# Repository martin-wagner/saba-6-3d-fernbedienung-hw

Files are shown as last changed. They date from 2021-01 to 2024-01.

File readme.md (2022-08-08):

### Saba Webradio

Das Saba Webradio erweitert ein Saba Automatic Radio um die folgenden Funktionen:
- W-Lan Webradio
- Steuerung von Automatik und Lautst"arke per Webinterface, MQTT, IR Fernbedienung ...
- Steuerung des Webradio per Radio Automatiktasten

Es kann direkt auf die Anschlussbuchse für die Fernbedienung aufgesteckt werden. Kompatibel sind mind. das Meersburg und Freiburg 6-3D. Am Gerät selbst sind keine Modifikationen notwendig (aber empfehlen). Der Audioausgang des Webradio wird mit dem TA Eingang des Radios verbunden und kann durch Wahl des zugehörigen Eingangs am Radio verwendet werden.

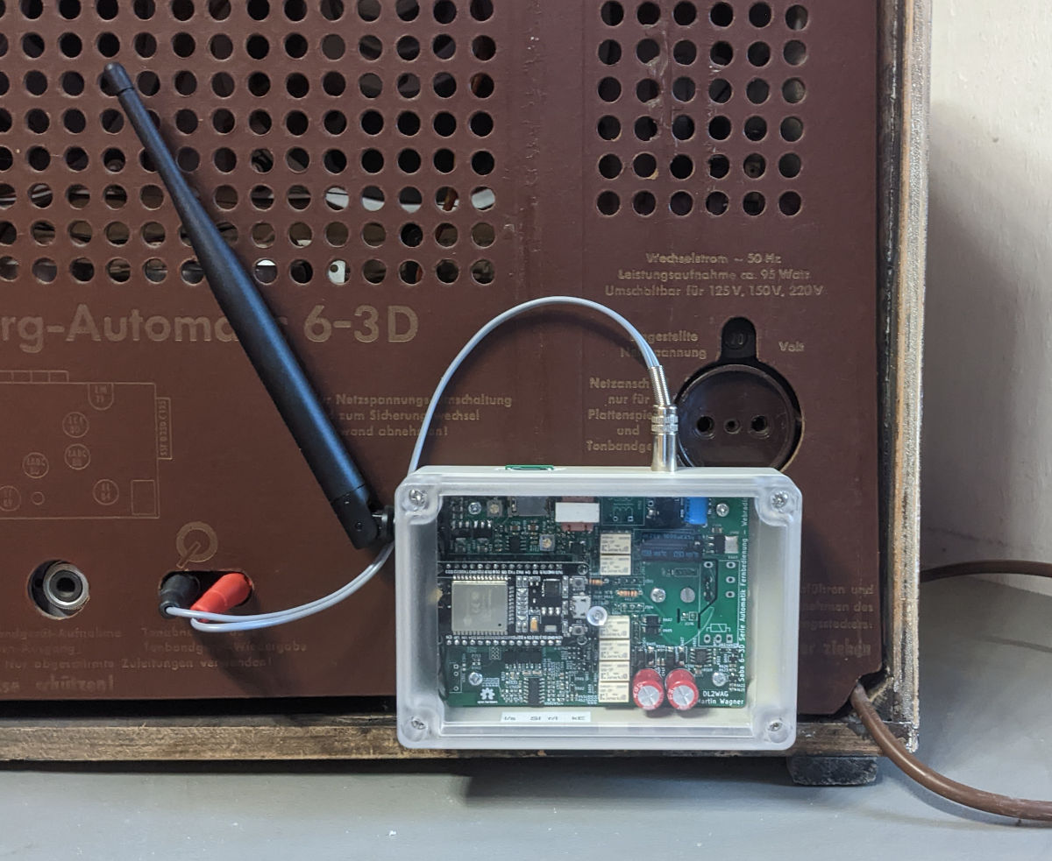
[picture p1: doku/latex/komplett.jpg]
Radio


Das Webradio basiert auf dem [ESP32-Radio Projekt von Ed Smallenburg](https://github.com/Edzelf/ESP32-Radio).

[Hardware](https://github.com/martin-wagner/saba-6-3d-fernbedienung-hw)

[Software](https://github.com/martin-wagner/ESP32-Radio)

[Doku](doku/latex/doku.pdf)

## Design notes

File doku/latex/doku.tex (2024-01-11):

\documentclass[ngerman,11pt,parskip=half] {scrartcl}

\usepackage{babel}

%
% Schrift
%
\usepackage[T1]{fontenc}
\usepackage{textcomp}
\usepackage[utf8]{inputenc}
\usepackage{eurosym}% 1 \euro oder \EUR{1}

\usepackage{helvet}
\renewcommand{\ttdefault}{pcr} %typewriter default font
\renewcommand{\familydefault}{\sfdefault}

%
% Layout
%
\usepackage[textwidth=16cm,head=4cm,bottom=3cm,a4paper]{geometry}
\usepackage{scrlayer-scrpage}
\pagestyle{scrheadings}
%\chead{}\ihead{}\ohead{}
\cfoot{}\ifoot{\footnotesize \currfilepath}\ofoot{\footnotesize Seite \pagemark~von \pageref*{LastPage}} % pageref* -> kein klickbarer Link
\renewcommand*{\footfont}{\normalfont}%nicht kursiv

\usepackage{lastpage}
\usepackage[table]{xcolor}
\usepackage{multicol}
\usepackage{rotating}
\usepackage{graphicx}
\usepackage{setspace}
\linespread{1.1}%zeilenabstand default global
\usepackage{array}
\usepackage{longtable}
\usepackage{ltxtable}
\setlength\LTleft{0pt}
\setlength\LTright\fill
\usepackage{tikz}
\usepackage{ctable}
\newcommand{\otoprule}{\midrule[\heavyrulewidth]}
\usepackage{hhline}
\usepackage{cals}
\usepackage{enumitem}% f"ur besseres itemize
\setitemize{label=\textminus,itemsep=0pt,topsep=0.5ex,after=\vspace{\baselineskip}}
\usepackage{float} %bilderpositionierung
%\usepackage{textgreek}
\usepackage{sansmath}
\usepackage{listings}
\lstset{basicstyle=\footnotesize\ttfamily,breaklines=true}
\lstset{framextopmargin=50pt,frame=bottomline}

% Funktion zum Generieren des Dateipfades. Kann leider nicht den absoluten Pfad finden...
\usepackage{currfile}

% Zeit
\usepackage{datetime}

%
% Funktionen
%
% fettes rotes todo
\newcommand {\todo} {\textbf{\color{red} todo\ }}
% Gr"o"se eines Oszillogramms
\newcommand {\tscopesize}{12cm}

% Links, Querverweise, Titel
\usepackage[
  colorlinks=true,
  linkcolor=black,
  urlcolor=black,
  pdftitle={Schaltungsbeschreibung}, %PDF Beschreibung
  allcolors=black,
]{hyperref} %immer zum Schluss

%
% Dokument
%
\begin{document}
\sansmath

% Titelseite

\thispagestyle{empty}

\mbox{}\\[2cm]%absolute L"ange

\textbf{\huge
Saba Webradio Hardware
}

\vfill

\hspace{1cm}\begin{tabular}{ll}
Autor: & 		Martin Wagner, DL2WAG\\
Dokumentart:&   Schaltungsbeschreibung, Messungen\\
Datum:&         \today \enspace \currenttime
\end{tabular}

\vfill
\begin{minipage}[t]{\textwidth}
\begin{spacing}{1.2}%zeilenabstand lokal 
  \begin{tabular}{p{.1\textwidth} p{.2\textwidth}  p{.6\textwidth}}%
  Version & Datum & Bemerkung        \\
  \hline  
  \hspace{.02\textwidth} 1  & 05.06.2022 & Neu   \\  
  \end{tabular}
\end{spacing}
\end{minipage}

\mbox{}\\[2cm]%absolute L"ange

% Inhaltsverzeichnis

\newpage
\tableofcontents

% eigentliches Dokument

\newpage

\section{Saba Webradio} \label{sec:sabawebradio}

Das Saba Webradio erweitert ein Saba Automatic Radio um die folgenden Funktionen:
\begin{itemize}
\item W-Lan Webradio
\item Steuerung von Automatik und Lautst"arke per Webinterface, MQTT, IR Fernbedienung ...
\item Steuerung des Webradio per Radio Automatiktasten
\end{itemize}
Es kann direkt auf die Anschlussbuchse f"ur die Fernbedienung aufgesteckt werden. Kompatibel sind mind. das Meersburg und Freiburg 6-3D. Am Ger"at selbst sind keine Modifikationen notwendig (aber empfehlen). Der Audioausgang des Webradio wird mit dem TA Eingang des Radios verbunden und kann durch Wahl des zugeh"origen Eingangs am Radio verwendet werden.

\begin{figure}[H]
\centering
\begin{tikzpicture}
.-     \node[anchor=south west,inner sep=0] at (0,0) {};
\end{tikzpicture}
\caption{Fertig montiertes Saba Webradio} \label{fig:1}
\end{figure}

Das Webradio basiert auf dem ESP32-Radio Projekt von Ed Smallenburg: \url{https://github.com/Edzelf/ESP32-Radio}.

Hardware: \url{https://github.com/martin-wagner/saba-6-3d-fernbedienung-hw}\\
Software: \url{https://github.com/martin-wagner/ESP32-Radio}

\section{Empfohlene Modifikationen} \label{sec:mod}

\subsection{Magisches Auge} \label{sec:mod:magischesauge}

Wird h"aufig die Webradiofunktion verwendet, sollte das magische Auge im TA Betrieb deaktiviert werden. Bei neueren Saba Ger"aten ist dies ab Werk der Fall, bei "alteren wie dem 6-3D wie folgt modifizieren:

\begin{figure}[H]
\centering
\begin{tikzpicture}
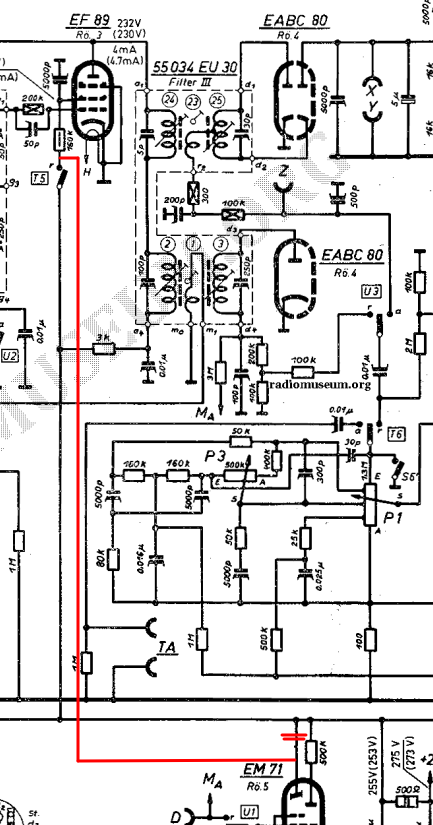
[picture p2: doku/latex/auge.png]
     \node[anchor=south west,inner sep=0] at (0,0) {};
\end{tikzpicture}
\caption{Schaltungsvorschlag} \label{fig:1}
\end{figure}

Um ein ggf. neu gekauftes Auge zu schonen kann bei diesem Umbau auch direkt ein Poti 1\,W 50\,kOhm in Serie eingeschleift werden. Je niedriger die Helligkeit eingestellt wird desto h"oher ist die Lebensdauer des Auges. Ohne Widerstand ist bei der verwendeten EM71 ein Abnutzungseffekt bereits nach wenigen Betriebsstunden (!!!) sichtbar.

\subsection{Erkennung TA aktiv} \label{sec:mod:erkennungta}

Das Webradio hat keine M"oglichkeit zu erkennen ob gerade normales Radio oder Webradio aktiv ist. Der Webradio Stream ist daher immer eingeschalten. Abgesehen von unn"utzer Daten"ubertragung f"uhrt die W-Lan Kommunikation zu St"orungen im Radioempfang bei schw"acheren Sendern. Soll dies vermieden werden kann das "`TA Aktiv"' Signal von der Gl"uhlampe der TA Taste abgegriffen und an die Fernbedienungsbuchse verdrahtet werden. Hierf"ur wird der freie Kontakt "`11"' verwendet.

\begin{figure}[H]
\centering
\begin{tikzpicture}
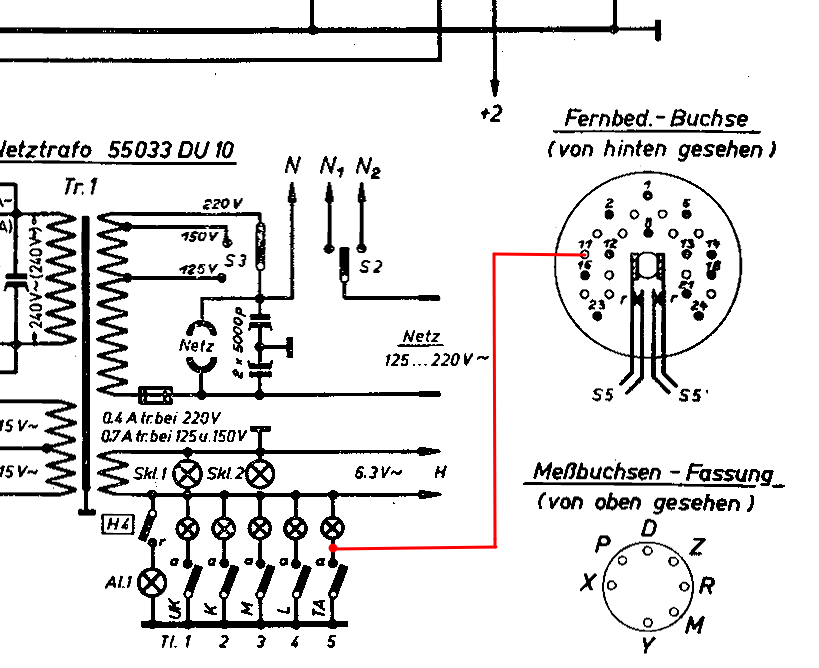
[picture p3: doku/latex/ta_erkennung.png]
     \node[anchor=south west,inner sep=0] at (0,0) {};
\end{tikzpicture}
\caption{Schaltungsvorschlag} \label{fig:1}
\end{figure}

Unbenutzte Kontakte sind leer, daher muss ein Kontaktstift aus einem Schlachtger"at entfernt werden. Alternativ kann die 230\,V Wechselschaltung geopfert und einer der zugeh"origen Kontaktstifte versetzt werden.

\begin{itemize}
\item Leitung abl"oten
\begin{figure}[H]
\centering
\begin{tikzpicture}
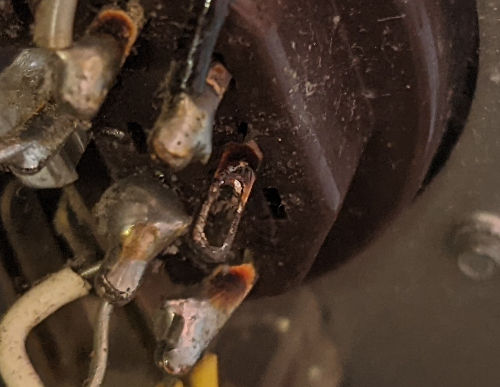
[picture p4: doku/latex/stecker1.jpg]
     \node[anchor=south west,inner sep=0] at (0,0) {};
\end{tikzpicture}
\caption{Kontakt ohne Leitung} \label{fig:1}
\end{figure}
\item L"ot"ose reinigen und geradebiegen
\begin{figure}[H]
\centering
\begin{tikzpicture}
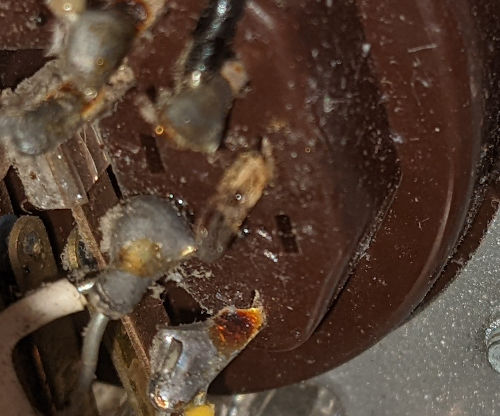
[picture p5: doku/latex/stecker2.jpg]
     \node[anchor=south west,inner sep=0] at (0,0) {};
\end{tikzpicture}
\caption{Kontakt gerade} \label{fig:1}
\end{figure}
\item Feder zur Ger"ate Au"senseite herausschieben
\begin{figure}[H]
\centering
\begin{tikzpicture}
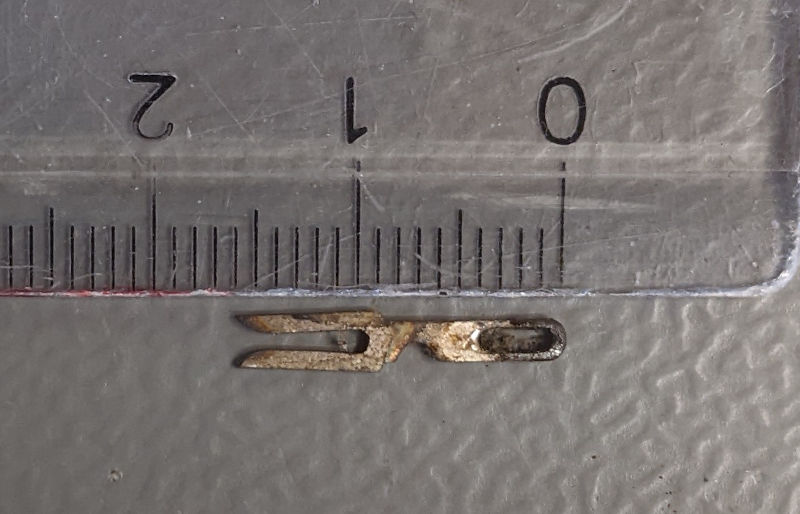
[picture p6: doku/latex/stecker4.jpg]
     \node[anchor=south west,inner sep=0] at (0,0) {};
\end{tikzpicture}
\caption{Kontaktstift} \label{fig:kontakt-feder}
\end{figure}
\item Umsetzen und Schaltung nach Vorgabe herstellen
\begin{figure}[H]
\centering
\begin{tikzpicture}
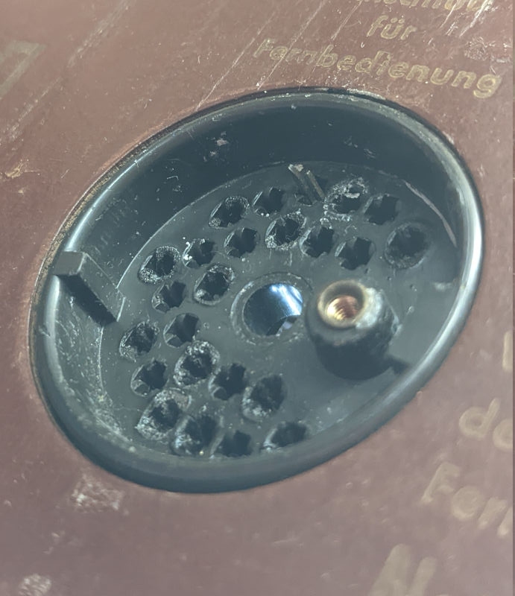
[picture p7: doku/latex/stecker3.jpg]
     \node[anchor=south west,inner sep=0] at (0,0) {};
\end{tikzpicture}
\caption{Kontakt an neuer Position} \label{fig:1}
\end{figure}
\begin{figure}[H]
\centering
\begin{tikzpicture}
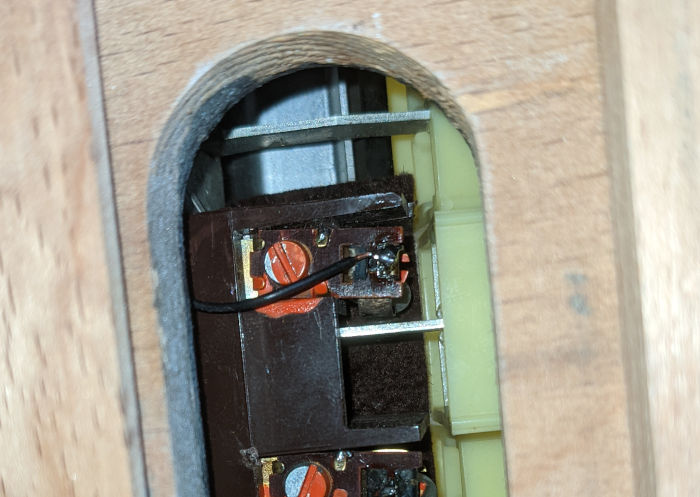
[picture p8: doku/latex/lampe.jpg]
     \node[anchor=south west,inner sep=0] at (0,0) {};
\end{tikzpicture}
\caption{Anschluss an Lampenfassung} \label{fig:1}
\end{figure}
\end{itemize}

\section{Aufbau} \label{sec:aufbau}

Die Schaltung ist auf drei Platinen aufgebaut:
\begin{itemize}
\item Anschlussstecker Radio
\item Webradio Steuerplatine
\item ESP32 Aufsteckplatine
\end{itemize}

Der Anschlussstecker wird "uber eine 2,54\,mm Stiftleiste mit der Steuerplatine verbunden. Dies erm"oglicht ein Anpassen des Steckers auf Ger"atetypen mit anderer Buchse. Das ESP32 wird einfach auf die Basisplatine aufgesteckt und kann bei Bedarf entfernt werden.

\subsection{Material} \label{sec:aufbau:material}

Deutsche Distris versenden nur an Kunden mit Steuernummer (Firma). Internationale Distris machen keine Unterscheidung. Ich habe daher alles was \emph{Reichelt} nicht hat bei Digikey in den USA bestellt. Alle Bauteile mit Herstellervorgabe, z.B. \emph{WE}, k"onnen von einem beliebigen Hersteller kommen, solange die Kenndaten eingehalten werden.

Folgendes Material wird ben"otigt:
\begin{itemize}
\item Bauteile nach "`stueckliste.csv"' f"ur Anschlussstecker und Basisplatine. Bauteile mit Markierung \emph{NP} (No Placement) werden i.d.R. nicht ben"otigt (siehe Rest der Anleitung).\\
Die erste H"alfte der Liste sind alle Bauteile einzeln mit Index, die zweite H"alfte die Summe der Bauteile.
\item Jeweils eine Platine Anschlussstecker und Steuerung. Anschlussstecker -- 2lagig, Steuerung -- 4lagig. Bestellen z.B. bei \emph{JLC-PCB}, die Platinen sind kleiner als 10\,cm x 10\, cm. Falls man Reflow L"oten will den Stencil gleich mitbestellen. Auf der Unterseite sind keine Bauteile.
\item 2x ESP32 DOIT-DEVKITV1-ESP32-WROOM-32. Bestellen z.B. bei Ebay. Es gibt ESP32 Boards auch mit zwei Pins mehr, daher Pinbelegung vergleichen! Der zweite ist  notwendig falls man vermutet den ersten zerst"ort zu haben.
\item VLSI VS1053B. Bestellen z.B. bei Digikey (teuer) oder Ebay direkt aus China (Risiko gef"alschte Chips zu bekommen). Ich habe bei Ebay bestellt und meine Lieferung war OK.
\item 2x Buchsenleiste 2,54mm 15pol, f"ur ESP32
\item 6x Stiftleiste 2,54mm 4pol, $l \geq 20mm$, f"ur Verbindung der beiden Platinen
\item Ausgangstrafo 600 Ohm, 1:1. Ebay, Suche nach \emph{transformer EI14}. Falls nicht zu bekommen kann auch ein anderer verwendet werden, siehe  \ref{sec:untersuchung:ausgangsuebertrager}.
\item Klinkenstecker 3,5\,mm + Audiokabel + 2x Bananenstecker.
\item Geh"ause Hammond RP1125C. Das exakt gleiche Geh"ause gibt es auch von anderen Herstellern.
\item Kunststoff- / Holzstab rund, $d=6\,mm$, ca. 5\,cm lang. Ein Bleistift funktioniert auch, bricht aber leicht ab.
\item Messingstab 3\,mm x 1,5\,mm, mind. ca. 30\,cm. Wenn man es bekommt ist 3\,mm x 1,2\,mm besser, ggf. geht auch 3\,mm x 1,0\,mm.
\item Ein Set SMD Widerst"ande 0603, wenn noch nicht vorhanden. Notwendig falls ein Widerstandswert angepasst werden muss. Ebay, Suche nach \emph{resistor kit 0603}.
\item Ggf. eine W-Lan Antenne.
\item Gut gef"ullte Teilekiste f"ur alles was ich vergessen habe.
\end{itemize}

\subsection{Anschlussstecker Radio} \label{sec:aufbau:anschlussstecker}

Wir brauchen:
\begin{itemize}
\item Platine
\item Messingstab
\item Holzstab
\end{itemize}

Aus dem Messingstab 13 Stifte mit je 15\,mm L"ange herstellen. Vorne zuspitzen so dass die Stifte in die "Offnung des Federkontakts passen (siehe Bild \ref{fig:kontakt-feder}). Mit dem 1,5\,mm Material werden die Federn etwas aufgebogen, 1,2\,mm sollten genau passen. Ggf. reicht auch 1,0\,mm aus, habe ich nicht probiert.

\begin{figure}[H]
\centering
\begin{tikzpicture}
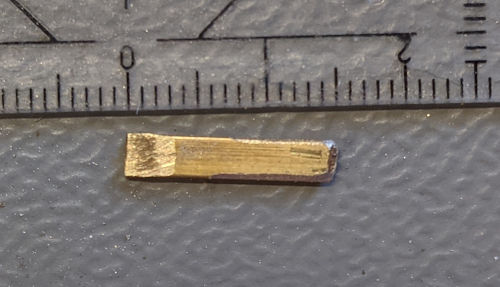
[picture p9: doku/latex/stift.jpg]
     \node[anchor=south west,inner sep=0] at (0,0) {};
\end{tikzpicture}
\caption{Kontaktstift} \label{fig:1}
\end{figure}

Die Stifte in die Kontaktfedern dr"ucken und danach die Platine aufsetzen. Ggf. Stifte etwas abrunden damit diese besser in die Platine passen. Stift 11 hat ggf. keine Feder, siehe \ref{sec:mod:erkennungta}. Falls Modifikation nicht durchgef"uhrt wird diesen Stift weglassen.

\begin{figure}[H]
\centering
\begin{tikzpicture}
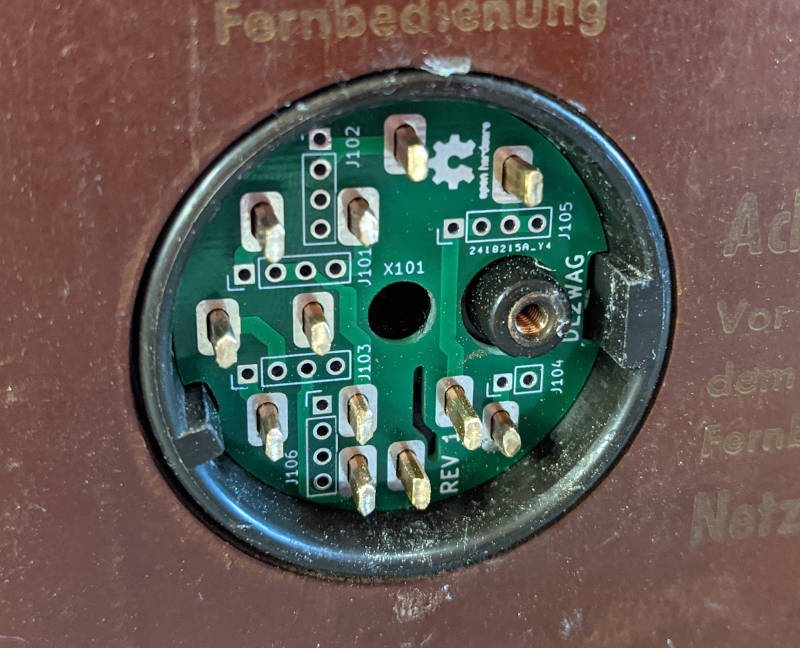
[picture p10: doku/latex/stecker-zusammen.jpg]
     \node[anchor=south west,inner sep=0] at (0,0) {};
\end{tikzpicture}
\caption{Stecker} \label{fig:1}
\end{figure}

Stifte in dieser Position verl"oten. Nur sehr kurz und mit hoher Leistung, sonst schmilzt der Kunststoff der Buchse! Mit Widerstandsmessger"at pr"ufen ob alle Stifte guten Kontakt zum jeweiligen Kontakt in der Buchse haben, ggf. nacharbeiten.

\begin{figure}[H]
\centering
\begin{tikzpicture}
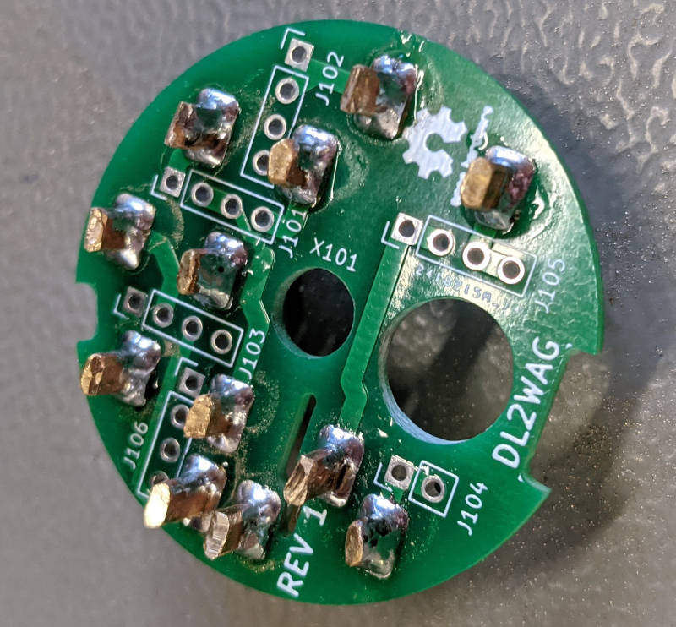
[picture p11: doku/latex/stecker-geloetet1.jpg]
     \node[anchor=south west,inner sep=0] at (0,0) {};
\end{tikzpicture}
\hspace{1cm} %no empty line!
\begin{tikzpicture}
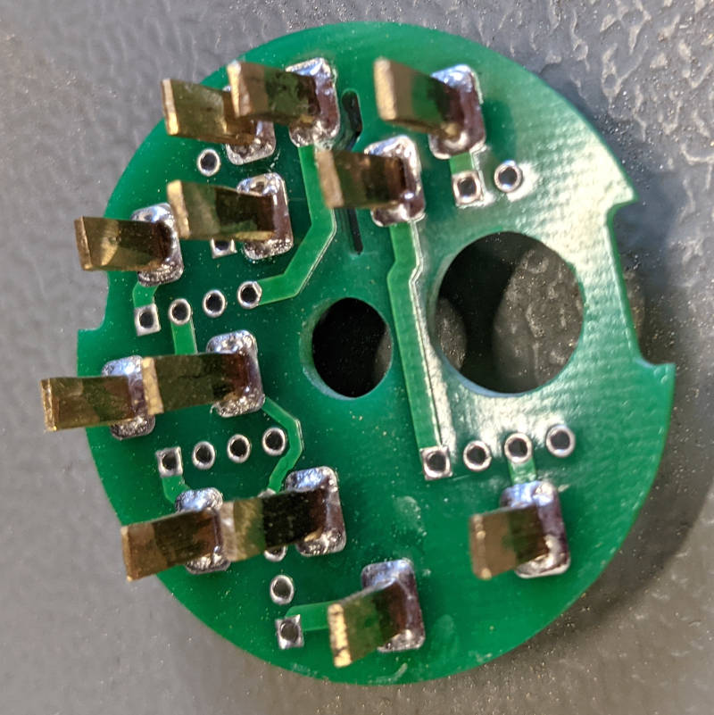
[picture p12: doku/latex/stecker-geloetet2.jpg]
     \node[anchor=south west,inner sep=0] at (0,0) {};
\end{tikzpicture}
\caption{Stecker gel"otet} \label{fig:1}
\end{figure}

Stiftleisten mit Platine verl"oten. Kunststoff so verschieben das die Stifte auf der Unterseite b"undig mit der Platine abschlie"sen (und der Stecker b"undig auf dem Kunststoff der Buchse aufsitzt). 

\begin{figure}[H]
\centering
\begin{tikzpicture}
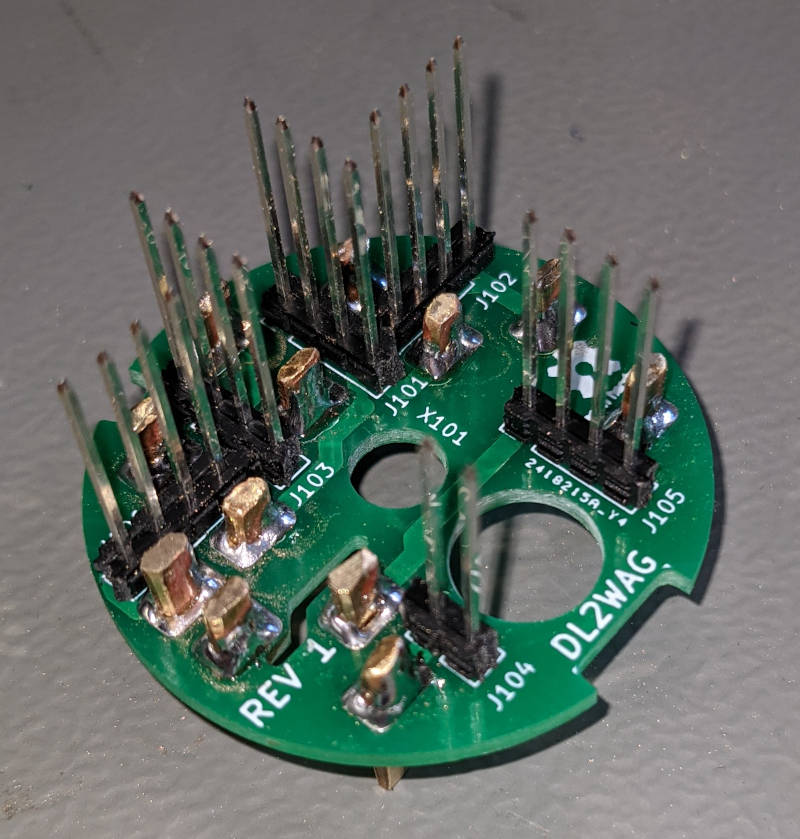
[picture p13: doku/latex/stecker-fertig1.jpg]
     \node[anchor=south west,inner sep=0] at (0,0) {};
\end{tikzpicture}
\hspace{1cm} %no empty line!
\begin{tikzpicture}
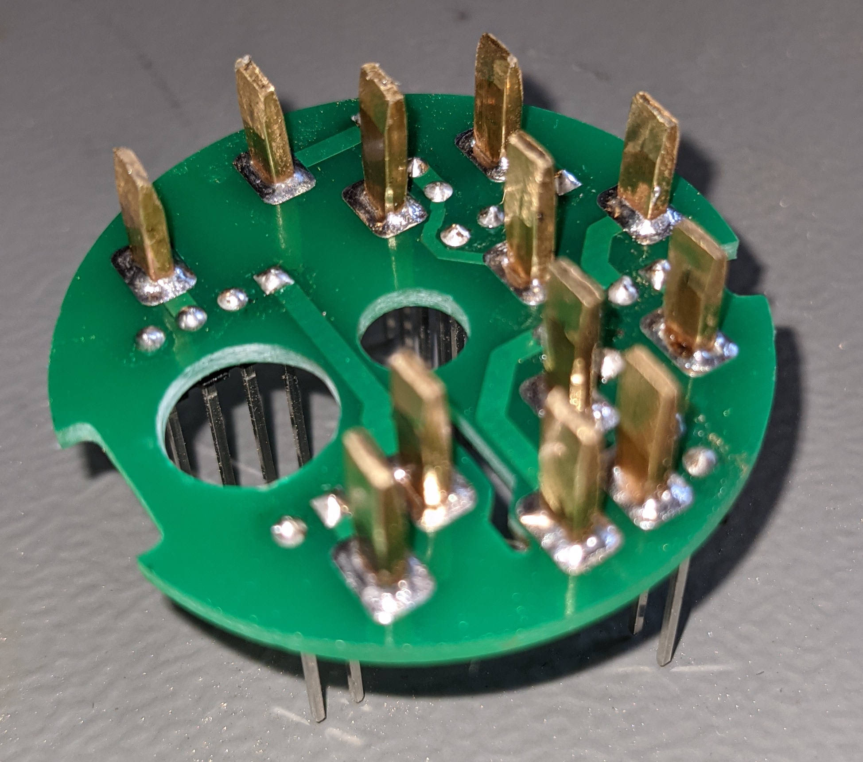
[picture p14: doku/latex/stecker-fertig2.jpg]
     \node[anchor=south west,inner sep=0] at (0,0) {};
\end{tikzpicture}
\caption{Stecker fertig} \label{fig:1}
\end{figure}

Holzstab auf ca. 4,5\,cm k"urzen und vorne mit Bleistifspitzer anspitzen. Hinten Loch f"ur Schraube bohren.

\begin{figure}[H]
\centering
\begin{tikzpicture}
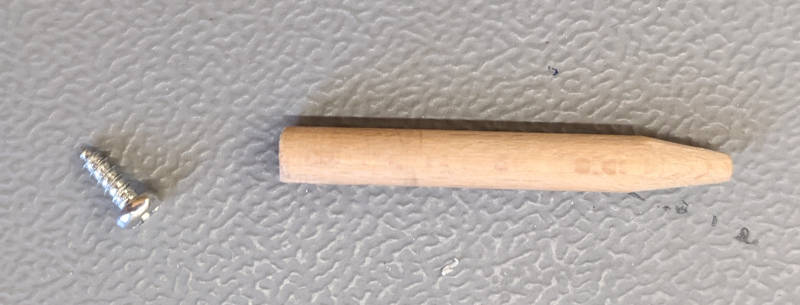
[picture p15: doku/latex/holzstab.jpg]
     \node[anchor=south west,inner sep=0] at (0,0) {};
\end{tikzpicture}
\caption{Zentrierstift} \label{fig:1}
\end{figure}

Der Stift muss durch das Loch in der Mitte des Steckers passen und wird auf die Steuerplatine aufgeschraubt.

\subsection{Steuerung} \label{sec:aufbau:steuerung}

Wir brauchen:
\begin{itemize}
\item Platine
\item Bauteile
\end{itemize}

Zuerst nicht ben"otigte herausstehende St"ucke der Platine abs"agen (USB und ggf. SD Karte). Dann kleine Bauteile aufl"oten (IC und ggf. SD Karte).

\begin{figure}[H]
\centering
\begin{tikzpicture}
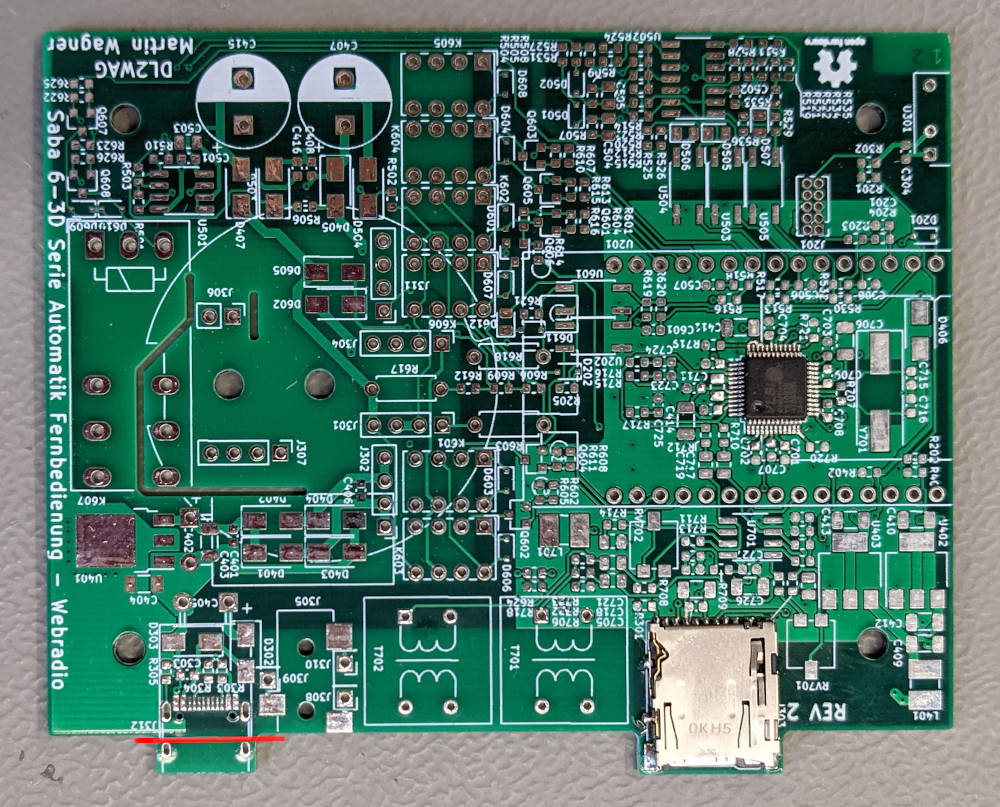
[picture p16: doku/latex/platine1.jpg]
     \node[anchor=south west,inner sep=0] at (0,0) {};
\end{tikzpicture}
\caption{Best"uckung kleine SMD Bauteile} \label{fig:1}
\end{figure}

Den Rest der Bauteile nacheinander best"ucken, beginnend um IC herum. "`NP"' Bauteile beachten (nicht best"ucken!). Kontakt 230\,V AC auf N1 oder N2 br"ucken, siehe \ref{sec:schaltung:steuern-radio}.

\begin{figure}[H]
\centering
\begin{tikzpicture}
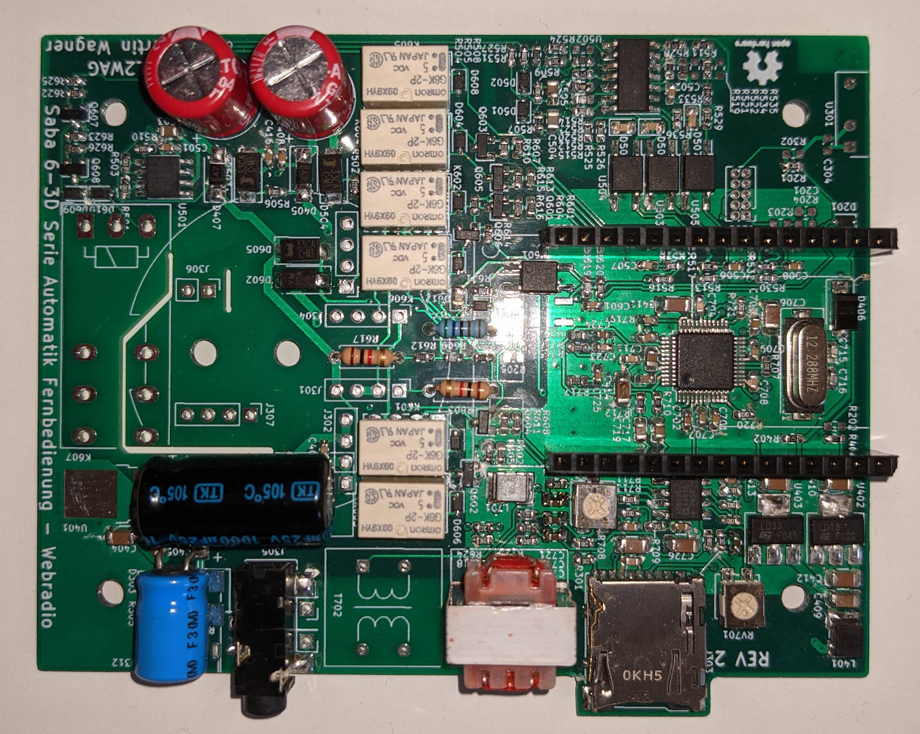
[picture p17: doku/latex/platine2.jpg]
     \node[anchor=south west,inner sep=0] at (0,0) {};
\end{tikzpicture}
\caption{Best"uckung fertig} \label{fig:1}
\end{figure}

\subsection{Montage} \label{sec:aufbau:montage}

Geh"ause f"ur Montage der Platine und Stecker vorbereiten. Der Mittelpunkt des Stecker Bohrlochs kann durch das Loch f"ur den Zentrierstift auf der Steuerplatine angezeichnet werden. Das Loch sollte so gro"s sein das der Stecker durchpasst (um die Baugruppe im sp"ateren Verlauf herausnehmen zu k"onnen).

\begin{figure}[H]
\centering
\begin{tikzpicture}
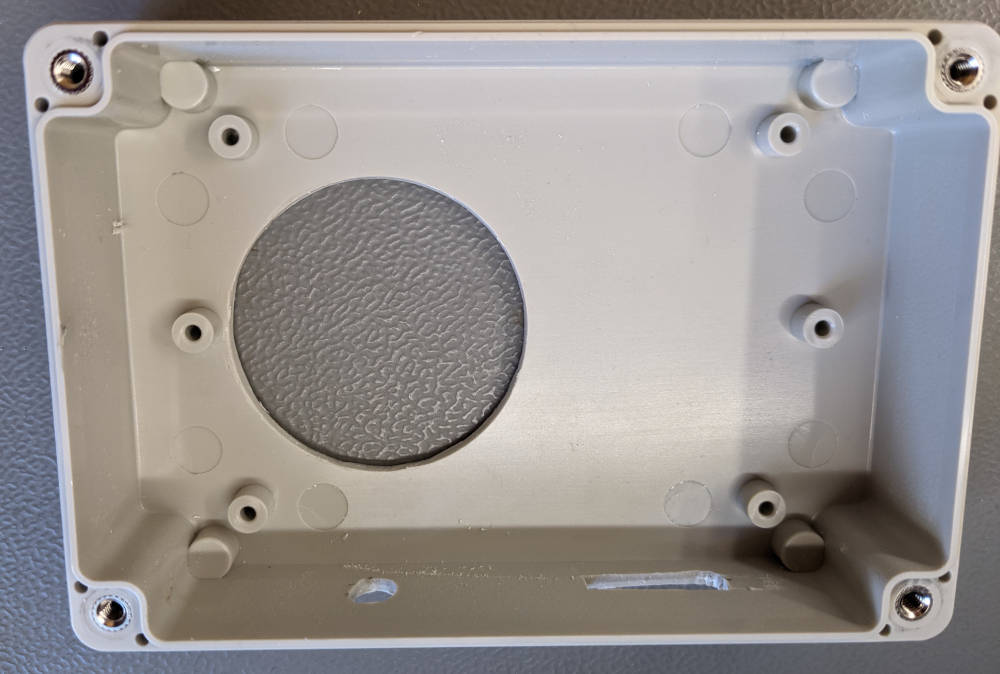
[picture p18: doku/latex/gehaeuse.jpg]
     \node[anchor=south west,inner sep=0] at (0,0) {};
\end{tikzpicture}
\caption{Geh"ause} \label{fig:1}
\end{figure}

Stecker in Buchse einstecken, Geh"ause mit montierter Steuerplatine b"undig aufsetzen. Stifte einrasten und verl"oten.

\begin{figure}[H]
\centering
\begin{tikzpicture}
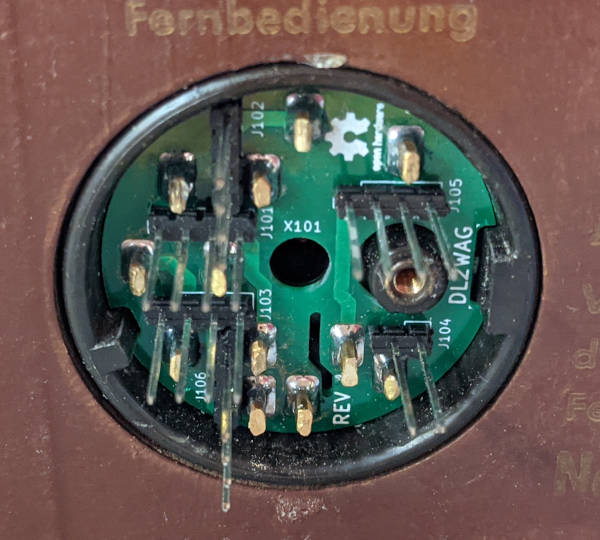
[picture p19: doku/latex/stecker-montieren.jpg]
     \node[anchor=south west,inner sep=0] at (0,0) {};
\end{tikzpicture}
\hspace{1cm} %no empty line!
\begin{tikzpicture}
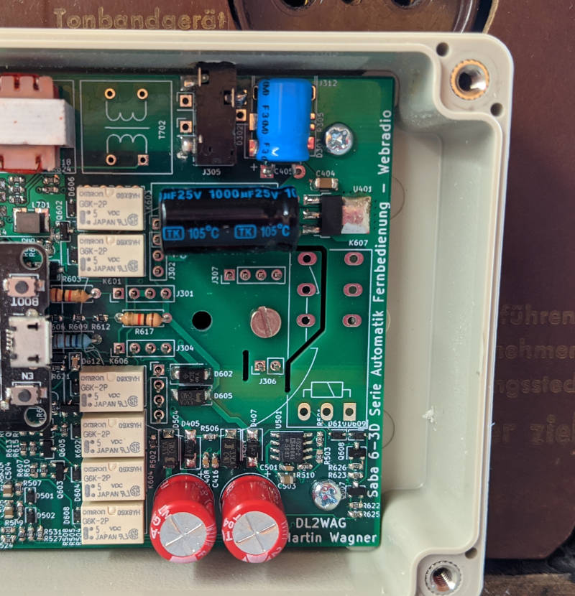
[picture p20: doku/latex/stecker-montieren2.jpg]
     \node[anchor=south west,inner sep=0] at (0,0) {};
\end{tikzpicture}
\caption{Stecker fertig} \label{fig:1}
\end{figure}

Zuletzt wird der Zentrierstift auf der Steuerplatine verschraubt.

\begin{figure}[H]
\centering
\begin{tikzpicture}
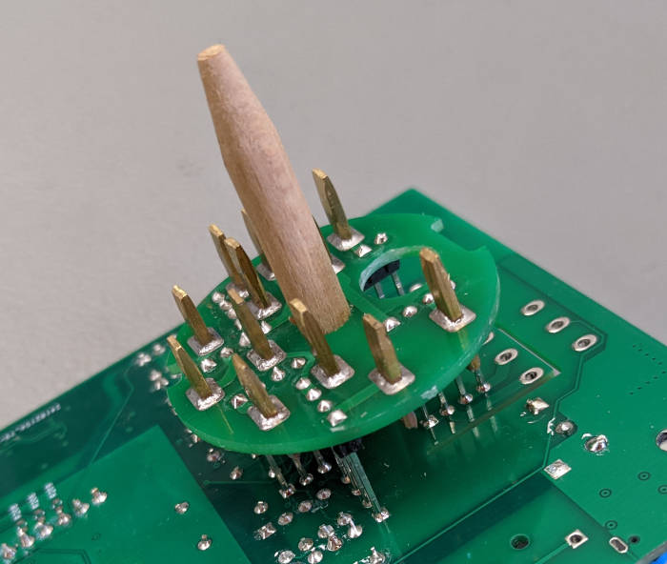
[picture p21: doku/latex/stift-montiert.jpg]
     \node[anchor=south west,inner sep=0] at (0,0) {};
\end{tikzpicture}
\caption{Zentrierstift im Stecker} \label{fig:1}
\end{figure}

Die gesamte Baugruppe kann jetzt nach dem Einstecken auf der Anschlussbuchse festgeschraubt werden. Vorsichtig, da Platine nicht auf der Buchse aufliegt.

\subsection{Inbetriebnahme / Test} \label{sec:aufbau:inbetriebnahme}

Die Steuerplatine sollte vor der Montage auf korrekte Funktion gepr"uft werden. Die einzelnen Schaltungsteile werden unabh"angig voneinander betrachtet.

\textbf{Spannungsversorgung Mikrocontroller}

Die Versorgung wird aus der Heizspannung 6,3\,V durch Vollweggleichrichtung + darauffolgend 5\,V Linearregler gewonnen. Folgende Spannungen stehen zur Verf"ugung\footnote{Siehe Schaltplan Seite 3}:
\begin{itemize}
\item ca. 8\,V
\item 5,0\,V
\item 3,3\,V Digital (werden vom ESP32 ausgegeben)
\item 1,8\,V Digital
\item 3,3\,V Analog
\end{itemize}

\textbf{Spannungsversorgung Suchlauf}

Die Versorgung wird aus der 2x15\,V Spannungsversorgung f"ur den Suchlauf durch Einweggleichrichtung gewonnen. Folgende Spannungen stehen zur Verf"ugung:
\begin{itemize}
\item ca. +/- 20\,V
\end{itemize}

\begin{figure}[H]
\centering
\begin{tikzpicture}
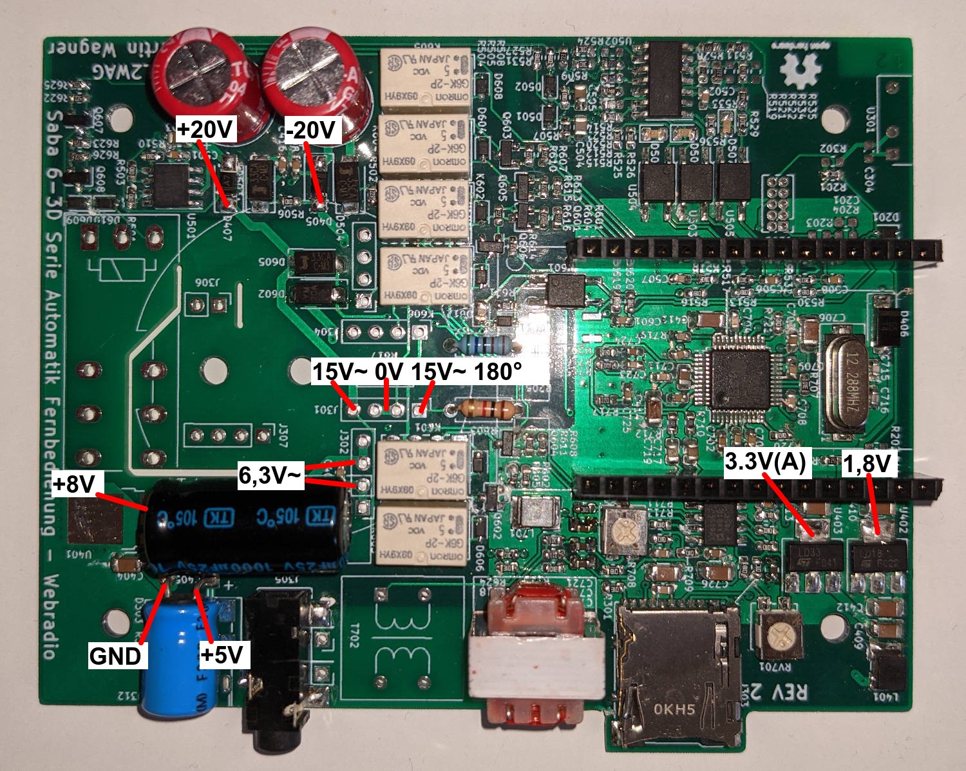
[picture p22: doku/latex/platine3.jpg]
     \node[anchor=south west,inner sep=0] at (0,0) {};
\end{tikzpicture}
\caption{DC Spannungen Messpunkte} \label{fig:1}
\end{figure}

\textbf{Suchlauf Operationsverst"arker / Komparatoren}

Versorgungsspannung 2x15\,V AC -- +/-20\,V. Die Comparatoren sind auf eine Versorgungsspannung von 22\,V berechnet. Da in der Schaltung Spannungsverh"altnisse verglichen werden sind die berechneten Schaltschwellen nur bei dieser Spannung g"ultig. Bei anderen Versorgungsspannungen verschieben sich die Schaltpunkte proportional zur Versorgungsspannung.

Alle Messungen mit Bezug auf die Mittelanzapfung der 15\,V Wicklung, nicht Masse des Radios! Beim Messen aufpassen das nicht versehentlich die verschiedenen Massepotentiale verbunden werden! Suchlauftaste am Ger"at bet"atigen (Suchlauf aus) oder Suchlaufschaltung auf Breadboard nachbauen.

\begin{figure}[H]
\centering
\begin{tikzpicture}
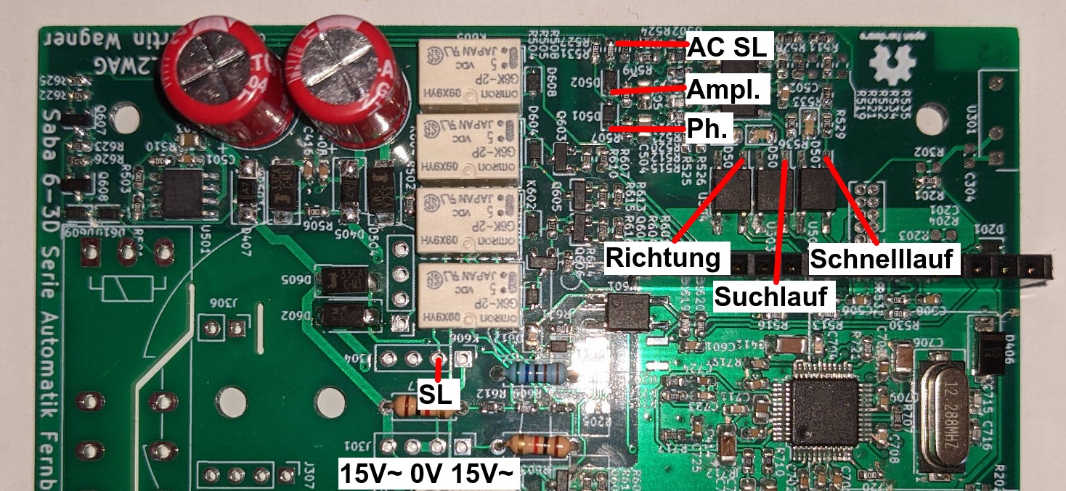
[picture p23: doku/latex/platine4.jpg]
     \node[anchor=south west,inner sep=0] at (0,0) {};
\end{tikzpicture}
\caption{AC Messpunkte} \label{fig:1}
\end{figure}

\begin{figure}[H]
\centering
\begin{tikzpicture}
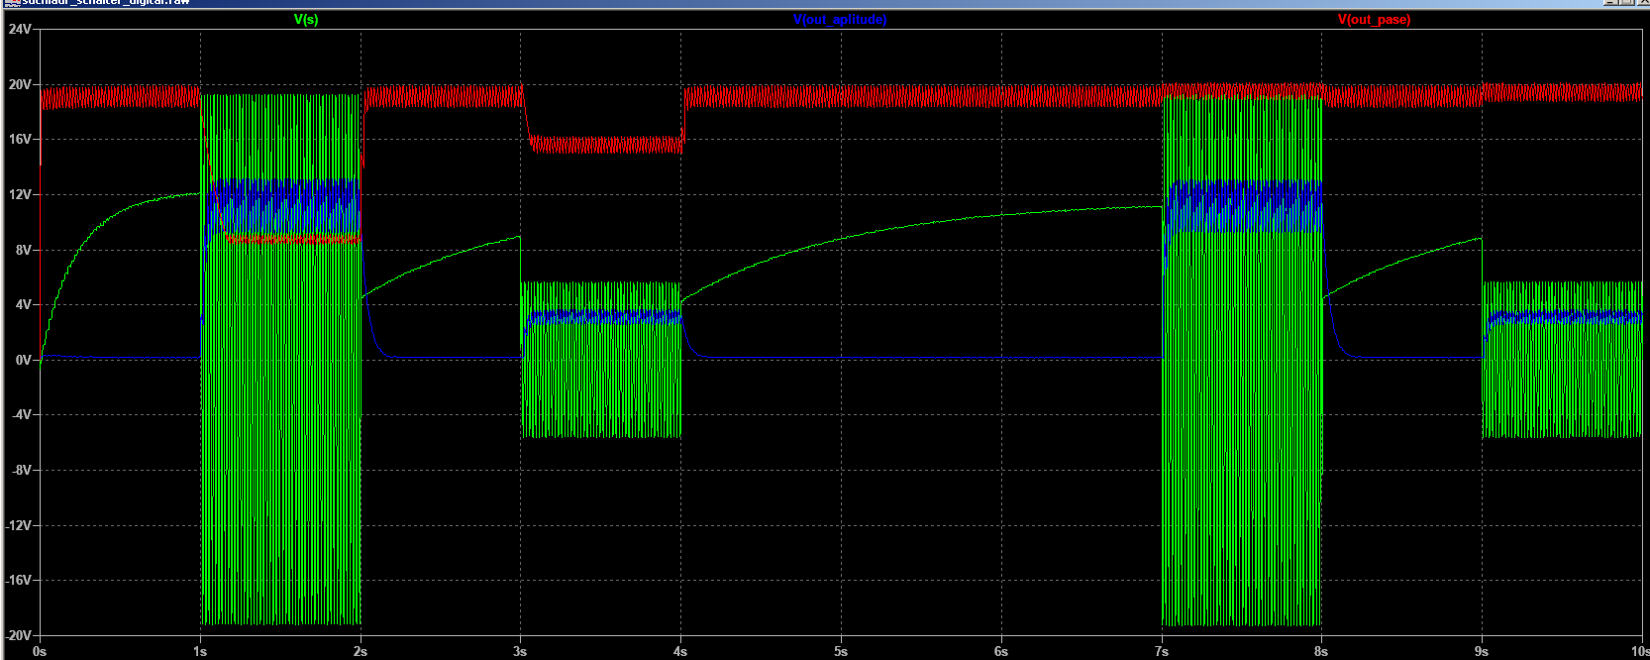
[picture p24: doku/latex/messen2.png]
     \node[anchor=south west,inner sep=0] at (0,0) {};
\end{tikzpicture}
\caption{Spannungen in Simulation} \label{fig:1}
\end{figure}

\textbf{Messungen Signal Laufrichtung}

\begin{figure}[H]
\centering
\begin{tikzpicture}
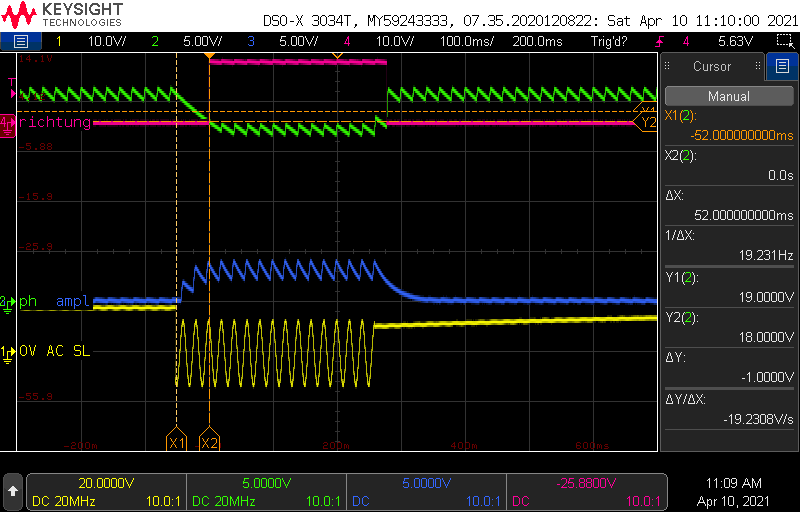
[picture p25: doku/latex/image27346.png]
     \node[anchor=south west,inner sep=0] at (0,0) {};
\end{tikzpicture}
\caption{Laufrichtung 1, suchen} \label{fig:1}
\end{figure}

\begin{figure}[H]
\centering
\begin{tikzpicture}
     \node[anchor=south west,inner sep=0] at (0,0) {};
\end{tikzpicture}
\caption{Laufrichtung 2, suchen} \label{fig:1}
\end{figure}

\begin{figure}[H]
\centering
\begin{tikzpicture}
     \node[anchor=south west,inner sep=0] at (0,0) {};
\end{tikzpicture}
\caption{Laufrichtung 1, schnell} \label{fig:1}
\end{figure}

\begin{figure}[H]
\centering
\begin{tikzpicture}
     \node[anchor=south west,inner sep=0] at (0,0) {};
\end{tikzpicture}
\caption{Laufrichtung 2, schnell} \label{fig:1}
\end{figure}

Die Laufrichtung muss korrekt erkannt werden. Die Verz"ogerung muss im Bereich bis max. ca 50\,ms sein. Beim Schnelllauf wird zuerst der Kontakt f"ur den Suchlauf geschlossen, bereits dieser f"uhrt zur Erkennung.

\textbf{Signal Laufrichtung im Bereich der zul"assigen Versorgungsspannung}

Die Versorgungsspannung f"ur den Schaltungsteil ist nicht stabilisiert und schwankt daher in Abh"angikeit der Netzspannung.

Sweep Versorgungsspannung +/- 10\,V ... 18\,V AC. 

\begin{figure}[H]
\centering
\begin{tikzpicture}
     \node[anchor=south west,inner sep=0] at (0,0) {};
\end{tikzpicture}
\caption{Laufrichtung 1, suchen} \label{fig:1}
\end{figure}

Das digitale Signal steht im gesamten Versorgungsspannungsbereich korrekt an. 

\textbf{Messungen Signal Schnelllauf}

\begin{figure}[H]
\centering
\begin{tikzpicture}
     \node[anchor=south west,inner sep=0] at (0,0) {};
\end{tikzpicture}
\caption{suchen} \label{fig:1}
\end{figure}

\begin{figure}[H]
\centering
\begin{tikzpicture}
     \node[anchor=south west,inner sep=0] at (0,0) {};
\end{tikzpicture}
\caption{schnelllauf} \label{fig:1}
\end{figure}

Der Schnelllauf muss korrekt erkannt werden. Die Verz"ogerung muss im Bereich bis max. ca 50\,ms sein. 

\textbf{Signal Schnelllauf im Bereich der zul"assigen Versorgungsspannung}

Sweep Versorgungsspannung +/- 10\,V ... 18\,V AC. 

\begin{figure}[H]
\centering
\begin{tikzpicture}
     \node[anchor=south west,inner sep=0] at (0,0) {};
\end{tikzpicture}
\caption{suchen} \label{fig:1}
\end{figure}

\begin{figure}[H]
\centering
\begin{tikzpicture}
     \node[anchor=south west,inner sep=0] at (0,0) {};
\end{tikzpicture}
\caption{schnelllauf} \label{fig:1}
\end{figure}

Das digitale Signal steht im gesamten Versorgungsspannungsbereich korrekt an. 

\textbf{Haltespule}

Die Funktion der "`Haltespule"' kann durch das Anlegen von ca. 35\,V AC getestet werden.

\begin{figure}[H]
\centering
\begin{tikzpicture}
     \node[anchor=south west,inner sep=0] at (0,0) {};
\end{tikzpicture}
\caption{Haltespule} \label{fig:1}
\end{figure}

Der digitale Eingang muss bei ca. 30\,V / 5\,mA umschalten.

\textbf{Digitale Signale Mikrocontroller}

Die Signale am ESP32 k"onnen auf zwei M"oglichkeiten getestet werden:
\begin{itemize}
\item Spannungsquelle (Relais) + Multimeter (Eing"ange) anstelle des ESP32 an der Stiftleiste anschlie"sen
\item ESP32 + Arduino Testsoftware\footnote{Verzeichnis "`software/test"', aufspielen wie in \ref{sec:aufbau:programmierung} "`Arduino"'}
\end{itemize}

Signale nacheinander anlegen, es muss der zugeh"orige Eingang umschalten bzw. das zugeh"orige Relais schalten.

\textbf{Webradio / Audio Mikrocontroller}

Nicht vorab m"oglich. Nachdem ESP32 programmiert ist kann das Webradio wie in \ref{sec:bedienung}. beschrieben benutzt werden, an die Klinkenbuchse kann ein Kopfh"orer, PC Lautsperecher o."a. angeschlossen werden.

\subsection{Programmierung ESP32} \label{sec:aufbau:programmierung}

Der ESP32 Controller kann sowohl auserhalb wie auch in der Schaltung programmiert werden. Im letzten Fall ist \textbf{\color{red} penibelst} darauf zu achten dass das Ger"atechassis nicht geerdet ist. Grund: Der Schaltungs GND entspricht nicht dem Radio GND (Chassis), siehe Steuerplatine\footnote{Seite 4, Spannungsversorgung 5\,V}. Werden beide "uber das USB Programmierkabel verbunden entsteht ein Kurzschluss.

\textbf{M"oglichkeit 1: Kommandozeile, Python -- esptool.py}

Funktionierende Pythoninstallation mit \emph{pip} wird vorrausgesetzt. Sollte dann mit allen Betriebssystemen etwa gleich funktionieren. Normalerweise erkennt \emph{esptool.py} automatisch die richtige Schnittstelle, falls nicht kann man nachhelfen mit \emph{-{}-port /dev/ttyUSBx} (Linux) oder \emph{-{}-port COMx} (Windows).

Vorcompilierte Binaries sind im Verzeichnis "`software/bin"' abgelegt.

\begin{itemize}
\item \texttt{\$ pip install esptool}
\item ESP Board mit PC USB verbinden
\item Verbindung testen und ggf. vorhandene Altlasten entfernen:\\
		\texttt{\$ esptool.py erase\_flash}
\item Bootloader und Firmware programmieren:\\
		\texttt{\$ esptool.py --chip esp32  --baud 921600 --before default\_reset --after hard\_reset write\_flash -z --flash\_mode dio --flash\_freq 80m --flash\_size detect 0xe000 boot\_app0.bin 0x1000 bootloader\_dio\_80m.bin 0x10000 \\ESP32\_Radio.bin 0x8000 ESP32\_Radio.partitions.bin}
\end{itemize}

Ein Firmwareupdate kann einfach durch erneutes Aufrufen des Programmierkomandos durchgef"uhrt werden. Die Einstellungen bleiben dann erhalten.

\emph{\href{https://docs.espressif.com/projects/esptool/en/latest/esp32s3/esptool/index.html}{esptool.py Dokumentation}}. Die Kommandozeilenbefehle werden beim Compilieren / Hochladen durch die Arduino Umgebung ausgegeben.

\textbf{M"oglichkeit 2: Kommandozeile, PlatformIO}

In 2024 einfachste M"oglichkeit zu compilieren. Auch hier wird eine funktionierende Pythoninstallation vorrausgesetzt.

\begin{itemize}
\item Installieren nach \url{https://docs.platformio.org/en/latest/core/installation/methods/index.html}. Inklusive "`Install Shell Commands"'.
\item Sourcecode von der in \ref{sec:sabawebradio}. "`Software"' angegebenen URL herunterladen.
\item Ins Download Verzeichnis wechseln
\item Projekt vorbereiten:\\
		\texttt{\$ pio project init --board esp32doit-devkit-v1}
\item Projekt compilieren und "ubertragen:\\
		\texttt{\$ pio run upload}
\end{itemize}

\textbf{M"oglichkeit 3: Eclipse IDE}

Falls man ernsthaft etwas am Sourcecode "andern will empfehle ich ausdr"ucklich eine richtige IDE zu verwenden (Eclipse, VS-Code, ...).

\begin{itemize}
\item Wie "`PlatformIO".
\item Projekt vorbereiten:\\
		\texttt{\$ pio project init  --ide eclipse --board esp32doit-devkit-v1}
\item In Eclipse importieren nach \url{https://docs.platformio.org/en/latest/integration/ide/eclipse.html}. Verh"alt sich wie ein normales Eclipse Projekt.
\end{itemize}

\section{Bedienung} \label{sec:bedienung}

Webradio hinten auf Anschlusstecker aufstecken und mit Schraube festschrauben. Geh"ausedeckel aufschrauben. Audiokabel mit TA Buchsen verbinden.

\subsection{W-Lan Anmeldung} \label{sec:bedienung:wlan}

Bei der ersten Inbetriebnahme, oder falls das eingestellte W-Lan nicht erreichbar ist, "offnet der ESP32 ein offenes W-Lan Netz. Darin einloggen, IP \emph{192.168.4.1} im Webbrowser "offnen.

\begin{figure}[H]
\centering
\begin{tikzpicture}
     \node[anchor=south west,inner sep=0] at (0,0) {};
\end{tikzpicture}
\caption{Startseite} \label{fig:1}
\end{figure}

Bis zum Ende scrollen, Knopf "`Default"' dr"ucken.

\begin{figure}[H]
\centering
\begin{tikzpicture}
     \node[anchor=south west,inner sep=0] at (0,0) {};
\end{tikzpicture}
\caption{Defaults} \label{fig:1}
\end{figure}

Feld \emph{wifi\_00} W-Lan Namen und Passwort eingeben. "`Save"', "`Restart"' dr"ucken. Das Passwort wird auf dem ESP32 unverschl"usselt gespeichert!

\begin{figure}[H]
\centering
\begin{tikzpicture}
     \node[anchor=south west,inner sep=0] at (0,0) {};
\end{tikzpicture}
\caption{Passwort} \label{fig:1}
\end{figure}

Danach sollte sich der ESP32 im vorgegebenen W-Lan anmelden. Falls nicht, Terminalprogramm auf der USB seriellen Schnittstelle "offnen und Debugausgaben auswerten. Website aufrufen mit IP des ESP32 oder z.B. \emph{\href{http://esp32-arduino.fritz.box}{http://esp32-arduino.fritz.box}} falls man eine Fritzbox hat.\\
Das W-Lan wird immer ge"offnet wenn sich der ESP32 nicht in eines der vorgegebenen Netze einloggen kann.

\subsection{Webradio} \label{sec:bedienung:webradio}

Taste \textbf{TA} am Radio dr"ucken.

\textbf{Bedienung am Radio}

"Uber den Wippschalter der Automatik k"onnen am Webradio die Stationen ausgew"ahlt werden, wie im normalen Radiobetrieb. Die Automatiktaste kann bet"atigt ($\rightarrow$ Automatik Aus) sein.

\begin{itemize}
\item Wippschalter ganz links $\rightarrow$ Station "`1"' ausw"ahlen
\item Wippschalter links tippen $\rightarrow$ vorherige Station
\item Wippschalter rechts tippen $\rightarrow$ n"achste Station
\item Wippschalter ganz rechts $\rightarrow$ \todo nicht belegt
\end{itemize}

\textbf{Bedienung Webinterface}

Nach dem "Offnen der Webseite stehen alle Grundfunktionen zur Verf"ugung.

\begin{figure}[H]
\centering
\begin{tikzpicture}
     \node[anchor=south west,inner sep=0] at (0,0) {};
\end{tikzpicture}
\caption{Webradio} \label{fig:1}
\end{figure}

Im Feld "`Enter a station/file here..."' kann die URL einer Radiostation angegeben und mit \emph{Play} gestartet werden. Geht nur ohne Protokollangabe (http://der URL weglassen). Es k"onnen nur unverschl"usselte Stationen wiedergegeben werden (kein https://). Die meisten Stationen unterst"utzen unverschl"usselte "Ubertragung, auch wenn es nicht explizit angegeben ist.

"Uber den Reiter \emph{Search} steht eine nach Musikrichtung sortierte Auswahl an Radiostationen zur Verf"ugung. Ausw"ahlen durch Anklicken, danach wird der Stream gestartet. Nicht alle funktionieren immer.

\subsection{Fernbedienung} \label{sec:bedienung:fernbedienung}

Rundfunkband am Radio ausw"ahlen. Webseite Reiter \emph{Remote} ausw"ahlen.

\begin{figure}[H]
\centering
\begin{tikzpicture}
     \node[anchor=south west,inner sep=0] at (0,0) {};
\end{tikzpicture}
\caption{Fernbedienung} \label{fig:1}
\end{figure}

Bedienung entspricht dem Wippschalter am Ger"at. \textbf{|<} und \textbf{>|} starten einen Suchlauf. Falls aktueller Sender nicht verlassen wird die Taste gedr"uckt halten bis Sender verlassen wurde (so wie am Ger"at auch...).

\subsection{Einstellungen} \label{sec:bedienung:einstellungen}

Webseite Reiter \emph{Config} ausw"ahlen.

Es k"onnen die folgenden Einstellungen ge"andert werden:
\begin{itemize}
\item Uhrzeit / NTP
\item MQTT IoT 
\item Voreingestellte Radiosender. Diese Liste wird mit dem Wippschalter / dem \emph{Control} Reiter zur Verf"ugung gestellt
\item W-Lan Nutzer / Passwort
\end{itemize}

\begin{figure}[H]
\centering
\begin{tikzpicture}
     \node[anchor=south west,inner sep=0] at (0,0) {};
\end{tikzpicture}
\caption{Konfiguration} \label{fig:config}
\end{figure}

Einstellunge "ubernehmen mit "`Save"', "`Restart"'.

\subsection{Weitere Funktionen}

Weitere Funktionen sind in der Dokumentation des ESP32-radio Projekts beschrieben.

\subsection{OTA Firmwareupdate}

Webseite Reiter \emph{Config} ausw"ahlen. \emph{Update} dr"ucken, siehe Bild \ref{fig:config}. Es wird die Datei \url{http://martinwag.atwebpages.com/ESP32_radio/firmware.bin} gepr"uft, heruntergeladen und ins Flash geschrieben\footnote{Download per HTTP. Keine Verschl"usselung, keine Authentifizierung, etc. .}. Das Kommando wird im Textfeld best"atigt, eine Erfolgsmeldung gibt es nicht. Sp"atestens nach ein paar Minuten sollte das Update fertig sein, im Reiter \emph{About} sollte eine neues Builddatum auftauchen (oder auch nicht falls kein Update verf"ugbar ist). 

Die Einstellungen werden beim Update beibehalten.

MD5 Version "`Build: 2022-08-08 -- 1"': c14b029a3c16b14e4aa896f9e22090a8.

\section{Schaltungsbeschreibung} \label{sec:schaltung}

Die Schaltung besteht aus folgenden Bl"ocken:
\begin{itemize}
\item Microcontroller ESP32 auf Daughterboard
\item Audioschaltung
\item Radio steuern per Webradio
\item Webradio steuern per Radio
\item Spannungsversorgung
\item Schnittstellen
\end{itemize}

In den folgenden Kapiteln wird Design, Funktion und Zusammenwirken beschrieben.

\subsection{Datenbl"atter} \label{sec:schaltung:datenblaetter}

Folgende Datenbl"atter und Application Notes wurden verwendet (u.A):
\begin{itemize}
\item ADA4522-1/ADA4522-2/ADA4522-4 Rev. F
\item AD8655/AD8656 Rev. E
\item VS1053b Datasheet Version: 1.31, 2017-11-17
\item VS10XX AppNote Rev 1.25
\item vs1033example\_rev07
\item Layout Considerations VS10XX AppNote Rev 1.0
\item DOIT ESP32 Devkit V1
\item ESP32­WROOM­32D \& ESP32­WROOM­32U Datasheet Version 2.0 2020
\item TI LM139, LM239, LM339, LM139A LM239A, LM339A, LM2901, LM2901AV, LM2901V  SLCS006U – OCTOBER 1979 – REVISED NOVEMBER 2018
\end{itemize}

\subsection{Microcontroller} \label{sec:schaltung:Microcontroller}

Der ESP32 wird verwendet da f"ur diesen mit dem ESP32-Radio ein passendes Softwareprojekt bereits zur Verf"ugung steht. Ebenfalls m"oglich w"are ein Raspberry Pi o."a. gewesen, dieser h"atte aber erheblich h"ohere Anforderungen an die Leistung des Netzteils gestellt.\\

Es wird ein vorgefertigtes Board verwendet.
\begin{itemize}
\item Sichere Funktion durch vorgefertige Platine, inkl. Netzteil, Resetbeschaltung und Programmierschaltung. Leichtes Pr"ufen da tauschbar.
\item ESP32-WROOM-32 Aufl"otmodul hat Pad auf Unterseite, somit nur umst"andlich handl"otbar.
\item Belegt weniger Platz auf Baseboard.
\item Programmieren ohne Baseboard m"oglich.
\item Vernachl"assigbarer Aufpreis.
\end{itemize}

\subsection{Audioschaltung} \label{sec:schaltung:audio}

\textbf{Codec}

Die Audioschaltung basiert auf einem VLSI VS1053 MP3 Hardware Codec. Wir nutzen nur den Decoder. Der VS1053 wird vom ESP32-Radio Projekt vorgegeben. Schaltung und Layout sind nach Application Note von VLSI.

\textbf{Verst"arker}

Das vomn VS1053 ausgegebene Audiosignal wird von einem Audioverst"arker verst"arkt. Dies erm"oglicht ein Anpassen des Audiopegels an die Empfindlichkeit des TA Eingangs. \\
Der OP ist als \emph{\href{https://www.mikrocontroller.net/articles/Operationsverst\%C3\%A4rker-Grundschaltungen\#Betrieb\_mit\_einfacher\_Versorgungsspannung}{nichtinvertierender Wechselspannungsverstärker mit einfacher Versorgungsspannung}} verschaltet. Die Schaltung ist dimensioniert um einen hochohmigen Eingang zu treiben. Der OP muss folgende Bedingungen erf"ullen:
\begin{itemize}
\item Betrieb an 5\,V einfacher Versorgung
\item Linear im Audiobereich
\item Ausgangsspannung bis ca. +/- 0,5\,V an Versorgungsspannungen
\end{itemize}
Es sind somit praktisch alle f"ur niedrige Versorgungsspannungen optimierten OPs geeignet.

\textbf{Massef"uhrung}

Die Analogschaltung verwendet die allgemeine Massefl"ache (keine Sternanbindung). Die Schaltung ist nicht mit der Masse des Radios verbunden.

\textbf{Ausgangstrafo}

Um Brummen zu vermeiden muss die Audioschaltung am GND Anschluss TA mit dem Radio verbunden werden. Gleichzeitig muss aber der Versorgungsstrom der Mikrocontrollerschaltung "uber den Fernbedienungsanschluss flie"sen. Diese Aufteilung ist nur m"oglich wenn entweder die Versorgungsseite oder die Audioseite potentialgetrennt werden. Schaltung Rev. A hat einen DC/DC Wandler vorgesehen, dieser hat den Radioempfang gest"ort. Schaltung Rev. B verwendet daher einen Ausgangstrafo.

\textbf{Stereo}

Die Audioschaltung ist zweikanalig ausgef"uhrt. Bei der Platinenbest"uckung kann ausgew"ahlt werden ob am Ausgang beide Signale zu einem Monosignal gemischt werden oder Stereo ausgegeben wird. Dies erm"oglicht eine einfache Anpassung zur Verwendung an Stereoger"aten.

\subsection{Steuerung Radio} \label{sec:schaltung:steuern-radio}

Der Steuerteil ersetzt 1:1 die kabelgebundene SABA Fernbedienung. Die Schaltung basiert auf der IR Fernbedienung Saba Freiburg 125 von H. Krebs. Schaltung und Bauteilwerte wurde an die 6-3D Serie angepasst.

\textbf{Automatik Steuerung}

Bildet die Schaltung in der Fernbedienung nach. Die Widerst"ande 1\,kOhm sind leistungstechnisch so ausgelegt das sie bei Softwarefehler (alle drei Relais geschaltet) nicht zerst"ort werden.

\textbf{Haltespule}

In der SABA Fernbedienung entspricht die Haltespule einem Relais mit Selbsthaltung. Wenn ein Sender gefunden ist flie"st kein Strom mehr und die Spule f"allt ab. Die Schaltung und Software muss dieses Verhalten nachbilden:
\begin{itemize}
\item Das Radio muss weiterhin einen Widerstand ca. 6\,kOhm "`sehen"'\footnote{Siehe Schaltschema SABA - Fernbed. Anschl.} da die im Radio verbaute Haltespule sonst nicht mehr funktioniert
\item Die Software muss Abfall des Stromflusses erkennen ("`Sender gefunden"') und Suchlaufrelais abschalten.
\end{itemize}
Es muss ein Widerstand mind. 0,25\,W verwendet werden.

\textbf{Lautst"arke, Stummschaltung}

Im Gegensatatz zur Schaltung von H. Krebs verwenden wir Relais. Die zus"atzlichen Kontakte werden zur Verriegelung verwendet. Dies verhindert Zerst"orung des Radio Netztrafos durch Kurzschluss bei Softwarefehler (Relais laut und leise gleichzeitig geschaltet). Es verhindert auch gleichzeitigen Betrieb von Suchlauf und Stummschaltung.

\textbf{Netzschalter}

Der Schaltungsteil Netzschalter ist optional. Er erm"oglicht ein Ausschalten (und bei USB Versorgung auch Einschalten) des Radios per Webradio. Falls nicht ben"otigt, Spannung 230\,V AC auf N1 oder N2 br"ucken. Alternativ kann auch die eine H"alfte des Zentrierstiftes aus \ref{sec:aufbau:anschlussstecker} abgeschliffen werden um den Schaltkontakt im Radio dauerhaft geschlossen zu halten. Die zugeh"origen Kontaktstifte k"onnen dann entfallen.

Der Wechlser im Relais bildet in Verbindung mit dem Netzschalter im Radio eine Wechselschaltung. Um den Zustand auch ohne Versorgungsspannung zu halten wird ein bistabiles Relais verwendet.

\todo nicht in Software implementiert.

\textbf{USB Versorgung}

Optional, nur Sinnvoll in Verbindung mit Netzschalter, erm"oglicht Standby / Einschalten per Netzwerk. Der Schaltungsteil "`Spannungsversorgung 5\,V"'\footnote{Siehe Schaltplan Seite 3} und der Ausgangstrafo kann entfallen.

\textbf{Infrarotfernbedienung}

Wird vom ESP32-radio Projekt unterst"utzt, nicht weiter getestet. Funktion wird in der Doku des ESP32-radio detailliert beschrieben.

\subsection{Steuerung Webradio} \label{sec:schaltung:steuern-web}

Der Schaltungsteil Steuerung Webradio erm"oglicht eine Bedienung des Webradios mit der Suchlaufwippe am Radio. Diese hat f"unf Schalterstellungen:
\begin{itemize}
\item Nicht bet"atigt
\item Suchlauf jeweils links und rechts.
\item Schnelllauf jeweils links und rechts
\end{itemize}
Abh"angig von der Schalterposition wird das Signal auf der Suchlaufleitung ver"andert:
\begin{itemize}
\item Keine Bet"atigung - DC Vorspannung der Triode EABC80 R"o. 4.
\item Bet"atigung Suchlauf - DC Spannung wird negativ verschoben (Stummschaltung), AC wird aufaddiert. AC Phase abh. von der Laufrichtung.
\item Bet"atigung Schnelllauf - Wie Suchlauf, aber AC Amplitude h"oher.
\end{itemize}

Die Schalterposition kann folglich anhand der aufaddierten Wechselspannung ermittelt werden. Der Verlauf wird an der Simulation sichtbar:

\begin{itemize}
\item 1\,s ... 2\,s - links Schnelllauf
\item 3\,s ... 4\,s - links Suchlauf
\item 7\,s ... 8\,s - rechts Schnelllauf
\item 9\,s ... 10\,s - rechts Suchlauf
\item restliche Zeit - nicht bet"atigt.
\end{itemize}

\begin{figure}[H]
\centering
\begin{tikzpicture}
     \node[anchor=south west,inner sep=0] at (0,0) {};
\end{tikzpicture}
\caption{Spannung Rot: Suchlaufleitung -- AC 0V, Blau: Suchlaufleitung -- AC 15V -90°} \label{fig:1}
\end{figure}

Messung mit Einweggleichrichtung und Siebung der Wechselspannung. Umsetzung in digitale Signale mit Komparatoren. Die Spannungen beziehen sich auf die Mittelanzapfung des Trafos. Dieser Punkt ist \textbf{nicht} mit der Masse des Radios verbunden. Daher ist f"ur die digitalen Signale Potentialtrennung erforderlich.

\section{Untersuchungen} \label{sec:untersuchung}

\subsection{Probleme} \label{sec:untersuchung:probleme}

Probleme und L"osungsvorschl"age.

\textbf{In Software funktioniert \emph{xyz} nicht}

\begin{itemize}
\item ESP32 mit PC USB verbinden, Kapitel \ref{sec:aufbau:programmierung} beachten. Der ESP32 verh"alt sich wie ein USB Seriell Wandler.
\item Serielles Terminal verbinden, 115200 8-N-1. Linux z.B. minicom, Windows z.B. Putty oder HyperTerminal
\item Funktion starten, Ausgabe auswerten. 
\item Im Terminal k"onnen auch Kommandos eingegeben werden (z.B. \emph{reset}). Der ESP32 selbst macht kein "`Echo"', d.H. abh"angig von der Terminalkofiguration sieht man die eigene Eingabe nicht. "`Enter"' f"uhrt Eingabe aus. Liste der Kommandos ist im Sourcecode in "`main.c"', Funktion "`analyzeCmd"' enthalten.
\end{itemize}

\textbf{Erkennung TA Eingang und LEDs in den Tasten}

Die Gl"uhlampen f"ur die Taster werden nicht mehr hergestellt und sind auch anderweitig nicht auftreibbar. Werden diese durch LED + Gleichrichter ersetzt funktioniert die Schaltung zur Erkennung des TA nicht mehr. Diese kann wie folgt angepasst werden

\begin{figure}[H]
\centering
\begin{tikzpicture}
     \node[anchor=south west,inner sep=0] at (0,0) {};
\end{tikzpicture}
\hspace{1cm} %no empty line!
\begin{tikzpicture}
     \node[anchor=south west,inner sep=0] at (0,0) {};
\end{tikzpicture}
\caption{Anpassung LEDs} \label{fig:1}
\end{figure}

\textbf{Webinterface reagiert langsam}

Webseite aufrufen mit der IP Adresse statt URL. Scheinbar bringen div. Router da etwas durcheinander wenn mehrere ESP32 am Netz sind.

\textbf{Weitere}

\todo weitere ...

\subsection{Ausgangs"ubertrager} \label{sec:untersuchung:ausgangsuebertrager}

Wir haben einen relativ niederohmigen Ausgang (Opamp) und eine sehr hochohmige Last (Radio Phonoeingang).

Es wurden verschiedene Ausgangs"ubertrager untersucht um ein geeignetes Bauteil zu finden. 

Von links nach rechts:
\begin{itemize}
\item Ground Loop Isolator Sinus Live GL-205, 2 x RCA (ca. 15 Euro)
\item Telefon"ubertrager 600:600 Ohm EI14 (Ebay China ca. 4 Euro / 10 Stk.)
\item CMC 47\,mH Talema CAF 0,5-47 (ca. 3 Euro)
\item NFU 1-1 EI19 50\,Hz ... 10\,kHz, 34\,mH (ca. 3 Euro)
\item FeinTech ATG00101 Audio Masse-Trennglied, Klinke 3,5\,mm (ca. 15 Euro)
\end{itemize}

Wir brauchen ca. 100\,Hz ... 15\,kHz.

Versuchsaufbau nach \emph{\href{https://keysightoscilloscopes.wordpress.com/2016/04/13/how-to-create-bode-plots-on-an-oscilloscope/}{Vorschlag Keysight, how to create bode plots on an oscilloscope}}.

Sweep 0 ... 20\,kHz, 1\,V\textsubscript{SS}, 50\,Ohm Ausgangswiderstand Generator, 100\,kOhm Lastwiderstand Sekund"arseite. Scheinbar hat der Generator hier einen Bug, es kommen 2\,V\textsubscript{SS} raus?

\begin{figure}[H]
\centering
\begin{tikzpicture}
     \node[anchor=south west,inner sep=0] at (0,0) {};
\end{tikzpicture}
\caption{getestete "Ubertrager} \label{fig:1}
\end{figure}

\begin{figure}[H]
\centering
\begin{tikzpicture}
     \node[anchor=south west,inner sep=0] at (0,0) {};
\end{tikzpicture}
\caption{GL-205} \label{fig:1}
\end{figure}

\begin{figure}[H]
\centering
\begin{tikzpicture}
     \node[anchor=south west,inner sep=0] at (0,0) {};
\end{tikzpicture}
\caption{China 600:600 Ohm} \label{fig:1}
\end{figure}

\begin{figure}[H]
\centering
\begin{tikzpicture}
     \node[anchor=south west,inner sep=0] at (0,0) {};
\end{tikzpicture}
\caption{CMC 47\,mH} \label{fig:1}
\end{figure}

\begin{figure}[H]
\centering
\begin{tikzpicture}
     \node[anchor=south west,inner sep=0] at (0,0) {};
\end{tikzpicture}
\caption{NFU 1-1} \label{fig:1}
\end{figure}

\begin{figure}[H]
\centering
\begin{tikzpicture}
     \node[anchor=south west,inner sep=0] at (0,0) {};
\end{tikzpicture}
\caption{ATG00101} \label{fig:1}
\end{figure}

Im niedrigen Frequenzbereich sind Unterschiede sichtbar. Daher nochmal Detailmessung 0 ... 2\,kHz.

\begin{figure}[H]
\centering
\begin{tikzpicture}
     \node[anchor=south west,inner sep=0] at (0,0) {};
\end{tikzpicture}
\caption{GL-205} \label{fig:1}
\end{figure}

\begin{figure}[H]
\centering
\begin{tikzpicture}
     \node[anchor=south west,inner sep=0] at (0,0) {};
\end{tikzpicture}
\caption{China 600:600 Ohm} \label{fig:1}
\end{figure}

\begin{figure}[H]
\centering
\begin{tikzpicture}
     \node[anchor=south west,inner sep=0] at (0,0) {};
\end{tikzpicture}
\caption{CMC 47\,mH} \label{fig:1}
\end{figure}

\begin{figure}[H]
\centering
\begin{tikzpicture}
     \node[anchor=south west,inner sep=0] at (0,0) {};
\end{tikzpicture}
\caption{NFU 1-1} \label{fig:1}
\end{figure}

\begin{figure}[H]
\centering
\begin{tikzpicture}
     \node[anchor=south west,inner sep=0] at (0,0) {};
\end{tikzpicture}
\caption{ATG00101} \label{fig:1}
\end{figure}

Ergebnis:
\begin{itemize}
\item Die beiden kommerziell erhältlichen Massetrenner zeigen keinen nennenswerten Unterschied zwischen dem Spannungspegel an Ein- und Ausgang.
\item Bei niedrigen Ausgangsfrequenzen wird ggf. X\textsubscript{L} zu niedrig? $\rightarrow$ Stromfluss.
\item Die CMC funktioniert "uberraschend gut -- in diesem Testaufbau sogar besser als der Audio"ubertrager.
\item Der 600:600 Ohm Telefon"ubertrager ist mehr als ausreichend gut, billig, leicht zu bekommen und klein.
\end{itemize}

\subsection{W-Lan Antenne}

Es kann eine 2,4\,GHz W-Lan Antenne angeschlossen werden\footnote{\url{https://community.home-assistant.io/t/how-to-add-an-external-antenna-to-an-esp-board/131601}}.  

\begin{figure}[H]
\centering
\begin{tikzpicture}
     \node[anchor=south west,inner sep=0] at (0,0) {};
\end{tikzpicture}
\hspace{1cm} %no empty line!
\begin{tikzpicture}
     \node[anchor=south west,inner sep=0] at (0,0) {};
\end{tikzpicture}
\caption{Nach Anleitung} \label{fig:1}
\end{figure}

Anstelle eines Kabels kann auch eine Buchse montiert werden.

\begin{figure}[H]
\centering
\begin{tikzpicture}
     \node[anchor=south west,inner sep=0] at (0,0) {};
\end{tikzpicture}
\caption{Mit Buchse / Stecker} \label{fig:1}
\end{figure}
                                                        
Im Versuch wurde das Signal ca. 6 ... 10\,dB st"arker.

\appendix

\section{Ausgabe md5sum Webserver}

Version "`Build: 2022-08-08 -- 1"'

\begin{lstlisting}
martin@mint ~/workspace/esp32_radio/ESP32-Radio/Release $ wget http://martinwag.atwebpages.com/ESP32_radio/firmware.bin
--2022-08-08 16:10:38--  http://martinwag.atwebpages.com/ESP32_radio/firmware.bin
Resolving martinwag.atwebpages.com (martinwag.atwebpages.com)... 185.176.43.53
Connecting to martinwag.atwebpages.com (martinwag.atwebpages.com)|185.176.43.53|:80... connected.
HTTP request sent, awaiting response... 200 OK
Length: 937040 (915K) [application/octet-stream]
Saving to: firmware.bin.1

firmware.bin.1                     100%[================================================================>] 915,08K  3,88MB/s    in 0,2s    

2022-08-08 16:10:38 (3,88 MB/s) - firmware.bin.1 saved [937040/937040]

martin@mint ~/workspace/esp32_radio/ESP32-Radio/Release $ md5sum firmware.bin*
c14b029a3c16b14e4aa896f9e22090a8  firmware.bin
c14b029a3c16b14e4aa896f9e22090a8  firmware.bin.1
\end{lstlisting}

\section{Ausgabe esptool.py}

\begin{lstlisting}
$ esptool.py  erase_flash
esptool.py v4.1
Found 2 serial ports
Serial port /dev/ttyUSB0
Connecting.....
Detecting chip type... Unsupported detection protocol, switching and trying again...
Connecting.......
Detecting chip type... ESP32
Chip is ESP32-D0WDQ6 (revision 1)
Features: WiFi, BT, Dual Core, 240MHz, VRef calibration in efuse, Coding Scheme None
Crystal is 40MHz
MAC: ac:67:b2:36:b3:b4
Uploading stub...
Running stub...
Stub running...
Erasing flash (this may take a while)...
Chip erase completed successfully in 2.3s
Hard resetting via RTS pin...

$ esptool.py --chip esp32 --baud 921600 --before default_reset --after hard_reset write_flash -z --flash_mode dio --flash_freq 80m --flash_size detect 0xe000 /opt/eclipse/arduinoPlugin/packages/esp32/hardware/esp32/1.0.6/tools/partitions/boot_app0.bin 0x1000 /opt/eclipse/arduinoPlugin/packages/esp32/hardware/esp32/1.0.6/tools/sdk/bin/bootloader_dio_80m.bin 0x10000 /home/martin/workspace/esp32_radio/ESP32-Radio/Release/ESP32_Radio.bin 0x8000 /home/martin/workspace/esp32_radio/ESP32-Radio/Release/ESP32_Radio.partitions.bin 
esptool.py v4.1
Found 2 serial ports
Serial port /dev/ttyUSB0
Connecting......
Chip is ESP32-D0WDQ6 (revision 1)
Features: WiFi, BT, Dual Core, 240MHz, VRef calibration in efuse, Coding Scheme None
Crystal is 40MHz
MAC: ac:67:b2:36:b3:b4
Uploading stub...
Running stub...
Stub running...
Changing baud rate to 921600
Changed.
Configuring flash size...
Auto-detected Flash size: 4MB
Flash will be erased from 0x0000e000 to 0x0000ffff...
Flash will be erased from 0x00001000 to 0x00005fff...
Flash will be erased from 0x00010000 to 0x000f4fff...
Flash will be erased from 0x00008000 to 0x00008fff...
Compressed 8192 bytes to 47...
Wrote 8192 bytes (47 compressed) at 0x0000e000 in 0.1 seconds (effective 1005.8 kbit/s)...
Hash of data verified.
Compressed 17120 bytes to 11164...
Wrote 17120 bytes (11164 compressed) at 0x00001000 in 0.3 seconds (effective 460.0 kbit/s)...
Hash of data verified.
Compressed 936896 bytes to 530440...
Wrote 936896 bytes (530440 compressed) at 0x00010000 in 7.1 seconds (effective 1051.7 kbit/s)...
Hash of data verified.
Compressed 3072 bytes to 128...
Wrote 3072 bytes (128 compressed) at 0x00008000 in 0.1 seconds (effective 446.9 kbit/s)...
Hash of data verified.

Leaving...
Hard resetting via RTS pin...
\end{lstlisting}

\section{Ausgabe serielle Schnittstelle beim Boot}

Boot, Webradio aktiv (TA Modus), keine SD Karte.

\begin{lstlisting}
D: Starting ESP32-radio running on CPU 1 at 240 MHz.  Version Mon, 28 Jun 2021 12:40:00 GMT.  Free memory 273896
D: Display type is DUMMYTFT
D: Partition nvs found, 20480 bytes
D: Read 36 keys from NVS
D: pin_ir set to -1
D: pin_enc_clk set to -1
D: pin_enc_dt set to -1
D: pin_enc_sw set to -1
D: pin_tft_cs set to -1
D: pin_tft_dc set to -1
D: pin_tft_scl set to -1
D: pin_tft_sda set to -1
D: pin_tft_bl set to -1
D: pin_tft_blx set to -1
D: pin_sd_cs set to 21
D: pin_ch376_cs set to -1
D: pin_ch376_int set to -1
D: pin_vs_cs set to 5
D: pin_vs_dcs set to 32
D: pin_vs_dreq set to 4
D: pin_shutdown set to -1
D: pin_shutdownx set to -1
D: pin_spi_sck set to 18
D: pin_spi_miso set to 19
D: pin_spi_mosi set to 23
D: pin_saba_power1 set to -1
D: pin_saba_power2 set to -1
D: pin_saba_power_fb set to -1
D: pin_saba_vol_up set to 15
D: pin_saba_vol_down set to 2
D: pin_saba_vol_mute set to 16
D: pin_saba_move_left set to 13
D: pin_saba_move_right set to 14
D: pin_saba_move_fast set to 12
D: pin_saba_move_dir set to 27
D: pin_saba_move_is_fast set to 34
D: pin_saba_move_is_slow set to 33
D: pin_saba_search_hold set to 36
D: pin_saba_pickup_active set to 39
D: GPIO0 is HIGH
D: GPIO2 is LOW, probably no PULL-UP
D: GPIO4 is HIGH
D: GPIO5 is HIGH
D: GPIO12 is LOW, probably no PULL-UP
D: GPIO13 is LOW, probably no PULL-UP
D: GPIO14 is LOW, probably no PULL-UP
D: GPIO15 is LOW, probably no PULL-UP
D: GPIO16 is LOW, probably no PULL-UP
D: GPIO17 is HIGH
D: GPIO18 is LOW, probably no PULL-UP
D: GPIO19 is HIGH
D: GPIO21 is HIGH
D: GPIO22 is HIGH
D: GPIO23 is HIGH
D: GPIO25 is LOW, probably no PULL-UP
D: GPIO26 is LOW, probably no PULL-UP
D: GPIO27 is HIGH
D: GPIO32 is HIGH
D: GPIO33 is HIGH
D: GPIO34 is HIGH
D: GPIO35 is LOW, probably no PULL-UP
D: GPIO36 is HIGH
D: GPIO39 is HIGH
[E][sd_diskio.cpp:123] sdSelectCard(): Select Failed
[E][sd_diskio.cpp:775] sdcard_mount(): f_mount failed: (3) The physical drive cannot work
[E][sd_diskio.cpp:123] sdSelectCard(): Select Failed
D: SD Card Mount Failed!
D: Create list with acceptable WiFi networks
D: Added wlan-meins to list of networks
D: End adding networks
D: Scan Networks
D: Scan completed
D: Number of available networks: 2
D:  1 - wlan-meins                Signal: -59 dBm, Encryption WPA2_PSK, Acceptable
D:  2 - WLAN-xxxxxx               Signal: -93 dBm, Encryption WPA2_PSK, 
D: End of list
D: Command: clk_dst with parameter 1
D: Command: clk_offset with parameter 1
D: Command: clk_server with parameter pool.ntp.org
D: Command: lstmods with parameter Sun, 19 Jun 2022 13:10:24 GMT
D: Command: mqqprefix with parameter none
D: Command: mqttbroker with parameter none
D: Command: mqttpasswd with parameter *******
D: Command: mqttport with parameter 1883
D: Command: mqttuser with parameter none
D: Command: pin_sd_cs with parameter 21
D: Command: pin_vs_cs with parameter 5
D: Command: pin_vs_dcs with parameter 32
D: Command: pin_vs_dreq with parameter 4
D: Command: preset with parameter 9
D: Command: preset_00 with parameter edge67.streamonkey.net/gong-live/stream/mp3?aggregator=user
D: Command: preset_01 with parameter stream.live.vc.bbcmedia.co.uk/bbc_6music
D: Command: preset_02 with parameter dispatcher.rndfnk.com/br/puls/live/mp3/mid
D: Command: preset_03 with parameter mp3ad.egofm.c.nmdn.net/egofm_128/livestream.mp3?
D: Command: preset_04 with parameter sunshinelive.hoerradar.de/sunshinelive-live-mp3-hq
D: Command: preset_05 with parameter media-sov.musicradio.com:80/GoldMP3
D: Command: preset_06 with parameter liveradio.swr.de/d9zadj3/dasding/
D: Command: preset_07 with parameter stream.live.vc.bbcmedia.co.uk/bbc_radio_one
D: Command: preset_08 with parameter stream.live.vc.bbcmedia.co.uk/bbc_radio_two
D: Command: preset_09 with parameter mp3ad.egofm.c.nmdn.net/egofmpure_128/livestream.mp3?
D: Command: preset_10 with parameter sunshinelive.hoerradar.de/sunshinelive-house-mp3-hq
D: Command: preset_11 with parameter sunshinelive.hoerradar.de/sunshinelive-classics-mp3-hq
D: Command: preset_12 with parameter airspectrum.cdnstream1.com:8114/1648_128
D: Command: preset_13 with parameter airspectrum.cdnstream1.com:8000/1261_192
D: Command: preset_14 with parameter icecast.omroep.nl:80/radio1-bb-mp3
D: Command: preset_15 with parameter stream.srg-ssr.ch/drsvirus/mp3_128.m3u
D: Command: toneha with parameter 0
D: Command: tonehf with parameter 0
D: Command: tonela with parameter 0 
D: Command: tonelf with parameter 0
D: Command: volume with parameter 100
D: Slow SPI, Testing VS1053 read/write registers...
D: Fast SPI, Testing VS1053 read/write registers again...
D: endFillByte is 0
D: Connect to WiFi
D: Try WiFi wlan-meins
D: Connected to wlan-meins
D: IP = 192.168.1.86
D: Start server for commands
D: Network found. Starting mqtt and OTA
D: MDNS responder started
D: Rotary encoder is disabled (-1/-1/-1)
D: STOP requested 
D: New preset/file requested (9/0) from mp3ad.egofm.c.nmdn.net/egofmpure_128/livestream.mp3?
D: New station request
D: Connect to new host mp3ad.egofm.c.nmdn.net/egofmpure_128/livestream.mp3?
D: Connect to mp3ad.egofm.c.nmdn.net on port 80, extension /egofmpure_128/livestream.mp3?
D: Song stopped correctly after 0 msec
D: Connected to server
D: switch to pickup (direct)
D: station active
D: Switch to HEADER
D: Headerline: Server: nginx
D: Headerline: Content-Length: 0
D: Headerline: Connection: close
D: Headerline: Cache-Control: no-cache, no-store, must-revalidate
D: Headerline: Expires: Mon, 26 Jul 1997 05:00:00 GMT
D: Headerline: Access-Control-Allow-Origin: *
D: Headerline: Access-Control-Allow-Headers: Origin, Accept, X-Requested-With, Content-Type
D: l-Allow-Headers: Origin, Accept, X-Requested-With, Content-Type seen.
D: Headerline: Access-Control-Allow-Methods: GET, OPTIONS, HEAD
D: Headerline: Location: http://egofm--di--nacs-ais-lgc--0c--cdn.cast.addradio.de/egofm/pure/mp3/high/stream.mp3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
D: Switch to DATA, bitrate is 0, metaint is 0
D: Duration mp3loop 52
D: New station request
D: Connect to new host egofm--di--nacs-ais-lgc--0c--cdn.cast.addradio.de/egofm/pure/mp3/high/stream.mp3?_art=dj0yJmlwPTkzLjIzMy4xNi4yNDkmaWQ9aWNzY3hsLWN
D: Connect to egofm--di--nacs-ais-lgc--0c--cdn.cast.addradio.de on port 80, extension /egofm/pure/mp3/high/stream.mp3?_art=dj0yJmlwPTkzLjIzMy4xNi4yNDkma
D: Connected to server
D: Command: resume with parameter 0
D: Command accepted
D: Switch to HEADER
D: Headerline: Cache-Control: no-cache
D: Headerline: Pragma: no-cache
D: Headerline: Expires: Mon, 26 Jul 1997 05:00:00 GMT
D: Headerline: icy-br: 128
D: Headerline: Instance-id: 93bd887a54781410ccf2dd678482d06d
D: Headerline: Server: nacs-ais-lgc_fra-01-eco_edge_765330e391dc9d6ac20249d04f9ce671 9.0.6
D: Headerline: icy-genre: egoFM - pure
D: Headerline: icy-metaint: 16000
D: Headerline: Content-Type: audio/mpeg
D: audio/mpeg seen.
D: Headerline: icy-name: egoFM - pure
D: Headerline: Access-Control-Allow-Origin: *
D: Headerline: Connection: close
D: Headerline: icy-url:  
D: Headerline: icy-audio-info: ice-samplerate=44100;ice-bitrate=128;ice-channels=2
D: Headerline: icy-pub: 0
D: Headerline: icy-description: egoFM - pure
D: Headerline: X-Loudness: -10.097031
D: Headerline: Set-Cookie: AISSessionId=62509951cb194777_6196743_KpUkaTto__0000001qoJk; Path=/; Domain=egofm--di--nacs-ais-lgc--0c--cdn.cast.addradio.de
D: Switch to DATA, bitrate is 128, metaint is 16000
D: Duration mp3loop 82
D: New station request
D: Stopping client
D: Connect to new host egofm--di--nacs-ais-lgc--0c--cdn.cast.addradio.de/egofm/pure/mp3/high/stream.mp3?_art=dj0yJmlwPTkzLjIzMy4xNi4yNDkmaWQ9aWNzY3hsLWN
D: Connect to egofm--di--nacs-ais-lgc--0c--cdn.cast.addradio.de on port 80, extension /egofm/pure/mp3/high/stream.mp3?_art=dj0yJmlwPTkzLjIzMy4xNi4yNDkma
D: Connected to server
D: Switch to HEADER
D: Headerline: Cache-Control: no-cache
D: Headerline: Pragma: no-cache
D: Headerline: Expires: Mon, 26 Jul 1997 05:00:00 GMT
D: Headerline: icy-br: 128
D: Headerline: Instance-id: 93bd887a54781410ccf2dd678482d06d
D: Headerline: Server: nacs-ais-lgc_fra-01-eco_edge_765330e391dc9d6ac20249d04f9ce671 9.0.6
D: Headerline: icy-genre: egoFM - pure
D: Headerline: icy-metaint: 16000
D: Headerline: Content-Type: audio/mpeg
D: audio/mpeg seen.
D: Headerline: icy-name: egoFM - pure
D: Headerline: Access-Control-Allow-Origin: *
D: Headerline: Connection: close
D: Headerline: icy-url:  
D: Headerline: icy-audio-info: ice-samplerate=44100;ice-bitrate=128;ice-channels=2
D: Headerline: icy-pub: 0
D: Headerline: icy-description: egoFM - pure
D: Headerline: X-Loudness: -10.097031
D: Headerline: Set-Cookie: AISSessionId=62509951cb194777_6196744_moKPC10f__0000001qoJm; Path=/; Domain=egofm--di--nacs-ais-lgc--0c--cdn.cast.addradio.de
D: Switch to DATA, bitrate is 128, metaint is 16000
D: Metadata block 112 bytes
D: Streamtitle found, 107 bytes
D: StreamTitle='';StreamUrl='';adw_ad='true';durationMilliseconds='30537';adId='7567';insertionType='preroll';

\end{lstlisting}

\end{document}

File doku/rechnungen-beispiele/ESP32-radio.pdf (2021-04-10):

## ESP32-radio

This document describes the realization of an Internet radio based on an ESP32 WiFi module.
The ESP32 is the successor of the ESP8266. For the ESP8266 an Internet radio was build and now the software is ported to the ESP32. The Internet radio described here uses the ESP32 as well as a VS1053 module to decode the MP3 stream. A 1.8 TFT color display to give some information about the radio station that’s playing. This display has also a SD card slot. Mp3 tracks on an SD card can be played by the ESP32-radio. Other types of display are also supported, including NEXTION.

## Features:

- Can connect to thousands of Internet radio stations that broadcast MP3 audio streams.
- Can connect to a standalone mp3-file on a server.
- mp3 playlists supported.
- Can play MP3 files from SD card or USB flash drive.
- Uses a minimal number of components.
- Has a preset list of a maximum of 100 favorite radio stations as preferences in flash.
- Can be controlled by a tablet or other device through the built-in webserver.
- Can be controlled by MQTT commands. Status info is published by using MQTT.
- Can be controlled by commands on the serial input.
- Can be controlled by IR.
- Can be controlled by rotary switch encoder.
- Up to 14 input ports can be configured as control buttons like volume, skip to the next/previous/first/favorite preset station.
- I/O pins for TFT, VS1053, IR and rotary encoder can be configured in preferences.
- The strongest available WiFi network is automatically selected. Passwords are kept as preferences in flash. Heavily commented source code, easy to add extra functionality.
- Debug information through serial output.
- 2

nd processor is used for smooth playback.
- Update of software over WiFi (OTA) through Arduino IDE or remote server.
- Parameters like WiFi information and presets can be edited in the web interface.
- Plays iHeartRadio streams.
- Preset, volume, bass and treble settings are saved in preferences.
- Displays time of day on TFT.
- Optional displays remaining battery charge.
- Bitrates up to 320 kbps.
- Control of TFT backlight.
- PCB available.

## Software:

The software for the radio is supplied as an Arduino sketch that can be compiled for the ESP32 using the Arduino IDE version 1.8.5. No Arduino is required in this project.
The following libraries are used:
- WiFi – for establishing the communication with WiFI, part of ESP32 core library
- SPI – for communication with VS1053 and TFT display, part of ESP32 core library
- WiFiMulti - to select the strongest WiFi network
- Adafruit_ST7735– driver for the TFT screen (if configurated).
This driver works also for the red ST7735 display.
- ArduinoOTA for software update over WiFi.
- PubSubClient to handle MQTT messages, see:
https://github.com/knolleary/pubsubclient
- SD and FS for reading from SD card.
- The map with the ESP32-radio sketch must also contain the supplied headerfiles “index_html.h”, “favicon_ico.h”, “radio_css.h”, “config_html.h”, "defaultprefs.h", "mp3play_html.h" and “about_html.h”. These files are included for the webinterface in PROGMEM.
Furthermore the files “Dummytft.h”, “LCD1602”, “SSD1306.h”, “bluetft.h”, “ILI9341.h”, “NEXTION.h” must be included in this map for the different LCD/OLED displays.


## Preferences

Preferences for ESP32-Radio are kept in Flash memory (NVS).
You may change the contents of NVS with the “Config”-button in the web interface. An example of the contents is:
bat0 | = 2178 | # ADC for 0% battery capacity left
bat100 = 3256 | # ACD for 100% battery capacity
clk_dst = 1
clk_offset = -1
clk_server = pool.ntp.org
fs = USB
gpio_00 = uppreset = 1
gpio_12 = upvolume = 2
gpio_13 = downvolume = 2
ir_40BF = upvolume = 2
ir_C03F = downvolume = 2
mqttbroker = mqtt.smallenburg.nl mqttpasswd = *******
mqttport = 1883
mqttuser = edzelf
pin_enc_clk = 25 | # GPIO rotary encoder CLK
pin_enc_dt = 26 | # GPIO rotary encoder DT
pin_enc_sw = 27 | # GPIO rotary encoder SW
pin_ir = 35 | # GPIO IR receiver VS1838B
pin_sd_cs = 21 | # GPIO SD card CS
pin_tft_cs = 15 | # GPIO TFT CS
pin_tft_dc = 2 | # GPIO TFT DC
pin_vs_cs = 5 | # GPIO VS1053 CS
pin_vs_dcs = 16 | # GPIO VS1053 DCS
pin_vs_dreq = 4 | # GPIO VS1053 DREQ
preset = 4
preset_000 = 109.206.96.34:8100 | # 0 - NAXI LOVE RADIO, Belgrade, Serbia
preset_001 = airspectrum.cdnstream1.com:8114/1648_128 # 1 - Easy Hits Florida 128k preset_002 = airspectrum.cdnstream1.com:8142/1303_128 # 2 - CLASSIC ROCK MIAMI 256k preset_003 = airspectrum.cdnstream1.com:8000/1261_192 # 3 - Magic Oldies Florida
preset_004 = airspectrum.cdnstream1.com:8008/1604_128 # 4 - Magic 60s Florida 60s Classic Rock
preset_005 = 198.58.98.83:8258/stream | # 5 - Classic Rock Florida HD
preset_006 = icecast.omroep.nl:80/radio1-bb-mp3 | # 6 - Radio 1, NL
preset_007 = icecast.omroep.nl:80/radio2-bb-mp3 | # 7 - Radio 2, NL
preset_008 = skonto.ls.lv:8002/mp3 | # 8 - Skonto 128k
preset_009 = 94.23.66.155:8106 | # 9 - *ILR CHILL and GROOVE
preset_010 = ihr/IHR_IEDM | # 10 - iHeartRadio IHR_IEDM
preset_011 = ihr/IHR_TRAN | # 11 - iHeartRadio IHR_TRAN
toneha = 0
tonehf = 0
tonela = 0
tonelf = 0
volume = 72
wifi_00 = ADSL-11_plus/******* wifi_01 = NETGEAR-11/*******
wifi_02 = ADSL-11/*******

Not that the size of the NVS is limited to 20 kB.
Lines starting with “#” are comment lines and are ignored. Comments per line (after “#”) will also be ignored, except for the “preset_” lines. The comments on the “preset_” lines are used to identify the presets in the web interface. The maximum line length is 150 characters.
Note that the preset numbers ranges from 000 to 199. The range can be extended by the definition of MAXPRESETS. Note that there is also a limit on the NVS space. If the highest numbered station is reached, the next station will be 00 again. URLs with mp3 files or mp3 playlists (.m3u) are allowed.
Presets starting with "ihr/" are iHeartRadio stations.

Prteferences like "pin_ir", " pin_enc_clk", " pin_enc_dt", " pin_enc_sw", " pin_tft_cs", " pin_tft_dc", " pin_sd_cs", " pin_vs_cs", "pin_vs_dcs" and " pin_vs_dreq" specify the GPIO pins that are wired to the various devices. For a

FEATERBOARD you have to change some settings, especially for TFT and SD card. The pins for SPI default to SCK=18, MISO=19 and MOSI=23, but they may be configured by “pin_spi_sck”, “pin_spi_miso” and “pin_spi_mosi” respectively.
For an I2C display (OLED, LCD1602, LCD2004) there must be definitions for " pin_tft_scl" and " pin_tft_sda".
Remove the lines if a device is not connected.

“pin_shutdown” is the pin that will be set if the radio is not playing or the volume is set to zero. This output-pin can be used to shut down the amplifier.
“pin_shutdownx” has the same function. The output signal is inversed: the pin will be LOW to shut down the amplifier.

"pin_tft_bl" is the pin that controls the back light of a TFT display. The BL is disbled after some time if there is no activity. This helps to reduce power when running on batteries.
"pin_tft_blx" has the same function. The output signal is inversed (LOW to enable the BL pin).

The "gpio_" lines specify input pins and the command that is executed if the input pin goes from HIGH to LOW.

The "touch_" lines specify the GPIO input pins for this signal and the command that is executed if the input pin is activated.

The "ir_XXXX" lines specify IR-codes and the command that is executed if the IR-code is received. The code part is a hexadecimal number in upper-case characters.

The "clk_" lines are used for the display of the current time on the TFT. Please change the values for your timezone. The values in the example are valid for the Netherlands.

The “fs” line specifies the filesystem for MP3 player mode. The file system can be USB or SD for USB drive and SD card respectively. Note that the sketch must be compiled for USB or SD card support. See the defines for SDCARD and/or CH376.

The “bat0” and “bat100” lines are for displaying the remaining battery capacity on the display. See the details at the paragraph with optional features.

The preferences can be edited in the web interface. Changes will in some cases be effective after restart of the Espradio. If the list of preferences is empty (first start), you may use the default button. The list will show some default values which can be edited.

Using Winamp to find out the correct preset line for a station.


Press Alt-3 in the main window (left picture). You will see info for the playing station (right picture). The top line (with “http”) will contain the information for the preset, in this example:

“us1.internet-radio.com:8105”. The complete line for this station in the preferences would be:

preset_05 = us1.internet-radio.com:8105 | # 5 - Classic Rock Florida - SHE Radio

## Optional features:

### Digital control through input pins:

Normally the radio is controlled by the web interface. However, free digital inputs (GPIO) may be connected to buttons to control the radio. Their function can be programmed using the webinterface.

You can assign commands to the digital inputs by adding lines in the configuration (Webinterface, "Config" page). Examples:

gpio_00 = uppreset = 1
gpio_12 = upvolume = 2
gpio_13 = downvolume = 2
gpio_14 = stop
gpio_17 = resume
gpio_21 = station = icecast.omroep.nl:80/radio1-bb-mp3

In this example the ESP32-Radio will execute the command "uppreset=1" if GPIO0 will go from HIGH to LOW. The commands are equal to the commands that are handled by the serial input or by the MQTT interface.

The same format can be used for the touch-inputs:

touch_04 = uppreset = 1
touch_13 = upvolume = 2

In this example the ESP32-Radio will execute the command "uppreset=1" if TOUCH0 (GPIO04) will be activated. The commands are equal to the commands that are handled by the serial input or by the MQTT interface.

IR Interface.
The radio can be controlled by an IR remote control like this:

To use this interface, the "out" pin of a VS1838B receiver must be connected to a GPIO pin of the ESP32:

Add the assigned GPIO pin to the preferences through the config page in the web interface. Example:
pin_ir = 35 | # GPIO Pin number for IR receiver VS1838B

VCC is connected to 3.3 Volt. A 220 µF capacitor should be connected between VCC and GND.
The software will read the raw code of the IR transmitter, making it possible to use virtually any remote control to be used. I tested it with the 21 button remote as well as with an LG TV remote.
To assign functions to the buttons, watch the debug log output while pressing a button. For example, press the +volume button. You will see something like:
D: IR code 807F received, but not found in preferences!
Now add the command:
ir_807F = upvolume = 2
to the preferences in the config page of the web interface. Likewise you can assign functions to all buttons, for example:
ir_8A31 = uppreset = 1
ir_719A = station = us1.internet-radio.com:8105
ir_1F6B = mute

### Display remaining battery capacity:

The remaining battery capacity is computed by measuring the battery voltage on ping GPIO36 (ADC0).
The battery voltage must be supplied to ADC0 through a resistor voltage divider. The maximum voltage fort his input is 1.0 volt. I used 100 kΩ and 22 kΩ fort his purpose.
Furthermore you need to specify ADC value for both the full and the empty voltages. These values must be in the preferences like:
bat0 | = 2178 | # ADC for 0% battery capacity left
bat100 = 2690 | # ACD for 100% battery capacity

To calibrate the settings you may use the “TEST” command in the serial monitor. This will display the current reading of the ADC0 pin. Do this for a fully charge battery and for an (almost) empty one.
Note that it will take about 6 seconds before the reading is stable. This is a result of a filter in the measurement of the ADC.

The remaining capacity is displayed as a green/red bar near the top of the display.

## Hardware:

The radio is built with the following widely available hardware:
- An ESP-32 module. This is basically an ESP32 on a small print. I used a DOIT ESP32 Development Board. See figure 1 below. The ESP32 is running on 160 MHz. On Aliexpress: this. (https://www.aliexpress.com/item/Elecrow-Official-DOIT-ESP32S-esp32-Development-Board-WiFi-Bluetooth-Dual-Core-CPU-Low-Power-Consumption-DIY/32804562215.html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)
- A VS1053 module. See figure 2.
- A 1.8 inch color TFT display 160x128. Optional, see figure 3 and 4. On Aliexpress: this (https://www.aliexpress.com/item/1-8-Serial-128X160-SPI-TFT-LCD-Module-Display-PCB-Adapter-Power-IC-SD-Socket-R179/32602828489.html) or this. (https://www.aliexpress.com/item/Smart-Electronics-1-8-Inch-128-160-Serial-SPI-TFT-LCD-Module-Display-PCB-Adapter-Power/32597366825.html)
- A 1.44 inch color TFT display 128x128. Optional, see figure 9. On Aliexpress: this. (https://www.aliexpress.com/item/Replace-5110-LCD-1-44-Red-Serial-128X128-SPI-Color-TFT-LCD-Display-Module/32852197696.html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)
- An OLED 128x64 display. Optional, see figure 7. On Aliexpress: this. (https://www.aliexpress.com/item/1pcs-SAMIORE-ROBOT-0-96-white-blue-yellow-0-96-inch-128X64-OLED-Display-Module-0/32640136921.html)
- An 1602 LCD display with I2C backpack. Optional, see figure 8.
- An 2004 LCD display with I2C backpack. Optional, see figure 13.
- A NEXTION display. Optional, see figure 10. Tested with a NX3224T024_011.
- Two small speakers.
- A Class D stereo amplifier to drive the speakers. Best quality if powered by a separate power source.
- A rotary encoder switch. Optional, see figure 4.
- A IR receiver. Optional, see figure 6.
- Two audio transformers. Optional, see figure 11.
- Optional CH376 drive for USB stick, see figure 12.

Fig. 1 | Fig. 2 | Fig. 3


Fig. 4 | Fig. 5

Fig. 6


Fig. 7


F


fig. 8 | Fig. 9


Fig. 10 | Fig. 11

Fig. 13


Fig. 12

Here is a picture of the radio in a test configuration. Only the VS1053 is connected.


The module is not very breadboard friendly. The (hanging over) +5 Volt of the ESP32 is wired to the 5Volt rail of the breadboard. The big capacitor (3300 µF) is added to allow powering the module from USB. Without it, the USB has insufficient power to drive the ESP32.


Another prototype. This time with SD-card, TFT, IR and rotary switch.

The radio may be powered by a 5 V adapter. The radio will function on single LiPo cell as well, so I added a small charge circuit powered by the 5 V input. The amplifier uses a separate LiPo cell to minimize noise caused by the ESP32. The TFT and VS1053 work on 3.8 to 5 Volt.

PCB.


Harm Verbeek, see https://github.com/Edzelf/ESP32-Radio/issues/198, designed a PCB for this radio. I have built the radio on this PCB:

And playing:

There is another PCB version available, see https://github.com/Edzelf/ESP32-Radio/issues/165.

## Wiring:

The logic wiring in the table below. The analog amplifier and the speakers are not included.

Note that the GPIO pins are just an example. The assignment of GPIO pins is defined in the preferences that can be edited in the "config" page of the web interface.

ESP32dev Signal Wired to LCD | Wired to VS1053 | SDCARD | Wired to the rest
GPIO32 | | - | pin 1 XDCS | - | -
GPIO5 | | - | pin 2 XCS | - | -
GPIO4 | | - | pin 4 DREQ | - | -
GPIO2 | | pin 3 D/C or A0 | - | - | -
GPIO22 | | - | - | CS | -
GPIO21 | RXD2 | - | - | - | TX of NEXTION (if in use)
GPIO17 | TXD2 | - | - | - | RX of NEXTION (if in use)
GPIO18 | SCK | pin 5 CLK or SCK | pin 5 SCK | CLK | -
GPIO19 | MISO | - | pin 7 MISO | MISO | -
GPIO23 | MOSI | pin 4 DIN or SDA | pin 6 MOSI | MOSI | -
GPIO15 | | pin 2 CS | - | - | -
GPI03 | RXD0 | - | - | - | Reserved serial input
GPIO1 | TXD0 | - | - | - | Reserved serial output
GPIO34 | - | - | - | - | Optional pull-up resistor
GPIO35 | - | - | - | - | Infrared receiver VS1838B
GPIO25 | - | - | - | - | Rotary encoder CLK
GPIO26 | - | - | - | - | Rotary encoder DT
GPIO27 | - | - | - | - | Rotary encoder SW
GND | - | pin 8 GND | pin 8 GND | | Power supply GND
VCC 5 V - | pin 7 BL | - | Power supply
VCC 5 V - | pin 6 VCC | pin 9 5V | Power supply
EN | - | pin 1 RST | pin 3 XRST | | -

The wiring of the 1.8 inch TFT module is on the right side of the board.
If you use the SD-card on this module, you can wire MOSI and CLK (SPI signals) on the connector on the left side:


In this case, only 2 extra wires are needed for using the SD feature: The MISO signal (pin GPIO19 of the ESP32) and the Chip Select. CS in this example is pin GPIO21, but it can be defined by “pin_sd_cs” in the configuration page of the web interface.

If you want to connect an USB drive, you have to wire the CH376 module as follows:


MISO, MOSI and SCK: wire to the SPI bus.
SS is the select pin, wire to the pin defined by “ch376_cs_pin”.
INT is the interrupt pin, wire to the pin defined by “ch376_int_pin”.

In the sketch you have to define “CH376” near line 166, like:

#define CH376 // For CXH376 support (reading files from USB stick)

Amplifier and power circuit.

The amplifier is a class D stereo amplifier. If the power is shared with the power supply of the radio, you will hear much noise. So I used a separate LiPo battery (Batt 2) for the amplifier.

During operation only Batt 1 will be charged. If the radio is switched off, both batteries will be recharged by the LiPo charger. S1a, S1b and S1c is a triple On-On switch.

Note that there may be high currents in the “off”-position if one of the batteries fully discharged. Use protected batteries only!


A better approach is to use 2 small audio transformers (Error: Reference source not found) to isolate the output of the VS1053 from the power circuit. This is used on the PCB made by Harm Verbeek.

Backlight control circuit.


Web interface.

The web interface is simple and can be adapted to your needs. The basic idea is to have a html page with embedded javascript that displays an interface to the radio. Command to the radio can be sent to the http server on the ESP32. The IP address of the webserver will be displayed on the TFT during startup. The webpages are defined in
PROGMEM.

## Capabilities of the webserver:

Let’s assume that the IP of the ESP32-radio is 192.168.2.12. From your browser you can show a simple root page by entering the following URL: http://192.168.2.12. This will display the index_html.h page from the PROGMEM as well as favicon_ico.h.

If your computer is configured for mDNS, you can also use http://ESP32Radio.local (http://esp-radio.local/) in your browser.

The following simple web interface will be displayed:


Clicking on one of the available buttons will control the ESP32-radio. The reply of the webserver will be visible in the status box below the buttons. A click will be translated into a command to the ESP32-radio in the form:

http://192.168.2.12/?<parameter>=<value>

For example: http://192.168.2.12/?upvolume=2

The “STATUS” and “TEST” buttons give some info about the playing stream/file.

Not all functions are available as buttons in the web interface shown above. Commands may also come from MQTT or serial input. Not all commands are meaningful on MQTT or serial input. Working commands are:

preset | = 12 | Select start preset to connect to
uppreset | = 1 | Select next preset or playlist entry
downpreset = 1 | Select previous preset or playlist entry
preset_00 = <mp3 stream> | Specify station for a preset 00-99
volume | = 95 | Percentage between 0 and 100
upvolume | = 2 | Add percentage to current volume
downvolume = 2 | Subtract percentage from current volume
toneha | = <0..15> | Setting treble gain
tonehf | = <0..15> | Setting treble frequency
tonela | = <0..15> | Setting bass gain
tonelf | = <0..15> | Setting treble frequency
station | = <mp3 stream> | Select new station (will not be saved)
station | = <URL>.mp3 | Play standalone .mp3 file (not saved)
station | = <URL>.m3u | Select playlist (will not be saved)
xml | = <Mountpoint> | Select iHeartRadio station (not saved)
mute | | Mute (or unmute) the music
stop | | Stop player
resume | | Resume player
wifi_00 | = mySSID/mypassword | Set WiFi SSID and password *)
mqttbroker = mybroker.com | Set MQTT broker to use *)
mqttport | = 1883 | Set MQTT port (default 1883) to use *)
mqttuser | = myuser | Set MQTT user for authentication *)
mqttpasswd = mypassword | Set MQTT password for authentication*)
mqttprefix = none | Set MQTT prefix for pub/sub.
clk_server = pool.ntp.org | Time server to be used *)
clk_offset = <-11..+14> | Offset with respect to UTC in hours *)
clk_dst | = <1..2> | Offset during DST in hours *)
mp3track | = <nodeID> or 0 | Play MP3 track from SD card, 0 = random
status | | Show current URL to play
test | | For test purposes
debug | = 0 or 1 | Switch debugging on or off
reset | | Restart the ESP32

Commands marked with "*)" are sensible during power-up only.

Station may also be of the form “skonto.ls.lv:8002/mp3”. The default port is 80.
Station may also point to an mp3 playlist. Example: “www.rockantenne.de/webradio/rockantenne.m3u”.
Station may be an .mp3-file on a remote server. Example: "www.stephaniequinn.com/Music/Rondeau.mp3". Station may also point to a local .mp3-file on SD card. Example: “localhost/friendly.mp3”.
It is allowed to have multiple (max 100) “preset_” lines. The number after the “_” will be used as the preset number. The comment part (after the “#”) will be shown in the webinterface.

It is also allowed to have multiple “wifi_” lines. The strongest Wifi access point will be used.

## Configuration

The "Config" button will bring up a second screen. Here you can edit the preferences. The available Wifi networks are listed as well. The config screen will be shown automatically if the ESP32 cannot connect to one of the WiFi stations specified in the preferences. In that case the ESP32 will act as an accesspoint with the name “ESP32Radio”. You have to connect to this AP with password “ESP32Radio”. Then the ESP32-radio can be reached at http://192.168.4.1.
The configuration screen will be displayed and you have the opportunity to edit the preferences. A "default" button is available to fill the editbox with some example data. For a quick start, just fill in you WiFi network name and password and click "Save". Restart the radio afterwards.
Note that passwords are hidden in this screen to give some protection against abuses. You may however change them here. If unchanged, the original values are preserved.

After changing the contents of this page, it must be saved to the preferences by clicking the “Save” button. Changes will have effect on the next restart of the ESP-radio, so click the “Restart” button.

The “Update”-button can be used to get the latest version of the software by downloading it from http:smallenburg.nl/Arduino/ Esp32_radio.ino.bin.


It may take some time to fill this screen.

## MP3 player

ESP32-Radio can also be used as an mp3 player if an SD card interface is available. The screen will look like this:


When this page is called for the first time, a search for all tracks on the SD card will be executed. This may take some time. All found tracks will be available in the drop-down list on the screen. You may pick a track and it will play. When the track has finished, the next track in the drop-down list will be played automatically.

The “PREV” and “NEXT” buttons will select the previous or next track to be played respectively. You may also click the "RANDOM" button and a random track will be played. If the track has finished a new random song will be selected. In “RANDOM” mode, the “PREV” and “NEXT” buttons will also select a random track.

It may take some time to fill this page because the directories on the SD card are searched for MP3 tracks.

Playlist.
You may use playlists for the MP3 player as well. Playlists have the “.m3u” extension and4 can reside on every sub-directory of the SD card. An example of a playlist (“playlist1.m3u” in the rootdirectory) with tracks pointing to subdirectories (MAP0, MAP4) may look like:

#EXTM3U

#EXTINF:124,01bachfugue.mp3 MAP0/bachfugue.mp3

#EXTINF:177,02gtr-nylon22.mp3 MAP0/gtr-nylon22.mp3

#EXTINF:207,03harpsi-cs.mp3 MAP0/harpsi-cs.mp3

#EXTINF:100,01viola2.mp3

MAP4/viola2.mp3
#EXTINF:101,02violin.mp3

MAP4/violin.mp3
#EXTINF:102.03vln-lin-cs.mp3 MAP4/vln-lin-cs.mp3

A preset to this playlist could be:

preset_008 = /localhost/playlist1.m3u

You may also start this playlist by entering “localhost/playlist1.m3u” in the “Play” box of the web interface.

Rotary encoder interface.

The rotary encoder switch can control some essential functions of the ESP32-radio. The "GND"- and "+"-pins must be connected to ground and 3.3 Volt pins of the ESP32 DEV module.

The default function is volume control. Turning the knob will result in lower or higher volume. Pressing the knob will mute/unmute the signal. The text “Mute” or “Unmute” will be shown on the TFT during 4 seconds.

A double click selects the preset-mode. Rotation of the switch will select one of the preset stations. The preset will be shown on the TFT. Once a preset is selected, you can activate this preset by a single click.
Without rotation, the next preset is selected.

A triple click will select the mp3-player (SD card required). Rotation of the switch will select one of the tracks on the SD card. The track will be displayed on the TFT. Once a track is selected, you can activate it by a single click. Without rotation, the next track is selected.
After the triple click the player stops, as reading filenames will overload the SD card I/O.

A long click ( longer than 1 second ) will start playing random tracks from SD card.

After an inactivity of 4 seconds the rotary encoder will return to its default function (VOLUME).

Supported displays.

The preferred display is a 1.8 inch TFT with 160x128 pixels. Other displays may also be used:
1. No display. Edit the sketch (around line 123), so that “DUMMYTFT” is defined and all other display types are commented out.
2. The preferred display 160x128 pixels. Define “BLUETFT” and comment out the other types.
3. An ILI9341 display, default 320x240 pixels. Define “ILI9341” and comment out the other types.
4. A 128x128 1.44 inch display. Edit bluetft.h (around line 58), use “INITR_144GREENTAB” and set dsp_getwidth() to 128.
5. A 128x64 OLED. Define “”OLED” and comment out the other types.
6. AN LCD 1602 display with I2C backpack. Define “LCD1602I2C” and comment out the other types. Note that this display is limited as it has only 32 characters.
7. AN LCD 2004 display with I2C backpack. Define “LCD2004I2C” and comment out the other types. Note that this display is limited as it has only 80 characters.
8. A NEXTON model NX#@@$T024_11 display connected to GPIO 16 and 17.

The OLED, 2004 and 1602 displays use the serial I2C bus. There must be definitions for this in the preferences, for example:

pin_tft_scl = 13 | # GPIO Pin number for SCL
pin_tft_sda = 14 | # GPIO Pin number for SDA

Th I2C address of the 2004 and 1602 displays is defined in the corresponding module.

MQTT interface.

The MQTT interface can handle the same commands as the web interface.
As publish command on a Linux system may look like:

$ mosquitto_pub -h broker.hivemq.com -t espradio -m volume=80

Note that broker.hivemq.com is heavily used, this may cause some delay. If you use your own broker the reaction on commands will be much better.
Remove the lines starting with “mqtt” if no MQTT is required or set mqttbroker to "none".

You can use an MQTT client like https://kamilfb.github.io/mqtt-spy/ to view the MQTT interface.


Subscribe to “P82C40A24/ip” and you will see the IP-address of your radio. You will see the IP address of your radio or the IP address of a different user. So be sure to use unique names for your topics. This can be accomplished by specifying a unique prefix in the preferences, see below.
The parameters in preferences for this example are:

# MQTT broker, credentials and topic to subscribe

mqttbroker = broker.hivemq.com | # Broker to connect with
mqttprefix = P82C40A24 | # Prefix for pub/sub. Default is part of MAC-address.
mqttport = 1883 | # Portnumber (1883 is default)
mqttuser = none | # (No) username for broker
mqttpasswd = none | # (No) password for broker

In this example I published the command “mute” to the radio. The radio published the IP-address 192.168.2.8 to the broker (once every 10 minutes).

MQTT PUB topics.
In this version 7 topics will be published to MQTT and can be subscribed to by an MQTT client:
prefix/ip | The IP-address of the ESP32-Radio
prefix/icy/name | The name of the station
prefix/icy/streamtitle | The name of the stream
prefix/nowplaying | Track information
prefix/preset | Preset currently plaing
prefix/volume | Current volume setting
prefix/playing | 1 if playing, 0 if stopped

Command to control the ESP32-Radio can be published to "prefix/command".

Alternative way of configuration.
An extra sketch "Esp32_radio_init" is supplied as an alternative to initialize the preferences (in Non-Voltile Storage of the ESP32). Just change lines 39 and 40 (the specs for WiFi networks) to match your network(s).

Upload and run the sketch once and then load the ESP32-Radio.

OTA update through remote server.

The software can be update by uploading the compiled project to the ESP32. There is also a build-in feature to load the latest version of the software from a remote server. The software for the NEXTION (if in use) will also be updated.

The update can be initiated by the “update”-command through the serial interface or the webinterface.

The update will fail if there is no new version available or if no connection can be made to the server.

The radio connects to the host “smallenburg.nl” and download the file “/Arduino/Esp32_radio.ino.bin” and “/Arduino/ESP32-Radio.tft”. The binary file is flashed to the ESP32 and the NEXTION and will start the new version. The process may take some 2 to 3 minutes.

Compiler/upload output.

Multiple libraries were found for "SD.h"
Used: C:\Users\Ed\Documents\Arduino\hardware\espressif\esp32\libraries\SD
Not used: C:\Users\Ed\Documents\Arduino\libraries\SD
Not used: C:\Program Files (x86)\Arduino\libraries\SD
Using library pubsubclient-master at version 2.6 in folder: C:\Users\Ed\Documents\Arduino\ libraries\pubsubclient-master
Using library WiFi at version 1.0 in folder: C:\Users\Ed\Documents\Arduino\hardware\espressif\ esp32\libraries\WiFi
Using library ESPmDNS at version 1.0 in folder: C:\Users\Ed\Documents\Arduino\hardware\ espressif\esp32\libraries\ESPmDNS
Using library FS at version 1.0 in folder: C:\Users\Ed\Documents\Arduino\hardware\espressif\ esp32\libraries\FS
Using library SD at version 1.0.5 in folder: C:\Users\Ed\Documents\Arduino\hardware\espressif\ esp32\libraries\SD
Using library SPI at version 1.0 in folder: C:\Users\Ed\Documents\Arduino\hardware\espressif\ esp32\libraries\SPI
Using library ArduinoOTA at version 1.0 in folder: C:\Users\Ed\Documents\Arduino\hardware\ espressif\esp32\libraries\ArduinoOTA
Using library Update at version 1.0 in folder: C:\Users\Ed\Documents\Arduino\hardware\espressif\ esp32\libraries\Update
Using library Adafruit_ST7735_Library at version 1.0.8 in folder: C:\Users\Ed\Documents\Arduino\ libraries\Adafruit_ST7735_Library
Using library Adafruit_GFX_Library at version 1.2.3 in folder: C:\Users\Ed\Documents\Arduino\ libraries\Adafruit_GFX_Library
Sketch uses 626166 bytes (47%) of program storage space. Maximum is 1310720 bytes.
Global variables use 60560 bytes (20%) of dynamic memory, leaving 234352 bytes for local variables. Maximum is 294912 bytes. C:\Users\Ed\Documents\Arduino\hardware\espressif\esp32/tools/esptool.exe --chip esp32 --port COM4 --baud 921600 --before default_reset --after hard_reset write_flash -z --flash_mode dio --flash_freq 80m --flash_size detect 0xe000 C:\Users\Ed\Documents\Arduino\hardware\espressif\ esp32/tools/partitions/boot_app0.bin 0x1000 C:\Users\Ed\Documents\Arduino\hardware\espressif\ esp32/tools/sdk/bin/bootloader_qio_80m.bin 0x10000 C:\Users\Ed\AppData\Local\Temp\ arduino_build_314736/Esp32_radio.ino.bin 0x8000 C:\Users\Ed\AppData\Local\Temp\ arduino_build_314736/Esp32_radio.ino.partitions.bin
esptool.py v2.1
Connecting........__
Chip is ESP32D0WDQ6 (revision 0)
Uploading stub...
Running stub...
Stub running...
Changing baud rate to 921600 Changed.
Configuring flash size...
Auto-detected Flash size: 4MB
Compressed 8192 bytes to 47...

Writing at 0x0000e000... (100 %)
Wrote 8192 bytes (47 compressed) at 0x0000e000 in 0.0 seconds (effective 5461.3 kbit/s)... Hash of data verified.
Compressed 14128 bytes to 9213...

Writing at 0x00001000... (100 %)
Wrote 14128 bytes (9213 compressed) at 0x00001000 in 0.1 seconds (effective 904.2 kbit/s)... Hash of data verified.
Compressed 627312 bytes to 389180...

Writing at 0x00010000... (4 %)
Writing at 0x0006c000... (100 %)
Wrote 627312 bytes (389180 compressed) at 0x00010000 in 6.4 seconds (effective 784.4 kbit/s)... Hash of data verified.
Compressed 3072 bytes to 122...

Writing at 0x00008000... (100 %)
Wrote 3072 bytes (122 compressed) at 0x00008000 in 0.0 seconds (effective 1638.4 kbit/s)... Hash of data verified.

Leaving...
Hard resetting...

Debug (serial 115200 Baud) output.

This is an example of the debug output.

ets Jun 8 2016 00:22:57

rst:0x10 (RTCWDT_RTC_RESET),boot:0x17 (SPI_FAST_FLASH_BOOT)
configsip: 0, SPIWP:0xee
clk_drv:0x00,q_drv:0x00,d_drv:0x00,cs0_drv:0x00,hd_drv:0x00,wp_drv:0x00 mode:DIO, clock div:1
load:0x3fff0018,len:4
load:0x3fff001c,len:952
load:0x40078000,len:6084
load:0x40080000,len:7936
entry 0x40080310

D: Starting ESP32-radio running on CPU 1 at 240 MHz. Version Tue, 31 July 2018 09:30:00 GMT. Free memory 238656 D: Display type is BLUETFT
D: Partition nvs found, 20480 bytes
D: Read 49 keys from NVS
D: pin_ir set to 35
D: pin_enc_clk set to 25
D: pin_enc_dt set to 26
D: pin_enc_sw set to 27
D: pin_tft_cs set to 15
D: pin_tft_dc set to 2
D: pin_tft_scl set to 13
D: pin_tft_sda set to 14
D: pin_tft_bl set to -1
D: pin_tft_blx set to 33
D: pin_sd_cs set to 21
D: pin_vs_cs set to 5
D: pin_vs_dcs set to 16
D: pin_vs_dreq set to 4
D: pin_shutdown set to -1
D: pin_shutdownx set to -1 D: pin_spi_sck set to 18
D: pin_spi_miso set to 19
D: pin_spi_mosi set to 23
D: GPIO0 is HIGH
D: GPIO2 is HIGH
D: GPIO4 is HIGH
D: GPIO5 is HIGH
D: GPIO12 is HIGH
D: GPIO13 is HIGH
D: GPIO14 is HIGH
D: GPIO15 is HIGH
D: GPIO16 is HIGH
D: GPIO17 is HIGH
D: GPIO18 is HIGH
D: GPIO19 is HIGH
D: GPIO21 is HIGH
D: GPIO22 is HIGH
D: GPIO23 is HIGH
D: GPIO25 is HIGH
D: GPIO26 is HIGH
D: GPIO27 is HIGH
D: GPIO32 is HIGH
D: GPIO33 is HIGH
D: GPIO34 is LOW, probably no PULL-UP D: GPIO35 is HIGH
D: GPIO39 is LOW, probably no PULL-UP D: gpio_00 will execute upvolume = 1 D: touch_05 will execute upvolume = 1 D: Level is now 65
D: Enable pin 35 for IR
D: Start display
D: Locate mp3 files on SD, may take a while... D: 495 tracks on SD
D: Create list with acceptable WiFi networks D: Added NETGEAR-11 to list of networks
D: Added SSID2 to list of networks
D: Added test to list of networks
D: Added ITG to list of networks
D: End adding networks
D: Scan Networks
D: Scan completed
D: Number of available networks: 7
D: 1 - NETGEAR-11 | Signal: -66 dBm, Encryption WPA2_PSK, Acceptable
D: 2 - KPN Fon | Signal: -81 dBm, Encryption OPEN,
D: 3 - Ziggo | Signal: -85 dBm, Encryption ????,
D: 4 - Roulet 9 Gast | Signal: -85 dBm, Encryption WPA_WPA2_PSK,
D: 5 - ADSL-11 | Signal: -86 dBm, Encryption WPA_WPA2_PSK,
D: 6 - Roulet 9 | Signal: -87 dBm, Encryption WPA2_PSK,
D: 7 - ADSL-11-EXT | Signal: -90 dBm, Encryption WPA_WPA2_PSK,
D: End of list
D: Command: clk_dst with parameter 1
D: Command: clk_offset with parameter 1
D: Command: clk_server with parameter pool.ntp.org D: Command: gpio_00 with parameter upvolume = 1 D: Command: gpio_13 with parameter downvolume = 2 D: Command: ir_40bf with parameter upvolume = 2 D: Command: ir_c03f with parameter downvolume = 2 D: Command: mqttbroker with parameter none
D: Command: mqttpasswd with parameter *******
D: Command: mqttport with parameter 1883
D: Command: mqtttpreset with parameter none D: Command: mqttuser with parameter none
D: Command: pin_enc_clk with parameter 25 D: Command: pin_enc_dt with parameter 26 D: Command: pin_enc_sw with parameter 27 D: Command: pin_ir with parameter 35
D: Command: pin_sd_cs with parameter 21 D: Command: pin_tft_blx with parameter 33 D: Command: pin_tft_cs with parameter 15 D: Command: pin_tft_dc with parameter 2 D: Command: pin_tft_scl with parameter 13 D: Command: pin_tft_sda with parameter 14 D: Command: pin_vs_cs with parameter 5 D: Command: pin_vs_dcs with parameter 16

D: Command: pin_vs_dreq with parameter 4
D: Command: preset with parameter 6
D: Command: preset_00 with parameter 109.206.96.34:8100
D: Command: preset_01 with parameter airspectrum.cdnstream1.com:8114/1648_128 D: Command: preset_02 with parameter us2.internet-radio.com:8050
D: Command: preset_03 with parameter airspectrum.cdnstream1.com:8000/1261_192 D: Command: preset_04 with parameter airspectrum.cdnstream1.com:8008/1604_128 D: Command: preset_05 with parameter us1.internet-radio.com:8105
D: Command: preset_06 with parameter icecast.omroep.nl:80/radio1-bb-mp3
D: Command: preset_07 with parameter 205.164.62.15:10032
D: Command: preset_08 with parameter skonto.ls.lv:8002/mp3
D: Command: preset_09 with parameter 94.23.66.155:8106
D: Command: preset_10 with parameter ihr/IHR_IEDM
D: Command: preset_11 with parameter ihr/IHR_TRAN
D: Command: preset_12 with parameter 178.79.158.160:8424/stream D: Command: toneha with parameter 0
D: Command: tonehf with parameter 0
D: Command: tonela with parameter 0
D: Command: tonelf with parameter 0
D: Command: touch_05 with parameter upvolume = 1
D: Command: volume with parameter 73
D: Slow SPI, Testing VS1053 read/write registers...
D: Fast SPI, Testing VS1053 read/write registers again... D: endFillByte is 0
D: Connect to WiFi
D: Connected to NETGEAR-11
D: IP = 192.168.2.18
D: Start server for commands
D: Network found. Starting mqtt and OTA D: MDNS responder started
D: Rotary encoder is enabled
D: Sync TOD
D: Sync TOD, new value is 13:13:06
D: STOP requested
D: New preset/file requested (6/0) from icecast.omroep.nl:80/radio1-bb-mp3 D: Connect to new host icecast.omroep.nl:80/radio1-bb-mp3
D: Connect to icecast.omroep.nl on port 80, extension /radio1-bb-mp3
D: Connected to server
D: Duration mp3loop 1
D: Switch to HEADER
D: Headerline: Content-Type: audio/mpeg
D: audio/mpeg seen.
D: Headerline: icy-br:192
D: Headerline: ice-audio-info: samplerate=48000;channels=2;bitrate=192 D: Headerline: icy-br:192
D: Headerline: icy-genre:Talk
D: Headerline: icy-metadata:1
D: Headerline: icy-name:NPO Radio1
D: Headerline: icy-pub:0
D: Headerline: icy-url:http://www.radio1.nl
D: Headerline: Server: Icecast 2.4.0-kh8
D: Headerline: Cache-Control: no-cache, no-store
D: Headerline: Access-Control-Allow-Origin: *
D: Headerline: Access-Control-Allow-Headers: Origin, Accept, X-Requested-With, Content-Type D: l-Allow-Headers: Origin, Accept, X-Requested-With, Content-Type seen.
D: Headerline: Access-Control-Allow-Methods: GET, OPTIONS, HEAD
D: Headerline: Connection: Close
D: Headerline: Expires: Mon, 26 Jul 1997 05:00:00 GMT
D: Headerline: icy-metaint:16000
D: Switch to DATA, bitrate is 192, metaint is 16000 D: Duration mp3loop 71
D: Metadata block 64 bytes
D: Streamtitle found, 51 bytes
D: StreamTitle='NPO Radio 1 - De Nieuws BV - BNNVARA';

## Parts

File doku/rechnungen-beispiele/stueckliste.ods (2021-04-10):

Source: | /home/martin/elektronik/radios/saba fernbedienung/cad/pcb/saba-fernbedienung/rev1-a/saba-fernbedienung.sch
Date: | Sat 16 Jan 2021 14:11:25 CET
Tool: | Eeschema 5.1.9-73d0e3b20d~88~ubuntu18.04.1
Generator: | /usr/share/kicad/plugins/bom_csv_grouped_by_value.py
Component Count: | 228
Individual Components:
Item | Qty | Reference(s) | Value | LibPart | Footprint | Bauteil | Placement | Voltage
 |  | C301 | 100n | Device:C | Capacitor_SMD:C_0603_1608Metric | WE 885382206004
 |  | C302 | 10u | Device:C | Capacitor_SMD:C_1206_3216Metric | WE 885012208069
 |  | C303 | 100n | Device:C | Capacitor_SMD:C_0603_1608Metric | WE 885382206004 | NP
 |  | C304 | 100n | Device:C | Capacitor_SMD:C_0603_1608Metric | WE 885382206004
 |  | C401 | 150p | Device:C | Capacitor_SMD:C_0603_1608Metric | WE 885012206103
 |  | C402 | 100n | Device:C | Capacitor_SMD:C_0603_1608Metric | WE 885382206004
 |  | C403 | 1000u | Device:CP | Capacitor_THT:CP_Radial_D10.0mm_P5.00mm | WE 860020375017 |  | 16V
 |  | C404 | 10u | Device:C | Capacitor_SMD:C_1206_3216Metric | WE 885012208069
 |  | C405 | 10u | Device:C | Capacitor_SMD:C_1206_3216Metric | WE 885012208069
 |  | C406 | 100n | Device:C | Capacitor_SMD:C_0603_1608Metric | WE 885382206004
 |  | C407 | 220u | Device:CP | local:CP_Radial_D10.0mm_P5.00mm_liegend | WE 860020675020 |  | 10V
 |  | C408 | 100n | Device:C | Capacitor_SMD:C_0603_1608Metric | WE 885382206004
 |  | C409 | 220p | Device:C | Capacitor_SMD:C_0603_1608Metric | WE 885012206079
 |  | C410 | 220u | Device:CP | Capacitor_THT:CP_Radial_D10.0mm_P5.00mm | WE 860020675020 |  | 50V
 |  | C411 | 100n | Device:C | Capacitor_SMD:C_0603_1608Metric | WE 885382206004
 |  | C412 | 10u | Device:C | Capacitor_SMD:C_1206_3216Metric | WE 885012208069
 |  | C413 | 10u | Device:C | Capacitor_SMD:C_1206_3216Metric | WE 885012208069
 |  | C414 | 10u | Device:C | Capacitor_SMD:C_1206_3216Metric | WE 885012208069
 |  | C415 | 10u | Device:C | Capacitor_SMD:C_1206_3216Metric | WE 885012208069
 |  | C416 | 10u | Device:C | Capacitor_SMD:C_1206_3216Metric | WE 885012208069
 |  | C417 | 10u | Device:C | Capacitor_SMD:C_1206_3216Metric | WE 885012208069
 |  | C418 | 220u | Device:CP | Capacitor_THT:CP_Radial_D10.0mm_P5.00mm | WE 860020675020 |  | 50V
 |  | C419 | 100n | Device:C | Capacitor_SMD:C_0603_1608Metric | WE 885382206004
 |  | C501 | 100n | Device:C | Capacitor_SMD:C_0603_1608Metric | WE 885382206004
 |  | C502 | 100n | Device:C | Capacitor_SMD:C_0603_1608Metric | WE 885382206004
 |  | C503 | 470n | Device:C | Capacitor_SMD:C_0805_2012Metric | WE 885012207102
 |  | C504 | 470n | Device:C | Capacitor_SMD:C_0805_2012Metric | WE 885012207102
 |  | C505 | 470n | Device:C | Capacitor_SMD:C_0805_2012Metric | WE 885012207102
 |  | C506 | 100n | Device:C | Capacitor_SMD:C_0603_1608Metric | WE 885382206004
 |  | C507 | 100n | Device:C | Capacitor_SMD:C_0603_1608Metric | WE 885382206004
 |  | C508 | 100n | Device:C | Capacitor_SMD:C_0603_1608Metric | WE 885382206004
 |  | C601 | 100n | Device:C | Capacitor_SMD:C_0603_1608Metric | WE 885382206004
 |  | C701 | 100n | Device:C | Capacitor_SMD:C_0603_1608Metric | WE 885382206004
 |  | C702 | 100n | Device:C | Capacitor_SMD:C_0603_1608Metric | WE 885382206004
 |  | C703 | 100n | Device:C | Capacitor_SMD:C_0603_1608Metric | WE 885382206004
 |  | C704 | 100n | Device:C | Capacitor_SMD:C_0603_1608Metric | WE 885382206004
 |  | C705 | 1u | Device:C | Capacitor_SMD:C_0805_2012Metric | WE 885012207078
 |  | C706 | 10u | Device:C | Capacitor_SMD:C_1206_3216Metric | WE 885012208069
 |  | C707 | 100n | Device:C | Capacitor_SMD:C_0603_1608Metric | WE 885382206004
 |  | C708 | 100n | Device:C | Capacitor_SMD:C_0603_1608Metric | WE 885382206004
 |  | C709 | 100n | Device:C | Capacitor_SMD:C_0603_1608Metric | WE 885382206004
 |  | C710 | 100n | Device:C | Capacitor_SMD:C_0603_1608Metric | WE 885382206004
 |  | C711 | 100n | Device:C | Capacitor_SMD:C_0603_1608Metric | WE 885382206004
 |  | C712 | 100n | Device:C | Capacitor_SMD:C_0603_1608Metric | WE 885382206004
 |  | C713 | 100n | Device:C | Capacitor_SMD:C_0603_1608Metric | WE 885382206004
 |  | C714 | 22p | Device:C | Capacitor_SMD:C_0603_1608Metric | WE 885012206079
 |  | C715 | 22p | Device:C | Capacitor_SMD:C_0603_1608Metric | WE 885012206079
 |  | C716 | 1u | Device:C | Capacitor_SMD:C_0805_2012Metric | WE 885012207078
 |  | C717 | 1u | Device:C | Capacitor_SMD:C_0805_2012Metric | WE 885012207078
 |  | C718 | 100n | Device:C | Capacitor_SMD:C_0603_1608Metric | WE 885382206004
 |  | C719 | 1u | Device:C | Capacitor_SMD:C_0805_2012Metric | WE 885012207078
 |  | C720 | 1u | Device:C | Capacitor_SMD:C_0805_2012Metric | WE 885012207078
 |  | C721 | 47n | Device:C | Capacitor_SMD:C_0603_1608Metric | WE 885012206093
 |  | C722 | 10n | Device:C | Capacitor_SMD:C_0603_1608Metric | WE 885012206089
 |  | C723 | 10n | Device:C | Capacitor_SMD:C_0603_1608Metric | WE 885012206089
 |  | C724 | 10u | Device:C | Capacitor_SMD:C_1206_3216Metric | WE 885012208069
 |  | C725 | 100n | Device:C | Capacitor_SMD:C_0603_1608Metric | WE 885382206004
 |  | D201 | LED | Device:LED | LED_SMD:LED_0805_2012Metric | WE 150080BS75000
 |  | D301 | 5V | Device:D_TVS_x2_AAC | Package_TO_SOT_SMD:SOT-323_SC-70 | Diodes D5V0L2B3W
 |  | D302 | B140-E3 | Diode:B140-E3 | Diode_SMD:D_SMA | Vishay B140-E3/61T | NP
 |  | D303 | SMAJ5.0A | Diode:SM6T6V8A | Diode_SMD:D_SMA | SMAJ5.0A-13-F | NP
 |  | D401 | B140-E3 | Diode:B140-E3 | Diode_SMD:D_SMA | Vishay B140-E3/61T
 |  | D402 | B140-E3 | Diode:B140-E3 | Diode_SMD:D_SMA | Vishay B140-E3/61T
 |  | D403 | B140-E3 | Diode:B140-E3 | Diode_SMD:D_SMA | Vishay B140-E3/61T
 |  | D404 | B140-E3 | Diode:B140-E3 | Diode_SMD:D_SMA | Vishay B140-E3/61T
 |  | D405 | 1N4007 | Device:D | Diode_SMD:D_SMA | 1N4007FLTR
 |  | D406 | 1N4007 | Device:D | Diode_SMD:D_SMA | 1N4007FLTR
 |  | D501 | 1N4148 | Device:D | Diode_SMD:D_SOD-323F | ON 1N4148WS
 |  | D502 | 1N4148 | Device:D | Diode_SMD:D_SOD-323F | ON 1N4148WS
 |  | D503 | SMAJ33CA | Device:D_TVS | Diode_SMD:D_SMA | Diodes SMAJ33CAQ-13-F
 |  | D504 | SMAJ33CA | Device:D_TVS | Diode_SMD:D_SMA | Diodes SMAJ33CAQ-13-F
 |  | D505 | LED | Device:LED | LED_SMD:LED_0805_2012Metric | WE 150080BS75000
 |  | D506 | LED | Device:LED | LED_SMD:LED_0805_2012Metric | WE 150080BS75000
 |  | D507 | LED | Device:LED | LED_SMD:LED_0805_2012Metric | WE 150080BS75000
 |  | D601 | 1N4148 | Device:D | Diode_SMD:D_SOD-323F | ON 1N4148WS
 |  | D602 | 1N4148 | Device:D | Diode_SMD:D_SOD-323F | ON 1N4148WS
 |  | D603 | 1N4148 | Device:D | Diode_SMD:D_SOD-323F | ON 1N4148WS
 |  | D604 | 1N4148 | Device:D | Diode_SMD:D_SOD-323F | ON 1N4148WS
 |  | D605 | 1N4148 | Device:D | Diode_SMD:D_SOD-323F | ON 1N4148WS
 |  | D606 | 1N4148 | Device:D | Diode_SMD:D_SOD-323F | ON 1N4148WS
 |  | D607 | 1N4148 | Device:D | Diode_SMD:D_SOD-323F | ON 1N4148WS
 |  | D608 | 1N4148 | Device:D | Diode_SMD:D_SOD-323F | ON 1N4148WS
 |  | D609 | 1N4148 | Device:D | Diode_SMD:D_SOD-323F | ON 1N4148WS
 |  | D610 | LED | Device:LED | LED_SMD:LED_0805_2012Metric | WE 150080BS75000
 |  | J201 | Conn_ARM_JTAG_SWD_10 | Connector:Conn_ARM_JTAG_SWD_10 | Connector_PinHeader_1.27mm:PinHeader_2x05_P1.27mm_Vertical |  | NP
 |  | J301 | Conn_01x04 | Connector_Generic:Conn_01x04 | Connector_PinHeader_2.54mm:PinHeader_1x04_P2.54mm_Vertical
 |  | J302 | Conn_01x04 | Connector_Generic:Conn_01x04 | Connector_PinHeader_2.54mm:PinHeader_1x04_P2.54mm_Vertical
 |  | J303 | Micro_SD_Card | Connector:Micro_SD_Card | Connector_Card:microSD_HC_Hirose_DM3AT-SF-PEJM5 | Hirose DM3AT-SF-PEJM5
 |  | J304 | Conn_01x04 | Connector_Generic:Conn_01x04 | Connector_PinHeader_2.54mm:PinHeader_1x04_P2.54mm_Vertical
 |  | J305 | AudioJack3 | Connector:AudioJack3 | Connector_Audio:Jack_3.5mm_CUI_SJ-3523-SMT_Horizontal | CUI SJ-3523-SMT-TR
 |  | J306 | Conn_01x02 | Connector_Generic:Conn_01x02 | Connector_PinHeader_2.54mm:PinHeader_1x02_P2.54mm_Vertical
 |  | J307 | Conn_01x04 | Connector_Generic:Conn_01x04 | Connector_PinHeader_2.54mm:PinHeader_1x04_P2.54mm_Vertical
 |  | J308 | Conn_01x01 | Connector_Generic:Conn_01x01 | Connector_PinHeader_2.54mm:PinHeader_1x01_P2.54mm_Vertical
 |  | J309 | Conn_01x01 | Connector_Generic:Conn_01x01 | Connector_PinHeader_2.54mm:PinHeader_1x01_P2.54mm_Vertical
 |  | J310 | Conn_01x01 | Connector_Generic:Conn_01x01 | Connector_PinHeader_2.54mm:PinHeader_1x01_P2.54mm_Vertical
 |  | J311 | Conn_01x04 | Connector_Generic:Conn_01x04 | Connector_PinHeader_2.54mm:PinHeader_1x04_P2.54mm_Vertical
 |  | J312 | Conn_01x08 | Connector_Generic:Conn_01x08 | Connector_PinHeader_2.54mm:PinHeader_2x04_P2.54mm_Vertical |  | NP
 |  | J313 | USB_C_Receptacle_USB2.0 | Connector:USB_C_Receptacle_USB2.0 | Connector_USB:USB_C_Receptacle_HRO_TYPE-C-31-M-12 | GCT USB4125-GF-A | NP
 |  | K601 | G6K-2 | Relay:G6K-2 | Relay_THT:Relay_DPDT_Omron_G6K-2P | Omron G6K-2P DC5
 |  | K602 | G6K-2 | Relay:G6K-2 | Relay_THT:Relay_DPDT_Omron_G6K-2P | Omron G6K-2P DC5
 |  | K603 | G6K-2 | Relay:G6K-2 | Relay_THT:Relay_DPDT_Omron_G6K-2P | Omron G6K-2P DC5
 |  | K604 | G6K-2 | Relay:G6K-2 | Relay_THT:Relay_DPDT_Omron_G6K-2P | Omron G6K-2P DC5
 |  | K605 | G6K-2 | Relay:G6K-2 | Relay_THT:Relay_DPDT_Omron_G6K-2P | Omron G6K-2P DC5
 |  | K606 | G6K-2 | Relay:G6K-2 | Relay_THT:Relay_DPDT_Omron_G6K-2P | Omron G6K-2P DC5
 |  | K607 | EC2-5TNU | Relay:EC2-5TNU | Relay_THT:Relay_DPDT_Kemet_EC2_DoubleCoil | Kemet EC2-5TNU
 |  | L401 | 4,7u | Device:L | local:WE-LQ | WE 744045004
 |  | L402 | 4,7u | Device:L | local:WE-LQ | WE 744045004
 |  | L701 | 4,7u | Device:L | local:WE-LQ | WE 744045004
 |  | Q201 | BC856 | Transistor_BJT:BC856 | Package_TO_SOT_SMD:SOT-23 | ON BC856BLT1G | NP
 |  | Q601 | BC846 | Transistor_BJT:BC846 | Package_TO_SOT_SMD:SOT-23 | ON BC846BLT3G
 |  | Q602 | BC846 | Transistor_BJT:BC846 | Package_TO_SOT_SMD:SOT-23 | ON BC846BLT3G
 |  | Q603 | BC846 | Transistor_BJT:BC846 | Package_TO_SOT_SMD:SOT-23 | ON BC846BLT3G
 |  | Q604 | BC846 | Transistor_BJT:BC846 | Package_TO_SOT_SMD:SOT-23 | ON BC846BLT3G
 |  | Q605 | BC846 | Transistor_BJT:BC846 | Package_TO_SOT_SMD:SOT-23 | ON BC846BLT3G
 |  | Q606 | BC846 | Transistor_BJT:BC846 | Package_TO_SOT_SMD:SOT-23 | ON BC846BLT3G
 |  | Q607 | BC846 | Transistor_BJT:BC846 | Package_TO_SOT_SMD:SOT-23 | ON BC846BLT3G
 |  | R203 | 10k | Device:R | Resistor_SMD:R_0603_1608Metric |  | NP
 |  | R204 | 1k | Device:R | Resistor_SMD:R_0603_1608Metric
 |  | R205 | 100 | Device:R | Resistor_SMD:R_0603_1608Metric |  | NP
 |  | R206 | 100 | Device:R | Resistor_SMD:R_0603_1608Metric |  | NP
 |  | R207 | 100 | Device:R | Resistor_SMD:R_0603_1608Metric |  | NP
 |  | R208 | 100 | Device:R | Resistor_SMD:R_0603_1608Metric |  | NP
 |  | R301 | 1k | Device:R | Resistor_SMD:R_0603_1608Metric
 |  | R302 | 1k | Device:R | Resistor_SMD:R_0603_1608Metric
 |  | R303 | 0 | Device:R | Resistor_SMD:R_0603_1608Metric |  | NP
 |  | R304 | 1M | Device:R | Resistor_SMD:R_0603_1608Metric
 |  | R305 | 100 | Device:R | Resistor_SMD:R_0603_1608Metric
 |  | R306 | 5k1 | Device:R | Resistor_SMD:R_0603_1608Metric |  | NP
 |  | R307 | 5k1 | Device:R | Resistor_SMD:R_0603_1608Metric |  | NP
 |  | R308 | 1M | Device:R | Resistor_SMD:R_0603_1608Metric |  | NP
 |  | R401 | 220 | Device:R | Resistor_SMD:R_0603_1608Metric
 |  | R402 | 470 | Device:R | Resistor_SMD:R_0603_1608Metric
 |  | R501 | 100k | Device:R | Resistor_SMD:R_0603_1608Metric
 |  | R502 | 22k | Device:R | Resistor_SMD:R_0603_1608Metric
 |  | R503 | 100k | Device:R | Resistor_SMD:R_0603_1608Metric
 |  | R504 | 1k | Device:R | Resistor_SMD:R_0603_1608Metric
 |  | R505 | 1k | Device:R | Resistor_SMD:R_0603_1608Metric
 |  | R506 | 100k | Device:R | Resistor_SMD:R_0603_1608Metric
 |  | R507 | 470k | Device:R | Resistor_SMD:R_0603_1608Metric
 |  | R508 | 22k | Device:R | Resistor_SMD:R_0603_1608Metric
 |  | R509 | 100k | Device:R | Resistor_SMD:R_0603_1608Metric
 |  | R510 | 100k | Device:R | Resistor_SMD:R_0603_1608Metric
 |  | R511 | 68k | Device:R | Resistor_SMD:R_0603_1608Metric
 |  | R512 | 1k | Device:R | Resistor_SMD:R_0603_1608Metric
 |  | R513 | 1k | Device:R | Resistor_SMD:R_0603_1608Metric
 |  | R514 | 27k | Device:R | Resistor_SMD:R_0603_1608Metric
 |  | R515 | 1k | Device:R | Resistor_SMD:R_0603_1608Metric
 |  | R516 | 1k | Device:R | Resistor_SMD:R_0603_1608Metric
 |  | R517 | 10k | Device:R | Resistor_SMD:R_0603_1608Metric
 |  | R518 | 10k | Device:R | Resistor_SMD:R_0603_1608Metric
 |  | R519 | 68k | Device:R | Resistor_SMD:R_0603_1608Metric
 |  | R520 | 470k | Device:R | Resistor_SMD:R_0603_1608Metric
 |  | R521 | 3k3 | Device:R | Resistor_SMD:R_0603_1608Metric
 |  | R522 | 1M | Device:R | Resistor_SMD:R_0603_1608Metric |  | NP
 |  | R523 | 120k | Device:R | Resistor_SMD:R_0603_1608Metric
 |  | R524 | 1M | Device:R | Resistor_SMD:R_0603_1608Metric |  | NP
 |  | R525 | 22k | Device:R | Resistor_SMD:R_0603_1608Metric
 |  | R526 | 22k | Device:R | Resistor_SMD:R_0603_1608Metric
 |  | R527 | 10k | Device:R | Resistor_SMD:R_0603_1608Metric
 |  | R528 | 15k | Device:R | Resistor_SMD:R_0603_1608Metric
 |  | R529 | 1k | Device:R | Resistor_SMD:R_0603_1608Metric
 |  | R530 | 1k | Device:R | Resistor_SMD:R_0603_1608Metric
 |  | R531 | 10k | Device:R | Resistor_SMD:R_0603_1608Metric
 |  | R532 | 10k | Device:R | Resistor_SMD:R_0603_1608Metric
 |  | R533 | 18k | Device:R | Resistor_SMD:R_0603_1608Metric
 |  | R534 | 8k2 | Device:R | Resistor_SMD:R_0603_1608Metric
 |  | R535 | 1M | Device:R | Resistor_SMD:R_0603_1608Metric |  | NP
 |  | R536 | 22k | Device:R | Resistor_SMD:R_0603_1608Metric
 |  | R601 | 1k | Device:R | Resistor_SMD:R_0603_1608Metric
 |  | R602 | 1k | Device:R | Resistor_SMD:R_0603_1608Metric
 |  | R603 | 1k | Device:R | Resistor_THT:R_Axial_DIN0207_L6.3mm_D2.5mm_P7.62mm_Horizontal
 |  | R604 | 100k | Device:R | Resistor_SMD:R_0603_1608Metric
 |  | R605 | 100k | Device:R | Resistor_SMD:R_0603_1608Metric
 |  | R606 | 12k | Device:R | Resistor_SMD:R_0603_1608Metric
 |  | R607 | 1k | Device:R | Resistor_SMD:R_0603_1608Metric
 |  | R608 | 1k | Device:R | Resistor_SMD:R_0603_1608Metric
 |  | R609 | 10k | Device:R | Resistor_SMD:R_0603_1608Metric
 |  | R610 | 100k | Device:R | Resistor_SMD:R_0603_1608Metric
 |  | R611 | 100k | Device:R | Resistor_SMD:R_0603_1608Metric
 |  | R612 | 12k | Device:R | Resistor_SMD:R_0603_1608Metric
 |  | R613 | 1k | Device:R | Resistor_SMD:R_0603_1608Metric
 |  | R614 | 1k | Device:R | Resistor_SMD:R_0603_1608Metric
 |  | R615 | 100k | Device:R | Resistor_SMD:R_0603_1608Metric
 |  | R616 | 100k | Device:R | Resistor_SMD:R_0603_1608Metric
 |  | R617 | 1k | Device:R | Resistor_THT:R_Axial_DIN0207_L6.3mm_D2.5mm_P7.62mm_Horizontal
 |  | R618 | 5k7 | Device:R | Resistor_THT:R_Axial_DIN0207_L6.3mm_D2.5mm_P7.62mm_Horizontal
 |  | R619 | 1k | Device:R | Resistor_SMD:R_0603_1608Metric
 |  | R620 | 10k | Device:R | Resistor_SMD:R_0603_1608Metric
 |  | R621 | 1k | Device:R | Resistor_SMD:R_0603_1608Metric
 |  | R622 | 1k | Device:R | Resistor_SMD:R_0603_1608Metric
 |  | R623 | 100k | Device:R | Resistor_SMD:R_0603_1608Metric
 |  | R701 | 1k | Device:R | Resistor_SMD:R_0603_1608Metric
 |  | R702 | 100k | Device:R | Resistor_SMD:R_0603_1608Metric
 |  | R703 | 100k | Device:R | Resistor_SMD:R_0603_1608Metric
 |  | R704 | 100k | Device:R | Resistor_SMD:R_0603_1608Metric
 |  | R705 | 10k | Device:R | Resistor_SMD:R_0603_1608Metric
 |  | R706 | 1M | Device:R | Resistor_SMD:R_0603_1608Metric
 |  | R707 | 1M | Device:R | Resistor_SMD:R_0603_1608Metric
 |  | R708 | 1k | Device:R | Resistor_SMD:R_0603_1608Metric
 |  | R709 | 100k | Device:R | Resistor_SMD:R_0603_1608Metric
 |  | R710 | 100k | Device:R | Resistor_SMD:R_0603_1608Metric
 |  | R711 | 100 | Device:R | Resistor_SMD:R_0603_1608Metric
 |  | R712 | 100k | Device:R | Resistor_SMD:R_0603_1608Metric
 |  | R713 | 10k | Device:R | Resistor_SMD:R_0603_1608Metric
 |  | R714 | 1M | Device:R | Resistor_SMD:R_0603_1608Metric
 |  | R715 | 100 | Device:R | Resistor_SMD:R_0603_1608Metric
 |  | R716 | 10 | Device:R | Resistor_SMD:R_0603_1608Metric
 |  | R717 | 22 | Device:R | Resistor_SMD:R_0603_1608Metric
 |  | R718 | 22 | Device:R | Resistor_SMD:R_0603_1608Metric
 |  | R719 | 100k | Device:R | Resistor_SMD:R_0603_1608Metric
 |  | R720 | 100k | Device:R | Resistor_SMD:R_0603_1608Metric
 |  | R721 | 100k | Device:R | Resistor_SMD:R_0603_1608Metric
 |  | RV701 | 20k lin | Device:R_POT | Potentiometer_SMD:Potentiometer_Vishay_TS53YL_Vertical | Vishay TS53YL203MR10
 |  | RV702 | 20k lin | Device:R_POT | Potentiometer_SMD:Potentiometer_Vishay_TS53YL_Vertical | Vishay TS53YL203MR10
 |  | U201 | DOIT-DEVKITV1-ESP32-WROOM-32 | local:DOIT-DEVKITV1-ESP32-WROOM-32 | local:DOIT-DEVKITV1-ESP32-WROOM-32 | Doit ESP32 DEVKITV1 (Board mit ESP WROOM-32)
 |  | U301 | TSOP31238 | Interface_Optical:TSOP312xx | OptoDevice:Vishay_CAST-3Pin | Vishay TSOP31238
 |  | U401 | TEC2-0911 | local:TEC2-0911 | local:Converter_DCDC_TRACO_TEC2_xxxx_THT | Traco Power TEC 2-0911
 |  | U402 | 1117 1.8V | Regulator_Linear:AP1117-18 | Package_TO_SOT_SMD:SOT-223-3_TabPin2 | ST LD1117S18CTR
 |  | U403 | 1117 3.3V | Regulator_Linear:AP1117-33 | Package_TO_SOT_SMD:SOT-223-3_TabPin2 | ST LD1117S33CTR
 |  | U501 | ADA4522-2 | Device:Opamp_Dual_Generic | Package_SO:SOIC-8_3.9x4.9mm_P1.27mm | ADA4522-1ARMZ
 |  | U502 | LM339 | Comparator:LM339 | Package_SO:SOIC-14_3.9x8.7mm_P1.27mm | ON LM339DR2G
 |  | U503 | LTV-357T | Isolator:LTV-357T | Package_SO:SO-4_4.4x3.6mm_P2.54mm | Lite-On LTV-357T
 |  | U504 | LTV-357T | Isolator:LTV-357T | Package_SO:SO-4_4.4x3.6mm_P2.54mm | Lite-On LTV-357T
 |  | U505 | LTV-357T | Isolator:LTV-357T | Package_SO:SO-4_4.4x3.6mm_P2.54mm | Lite-On LTV-357T
 |  | U601 | LTV-357T | Isolator:LTV-357T | Package_SO:SO-4_4.4x3.6mm_P2.54mm | Lite-On LTV-357T
 |  | U701 | AD8656 | Device:Opamp_Dual_Generic | Package_SO:SOIC-8_3.9x4.9mm_P1.27mm | AD8656ARZ
 |  | U702 | VS1053 | local:VS1053 | Package_QFP:LQFP-48_7x7mm_P0.5mm | VLSI VS1053B
 |  | Y701 | 12,288MHz | Device:Crystal | Crystal:Crystal_SMD_HC49-SD | ABM3-12.288MHZ-D2Y-T
Collated Components:
Item | Qty | Reference(s) | Value | LibPart | Footprint | Bauteil | Placement | Voltage
15 | 5 | D302, D401, D402, D403, D404 | B140-E3 | Diode:B140-E3 | Diode_SMD:D_SMA | Vishay B140-E3/61T | NP
18 | 11 | D501, D502, D601, D602, D603, D604, D605, D606, D607, D608, D609 | 1N4148 | Device:D | Diode_SMD:D_SOD-323F | ON 1N4148WS
19 | 2 | D503, D504 | SMAJ33CA | Device:D_TVS | Diode_SMD:D_SMA | Diodes SMAJ33CAQ-13-F
20 | 1 | J201 | Conn_ARM_JTAG_SWD_10 | Connector:Conn_ARM_JTAG_SWD_10 | Connector_PinHeader_1.27mm:PinHeader_2x05_P1.27mm_Vertical |  | NP
21 | 5 | J301, J302, J304, J307, J311 | Conn_01x04 | Connector_Generic:Conn_01x04 | Connector_PinHeader_2.54mm:PinHeader_1x04_P2.54mm_Vertical
24 | 1 | J306 | Conn_01x02 | Connector_Generic:Conn_01x02 | Connector_PinHeader_2.54mm:PinHeader_1x02_P2.54mm_Vertical
25 | 3 | J308, J309, J310 | Conn_01x01 | Connector_Generic:Conn_01x01 | Connector_PinHeader_2.54mm:PinHeader_1x01_P2.54mm_Vertical
26 | 1 | J312 | Conn_01x08 | Connector_Generic:Conn_01x08 | Connector_PinHeader_2.54mm:PinHeader_2x04_P2.54mm_Vertical |  | NP
27 | 1 | J313 | USB_C_Receptacle_USB2.0 | Connector:USB_C_Receptacle_USB2.0 | Connector_USB:USB_C_Receptacle_HRO_TYPE-C-31-M-12 | GCT USB4125-GF-A | NP
28 | 6 | K601, K602, K603, K604, K605, K606 | G6K-2 | Relay:G6K-2 | Relay_THT:Relay_DPDT_Omron_G6K-2P | Omron G6K-2P DC5
31 | 1 | Q201 | BC856 | Transistor_BJT:BC856 | Package_TO_SOT_SMD:SOT-23 | ON BC856BLT1G | NP
32 | 7 | Q601, Q602, Q603, Q604, Q605, Q606, Q607 | BC846 | Transistor_BJT:BC846 | Package_TO_SOT_SMD:SOT-23 | ON BC846BLT3G
33 | 10 | R203, R517, R518, R527, R531, R532, R609, R620, R705, R713 | 10k | Device:R | Resistor_SMD:R_0603_1608Metric |  | NP
34 | 22 | R204, R301, R302, R504, R505, R512, R513, R515, R516, R529, R530, R601, R602, R607, R608, R613, R614, R619, R621, R622, R701, R708 | 1k | Device:R | Resistor_SMD:R_0603_1608Metric
35 | 7 | R205, R206, R207, R208, R305, R711, R715 | 100 | Device:R | Resistor_SMD:R_0603_1608Metric |  | NP
36 | 1 | R303 | 0 | Device:R | Resistor_SMD:R_0603_1608Metric |  | NP
37 | 8 | R304, R308, R522, R524, R535, R706, R707, R714 | 1M | Device:R | Resistor_SMD:R_0603_1608Metric |  | NP
38 | 2 | R306, R307 | 5k1 | Device:R | Resistor_SMD:R_0603_1608Metric |  | NP
39 | 1 | R401 | 220 | Device:R | Resistor_SMD:R_0603_1608Metric
40 | 1 | R402 | 470 | Device:R | Resistor_SMD:R_0603_1608Metric
41 | 21 | R501, R503, R506, R509, R510, R604, R605, R610, R611, R615, R616, R623, R702, R703, R704, R709, R710, R712, R719, R720, R721 | 100k | Device:R | Resistor_SMD:R_0603_1608Metric
42 | 5 | R502, R508, R525, R526, R536 | 22k | Device:R | Resistor_SMD:R_0603_1608Metric
43 | 2 | R507, R520 | 470k | Device:R | Resistor_SMD:R_0603_1608Metric
44 | 2 | R511, R519 | 68k | Device:R | Resistor_SMD:R_0603_1608Metric
45 | 1 | R514 | 27k | Device:R | Resistor_SMD:R_0603_1608Metric
46 | 1 | R521 | 3k3 | Device:R | Resistor_SMD:R_0603_1608Metric
47 | 1 | R523 | 120k | Device:R | Resistor_SMD:R_0603_1608Metric
48 | 1 | R528 | 15k | Device:R | Resistor_SMD:R_0603_1608Metric
49 | 1 | R533 | 18k | Device:R | Resistor_SMD:R_0603_1608Metric
50 | 1 | R534 | 8k2 | Device:R | Resistor_SMD:R_0603_1608Metric
51 | 2 | R603, R617 | 1k | Device:R | Resistor_THT:R_Axial_DIN0207_L6.3mm_D2.5mm_P7.62mm_Horizontal
52 | 2 | R606, R612 | 12k | Device:R | Resistor_SMD:R_0603_1608Metric
53 | 1 | R618 | 5k7 | Device:R | Resistor_THT:R_Axial_DIN0207_L6.3mm_D2.5mm_P7.62mm_Horizontal
54 | 1 | R716 | 10 | Device:R | Resistor_SMD:R_0603_1608Metric
55 | 2 | R717, R718 | 22 | Device:R | Resistor_SMD:R_0603_1608Metric
58 | 1 | U301 | TSOP31238 | Interface_Optical:TSOP312xx | OptoDevice:Vishay_CAST-3Pin | Vishay TSOP31238
63 | 1 | U502 | LM339 | Comparator:LM339 | Package_SO:SOIC-14_3.9x8.7mm_P1.27mm | ON LM339DR2G
64 | 4 | U503, U504, U505, U601 | LTV-357T | Isolator:LTV-357T | Package_SO:SO-4_4.4x3.6mm_P2.54mm | Lite-On LTV-357T

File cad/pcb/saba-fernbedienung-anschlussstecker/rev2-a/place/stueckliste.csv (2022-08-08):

Source: | /home/martin/elektronik/radios/saba fernbedienung/cad/pcb/saba-fernbedienung-anschlussstecker/rev2-a/saba-fernbedienung-anschlussstecker.sch
Date: | Mon 08 Aug 2022 17:44:44 CEST
Tool: | Eeschema 5.1.12-84ad8e8a86~92~ubuntu20.04.1
Generator: | /usr/share/kicad/plugins/bom_csv_grouped_by_value.py
Component Count: | 7
Individual Components:
Item | Qty | Reference(s) | Value | LibPart | Footprint | Datasheet
 |  | J101 | Conn_01x04 | Connector_Generic:Conn_01x04 | Connector_PinHeader_2.54mm:PinHeader_1x04_P2.54mm_Vertical | ~
 |  | J102 | Conn_01x04 | Connector_Generic:Conn_01x04 | Connector_PinHeader_2.54mm:PinHeader_1x04_P2.54mm_Vertical | ~
 |  | J103 | Conn_01x04 | Connector_Generic:Conn_01x04 | Connector_PinHeader_2.54mm:PinHeader_1x04_P2.54mm_Vertical | ~
 |  | J104 | Conn_01x02 | Connector_Generic:Conn_01x02 | Connector_PinHeader_2.54mm:PinHeader_1x02_P2.54mm_Vertical | ~
 |  | J105 | Conn_01x04 | Connector_Generic:Conn_01x04 | Connector_PinHeader_2.54mm:PinHeader_1x04_P2.54mm_Vertical | ~
 |  | J106 | Conn_01x04 | Connector_Generic:Conn_01x04 | Connector_PinHeader_2.54mm:PinHeader_1x04_P2.54mm_Vertical | ~
 |  | X101 | Stecker-6-3D | stecker:Stecker-6-3D | stecker:stecker-6-3d
Collated Components:
Item | Qty | Reference(s) | Value | LibPart | Footprint | Datasheet
1 | 5 | J101, J102, J103, J105, J106 | Conn_01x04 | Connector_Generic:Conn_01x04 | Connector_PinHeader_2.54mm:PinHeader_1x04_P2.54mm_Vertical | ~
2 | 1 | J104 | Conn_01x02 | Connector_Generic:Conn_01x02 | Connector_PinHeader_2.54mm:PinHeader_1x02_P2.54mm_Vertical | ~
3 | 1 | X101 | Stecker-6-3D | stecker:Stecker-6-3D | stecker:stecker-6-3d

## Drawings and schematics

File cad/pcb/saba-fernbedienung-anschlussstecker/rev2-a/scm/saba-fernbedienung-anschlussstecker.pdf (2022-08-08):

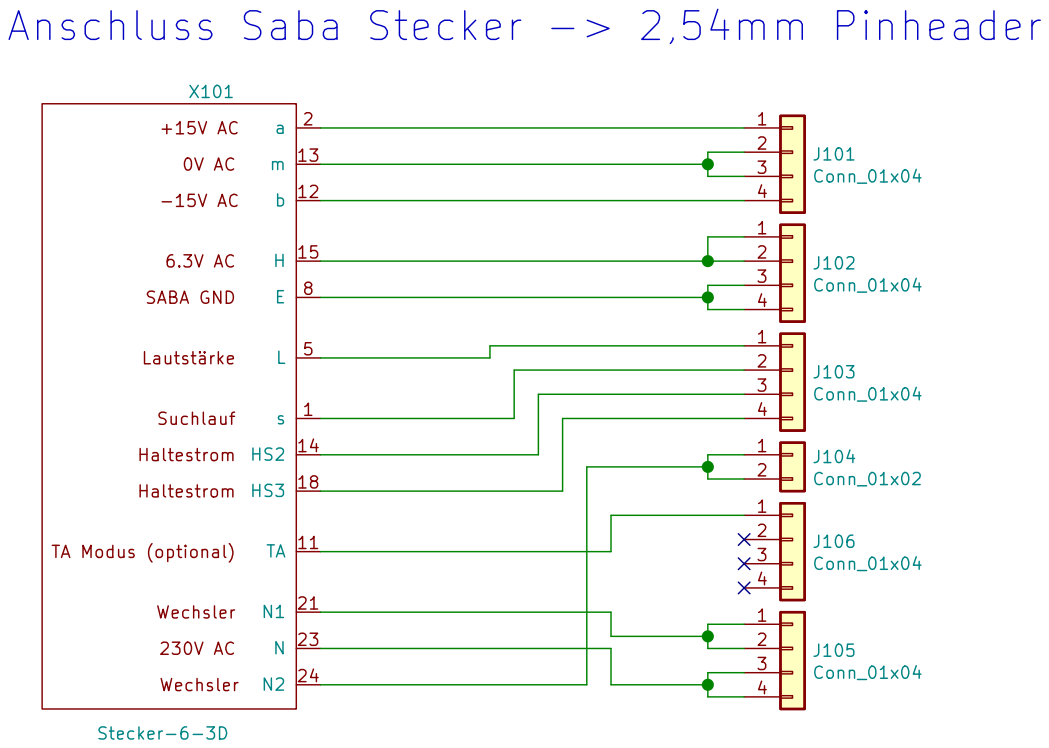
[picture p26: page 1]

J101 Conn_01x04 Anschluss Saba Stecker -> 2,54mm Pinheader

Adapter Anschlussstecker für Fernbedienung SABA
Radios 6-3D von 1955 (Meersburg, Freiburg, weitere?)

Lizenz: CERN-OHL-W (OHL v2)
File: saba-fernbedienung-anschlussstecker.sch Sheet: / Martin Wagner DL2WAG

Id: 1/1 Title: Anschlussstecker Fernbedienung SABA 6-3D

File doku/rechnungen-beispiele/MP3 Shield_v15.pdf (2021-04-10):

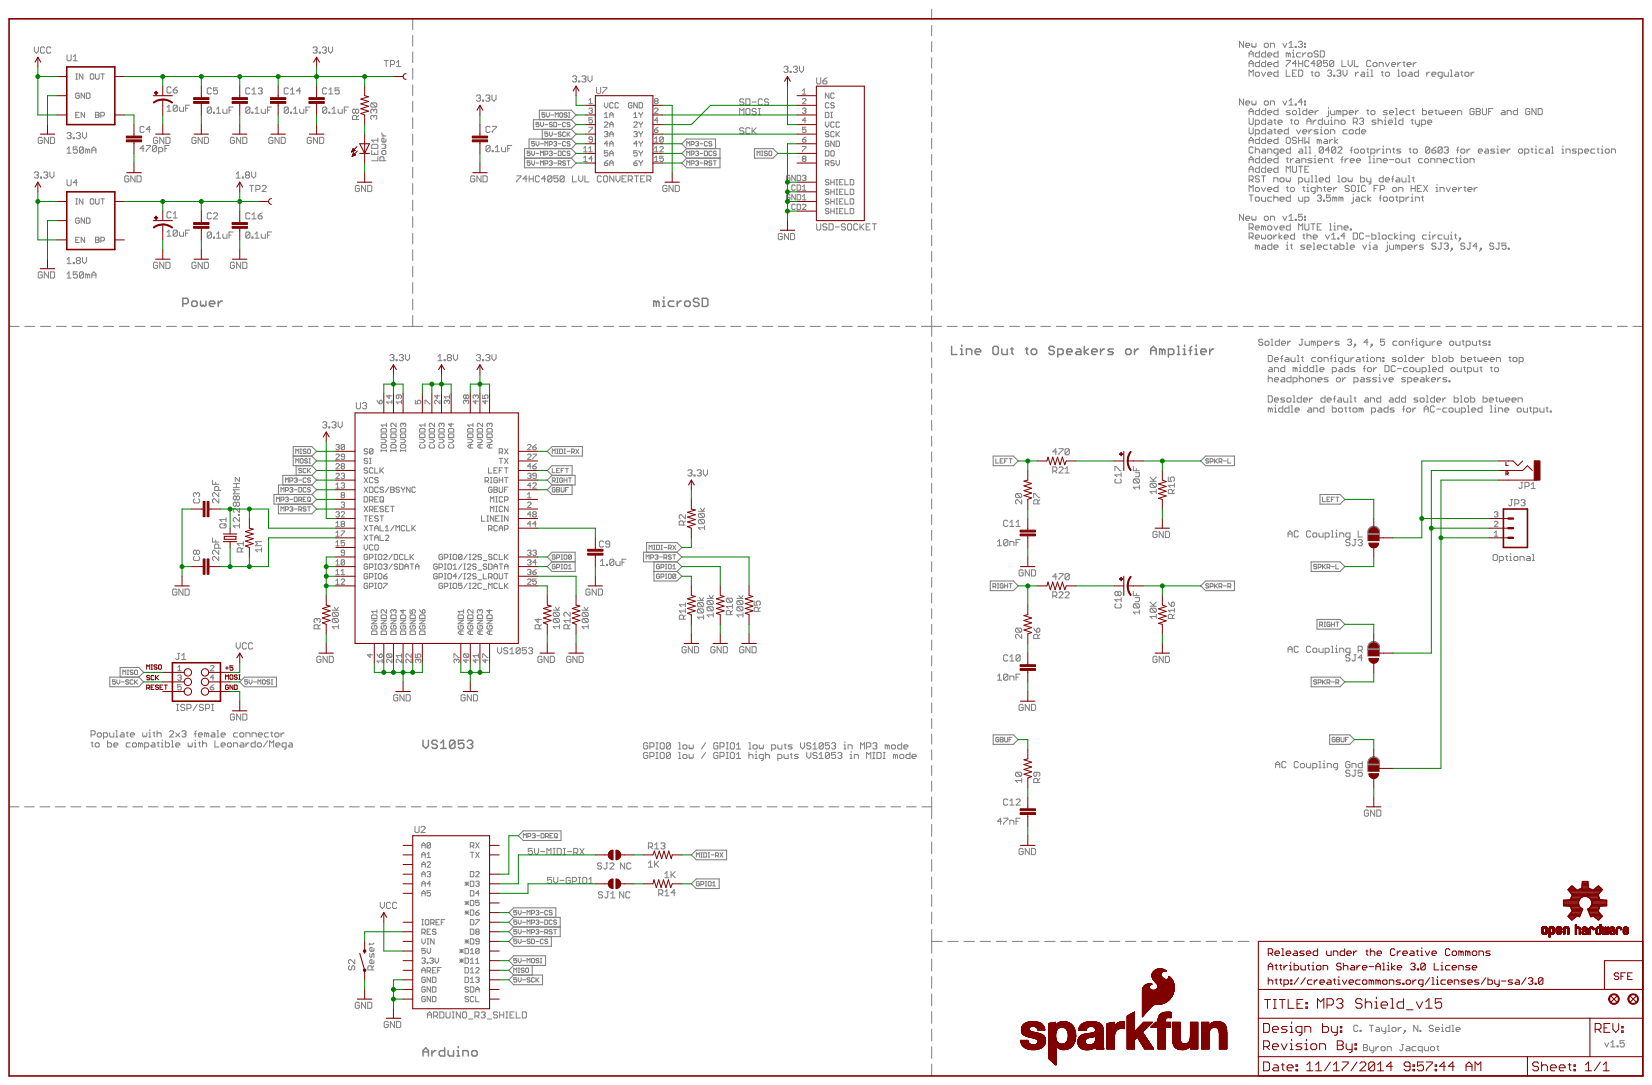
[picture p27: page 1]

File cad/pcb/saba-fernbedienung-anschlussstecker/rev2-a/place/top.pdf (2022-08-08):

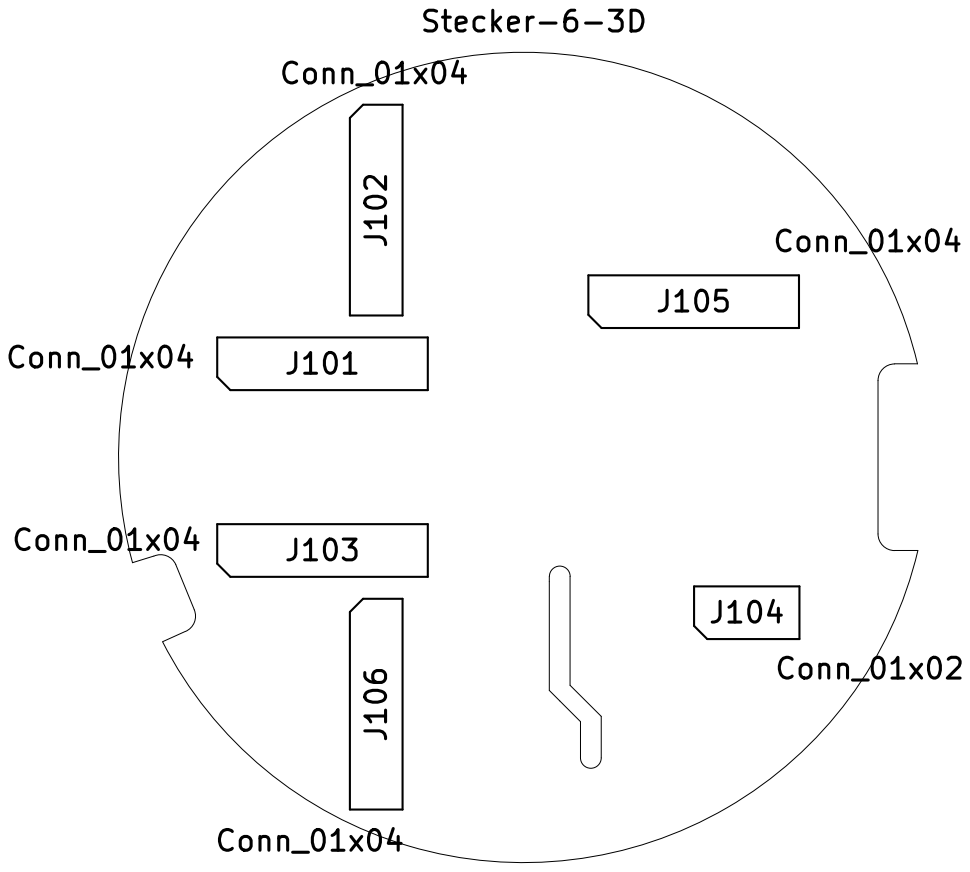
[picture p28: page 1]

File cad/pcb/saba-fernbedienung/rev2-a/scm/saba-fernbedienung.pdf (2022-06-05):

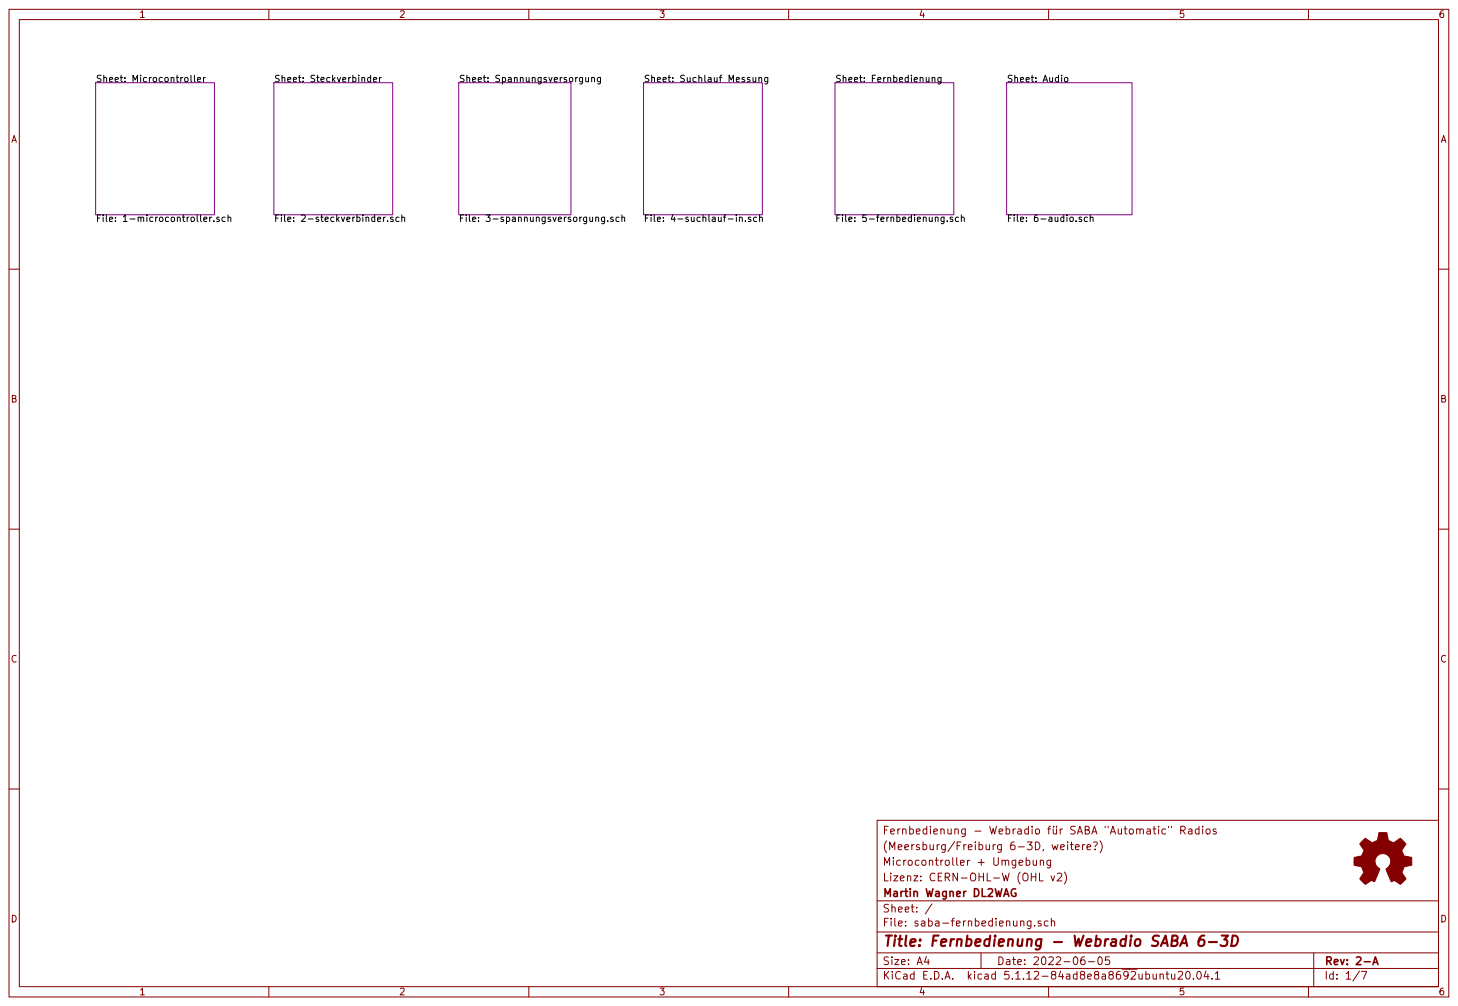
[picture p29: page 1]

Fernbedienung - Webradio für SABA "Automatic" Radios
(Meersburg/Freiburg 6-3D, weitere?)
Microcontroller + Umgebung
Lizenz: CERN-OHL-W (OHL v2)
File: saba-fernbedienung.sch Sheet: / Martin Wagner DL2WAG

Id: 1/7 Title: Fernbedienung - Webradio SABA 6-3D

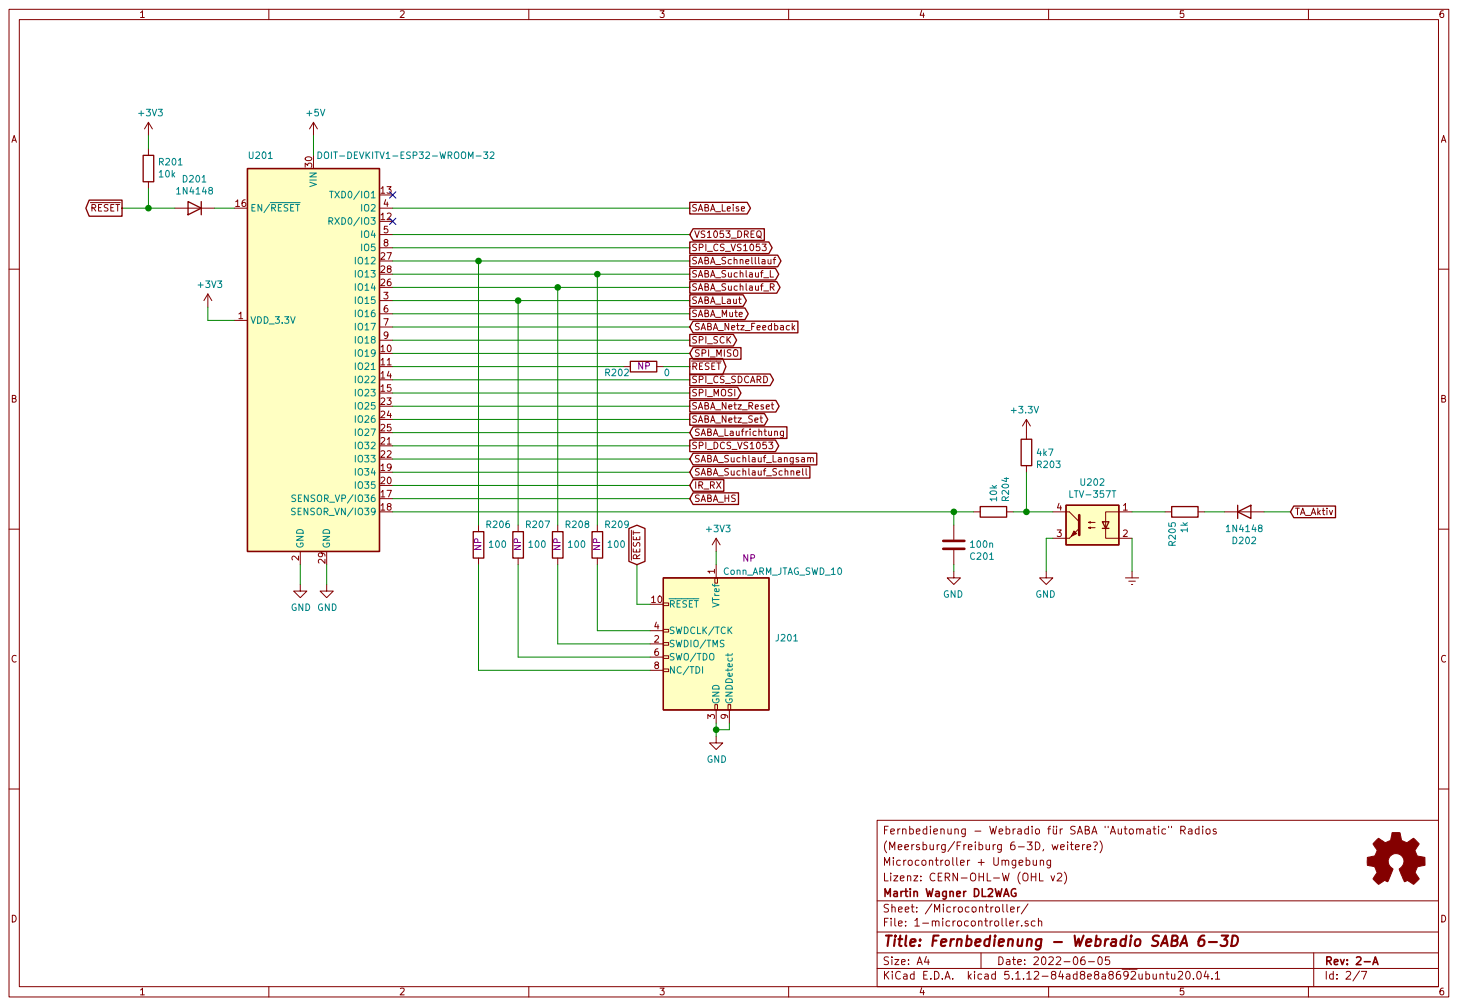
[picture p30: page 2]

3 SWDCLK/TCK 4 SWO/TDO 6 NC/TDI 8 GNDDetect 9

(Meersburg/Freiburg 6-3D, weitere?)
Microcontroller + Umgebung
Lizenz: CERN-OHL-W (OHL v2)
File: 1-microcontroller.sch Sheet: /Microcontroller/ Martin Wagner DL2WAG

Id: 2/7 Title: Fernbedienung - Webradio SABA 6-3D

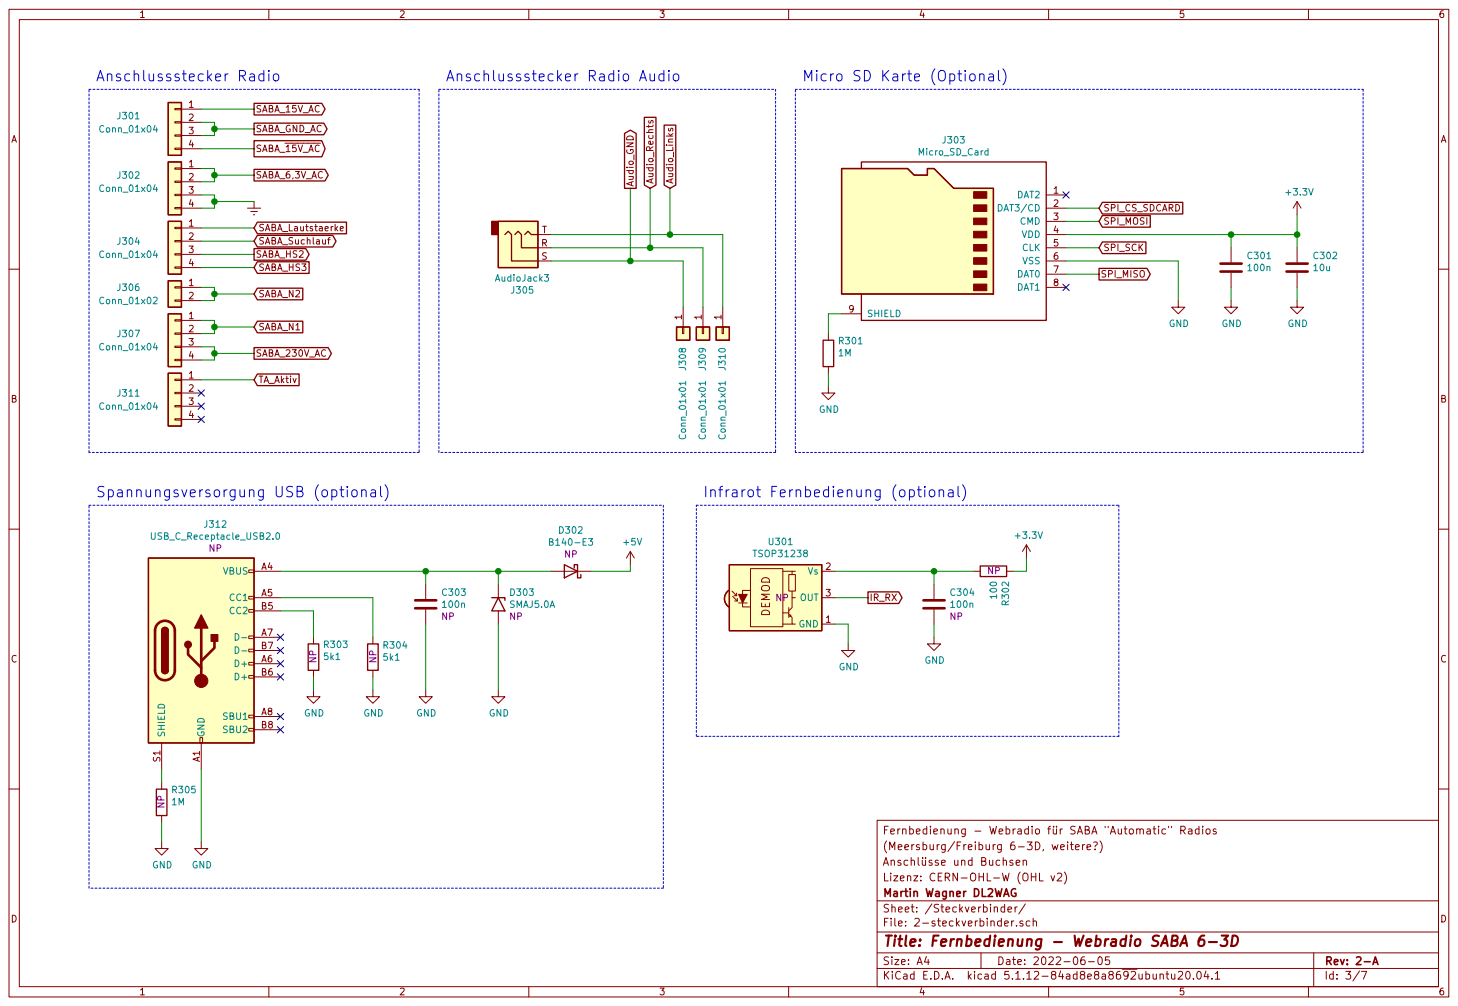
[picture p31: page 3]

Fernbedienung - Webradio für SABA "Automatic" Radios
(Meersburg/Freiburg 6-3D, weitere?)
Lizenz: CERN-OHL-W (OHL v2) Anschlüsse und Buchsen

File: 2-steckverbinder.sch Sheet: /Steckverbinder/ Martin Wagner DL2WAG

Id: 3/7 Title: Fernbedienung - Webradio SABA 6-3D

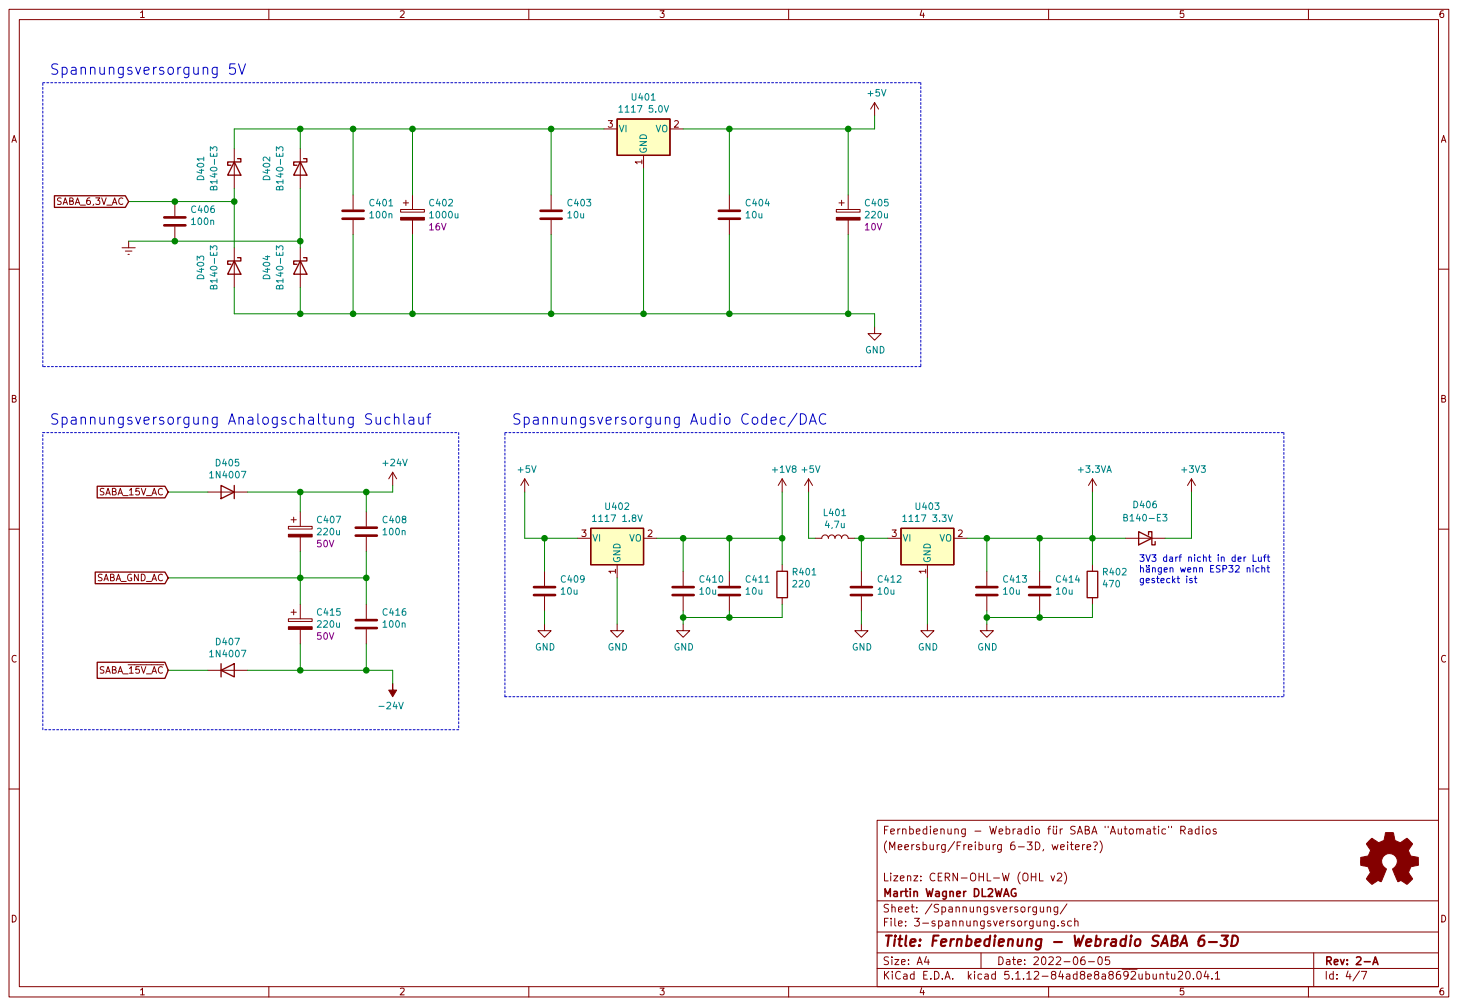
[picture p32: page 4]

Spannungsversorgung Audio Codec/DAC

Fernbedienung - Webradio für SABA "Automatic" Radios
(Meersburg/Freiburg 6-3D, weitere?)

Lizenz: CERN-OHL-W (OHL v2)
Martin Wagner DL2WAG
Sheet: /Spannungsversorgung/
File: 3-spannungsversorgung.sch
Id: 4/7 Title: Fernbedienung - Webradio SABA 6-3D

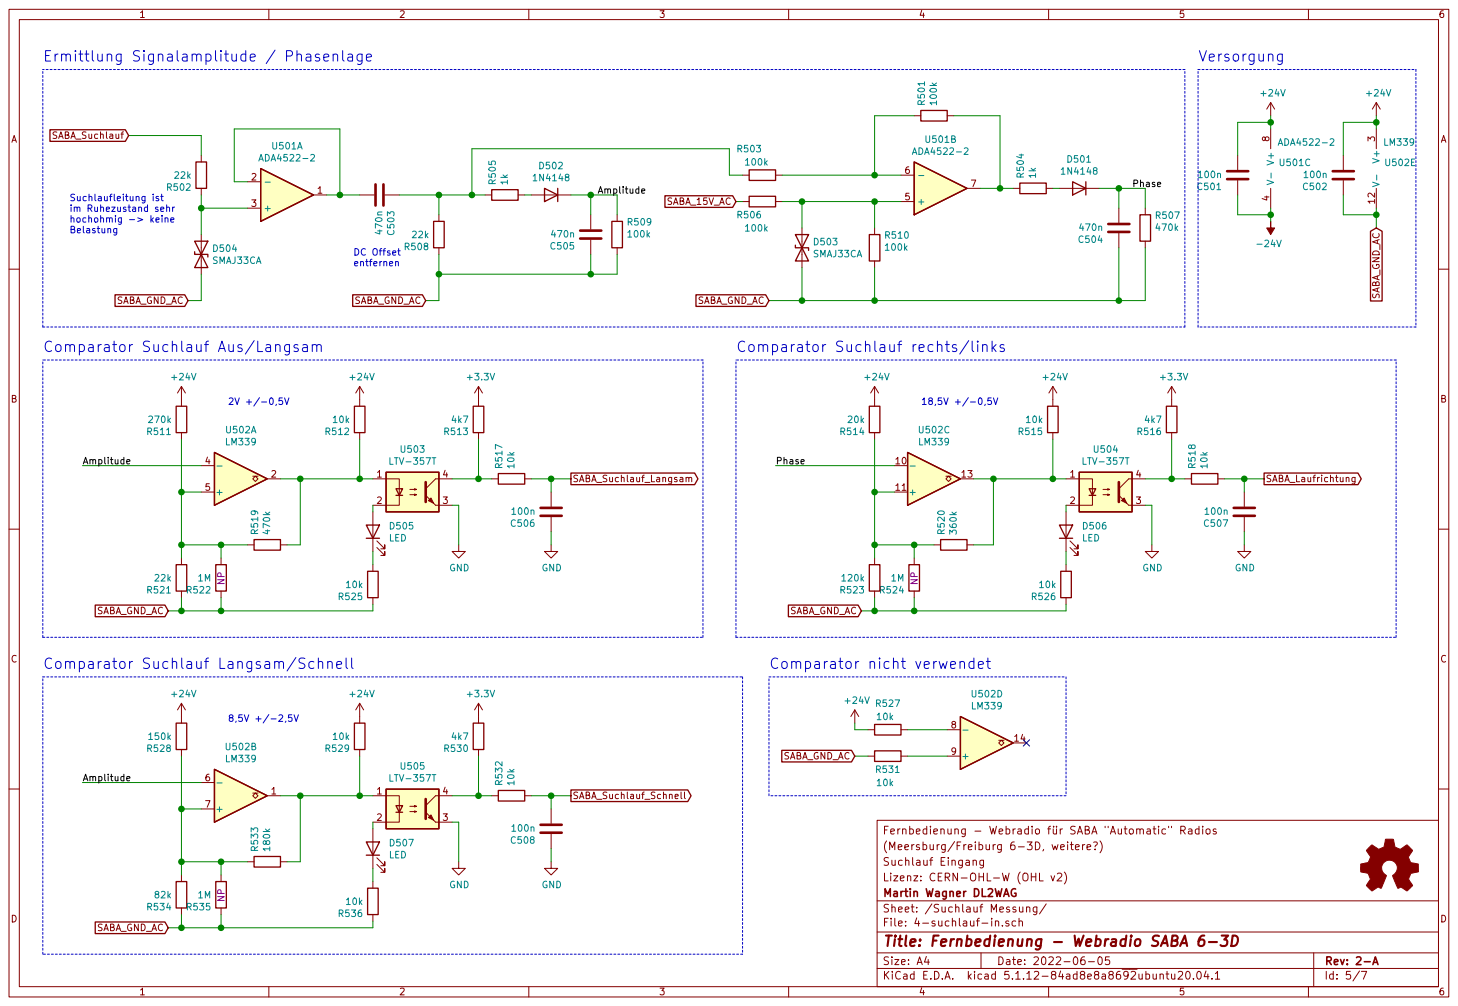
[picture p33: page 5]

Suchlaufleitung ist
im Ruhezustand sehr hochohmig -> keine

Comparator Suchlauf Aus/Langsam

Comparator Suchlauf rechts/links

2V +/-0,5V Comparator Suchlauf Langsam/Schnell

Fernbedienung - Webradio für SABA "Automatic" Radios R534

(Meersburg/Freiburg 6-3D, weitere?)
Suchlauf Eingang
Lizenz: CERN-OHL-W (OHL v2)
Martin Wagner DL2WAG
File: 4-suchlauf-in.sch Sheet: /Suchlauf Messung/
Id: 5/7 Title: Fernbedienung - Webradio SABA 6-3D

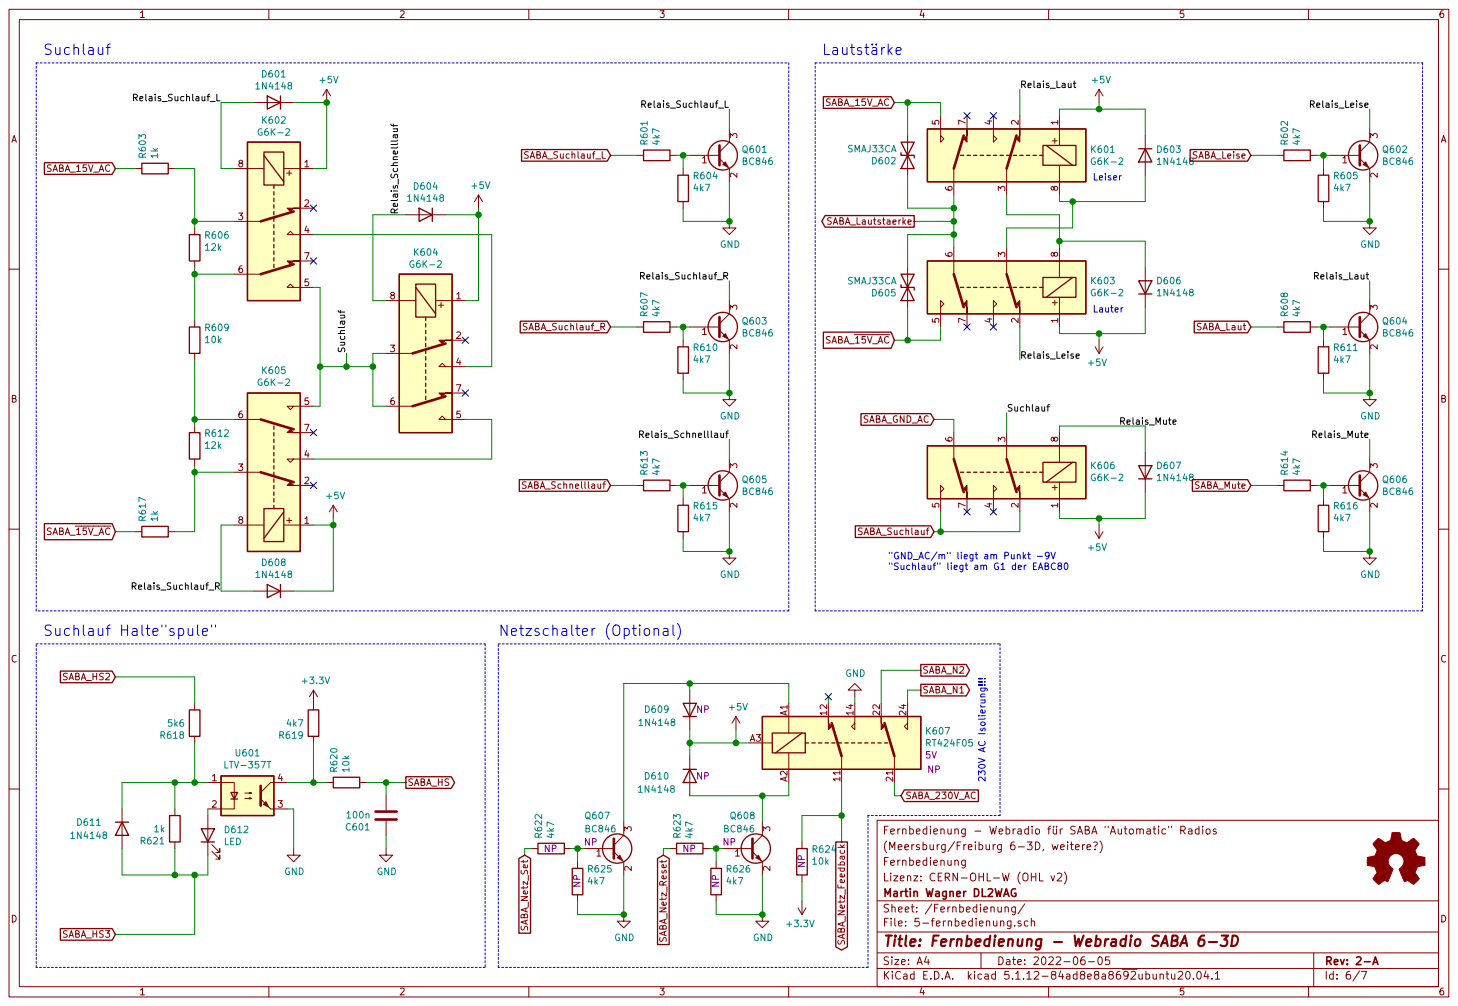
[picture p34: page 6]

"GND_AC/m" liegt am Punkt -9V
"Suchlauf" liegt am G1 der EABC80

(Meersburg/Freiburg 6-3D, weitere?)
Fernbedienung
Lizenz: CERN-OHL-W (OHL v2)
Martin Wagner DL2WAG
Sheet: /Fernbedienung/
File: 5-fernbedienung.sch
Id: 6/7 Title: Fernbedienung - Webradio SABA 6-3D

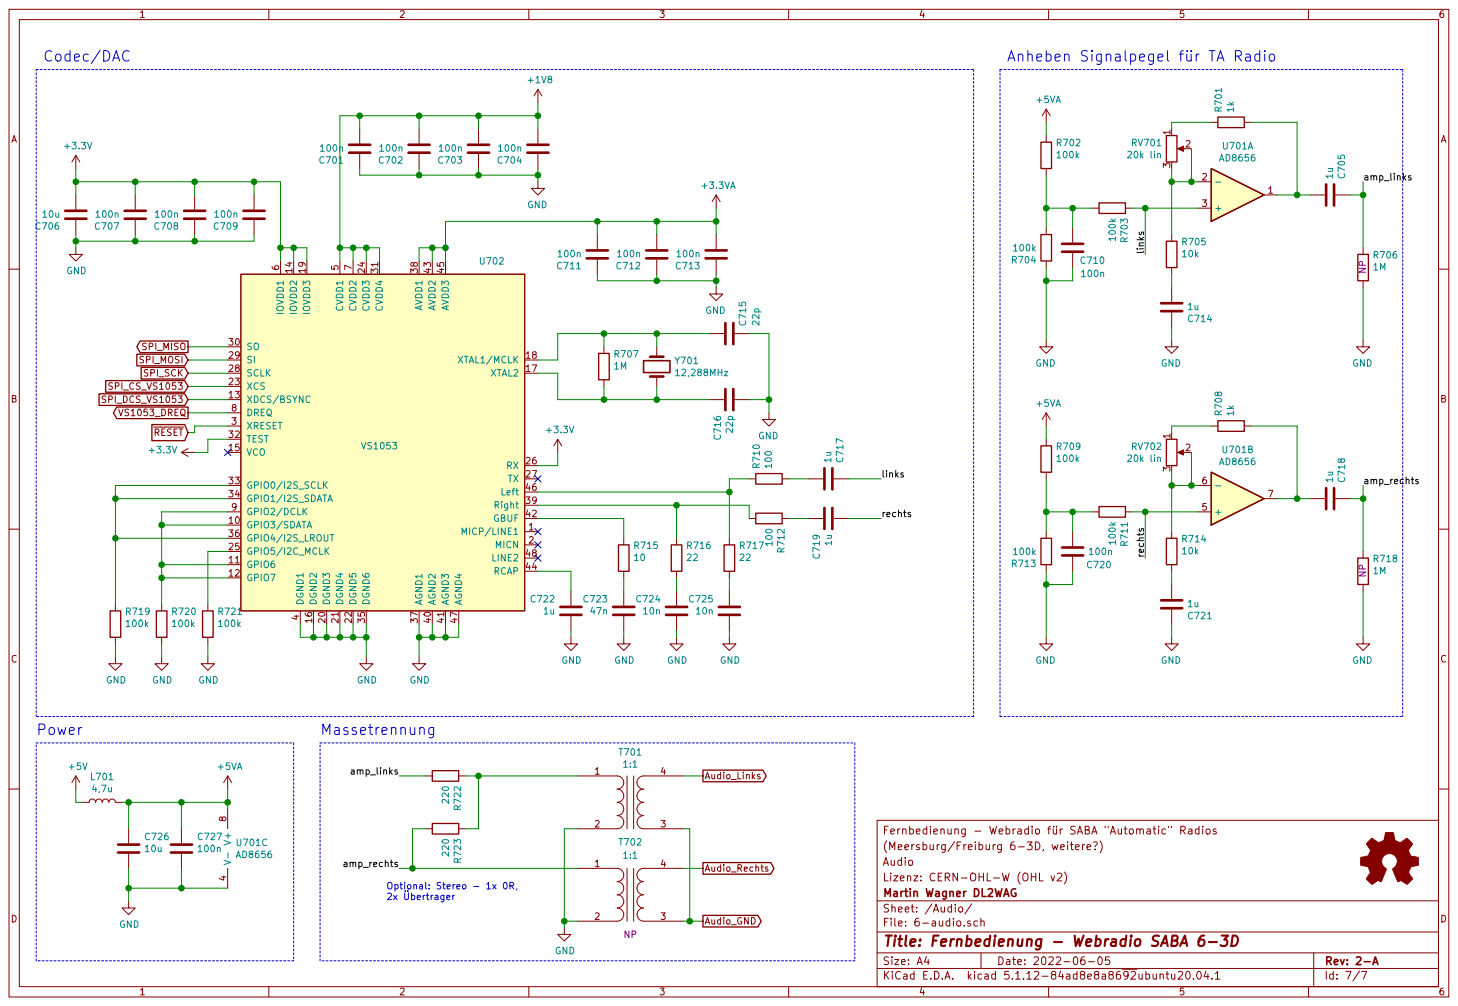
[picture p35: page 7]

Anheben Signalpegel für TA Radio

Fernbedienung - Webradio für SABA "Automatic" Radios
(Meersburg/Freiburg 6-3D, weitere?)
Lizenz: CERN-OHL-W (OHL v2) Audio

File: 6-audio.sch Sheet: /Audio/ Martin Wagner DL2WAG

Id: 7/7 Title: Fernbedienung - Webradio SABA 6-3D

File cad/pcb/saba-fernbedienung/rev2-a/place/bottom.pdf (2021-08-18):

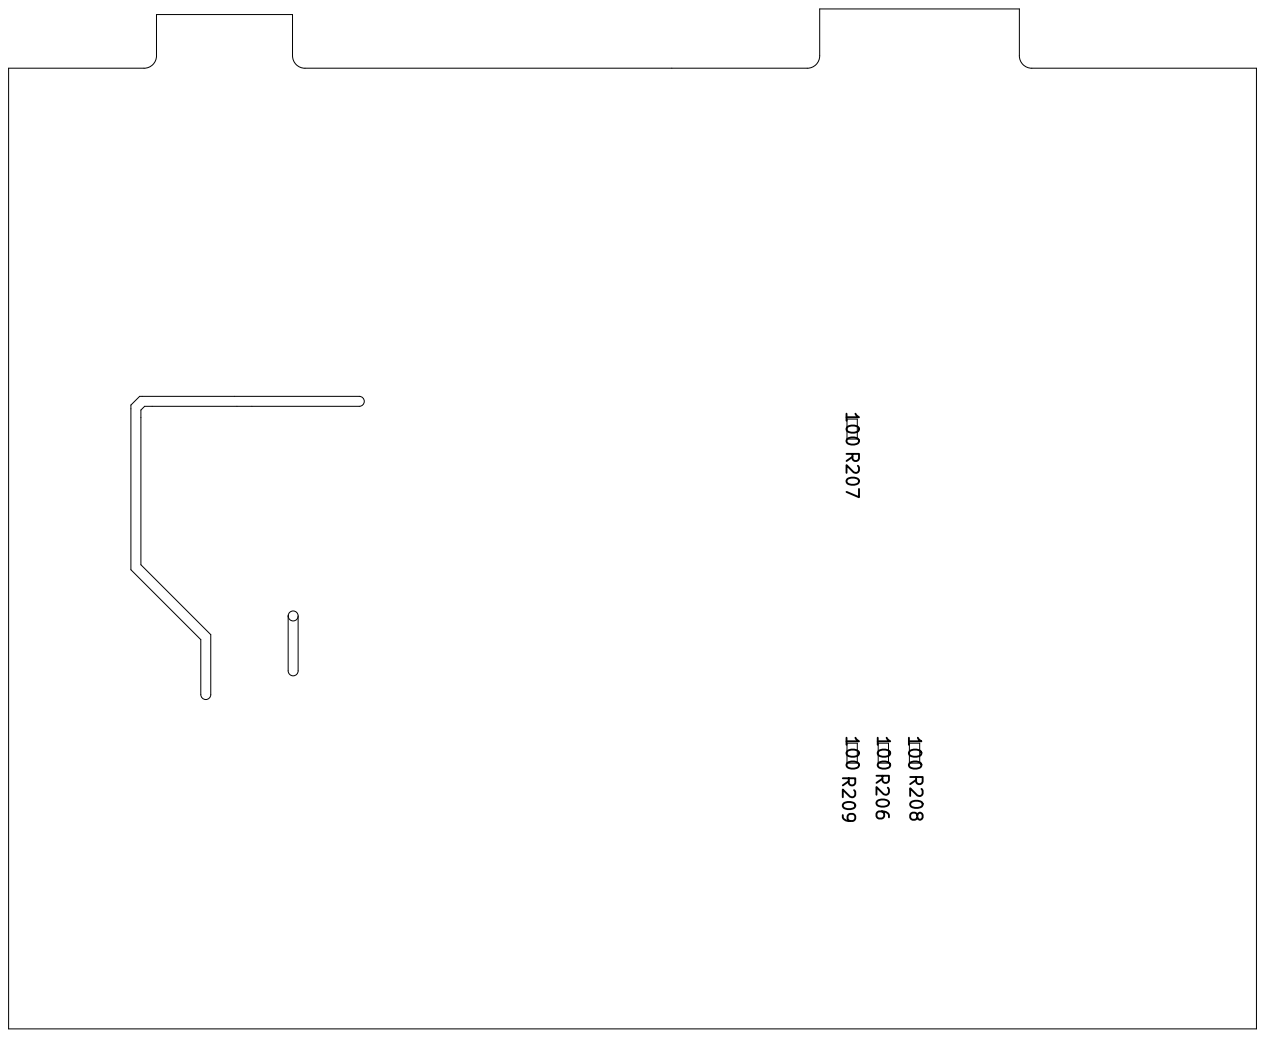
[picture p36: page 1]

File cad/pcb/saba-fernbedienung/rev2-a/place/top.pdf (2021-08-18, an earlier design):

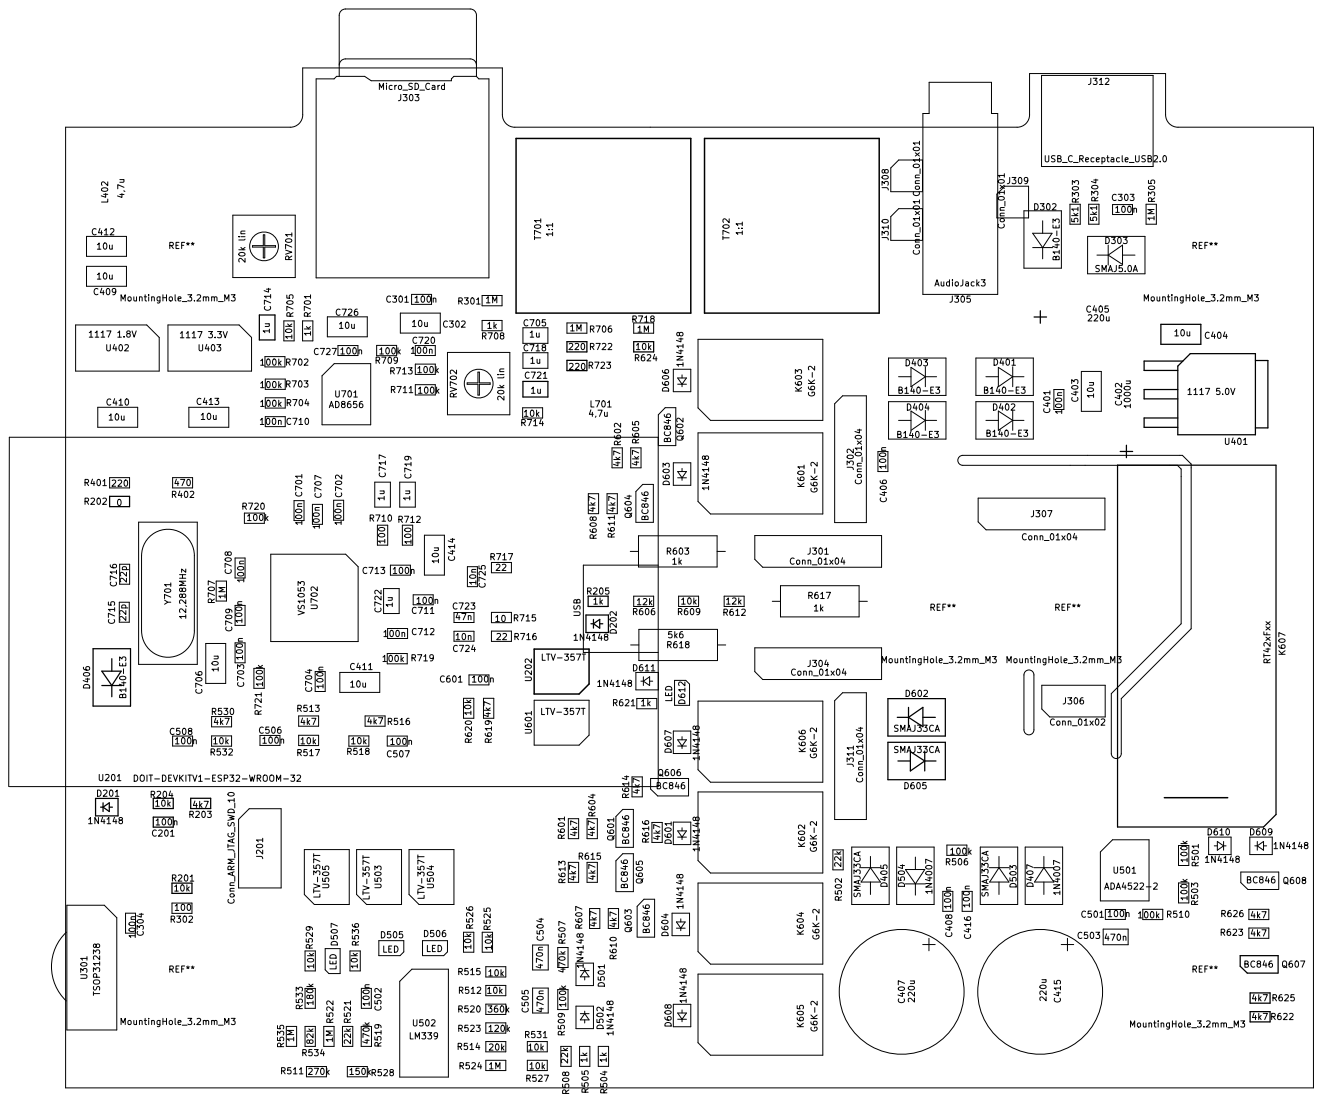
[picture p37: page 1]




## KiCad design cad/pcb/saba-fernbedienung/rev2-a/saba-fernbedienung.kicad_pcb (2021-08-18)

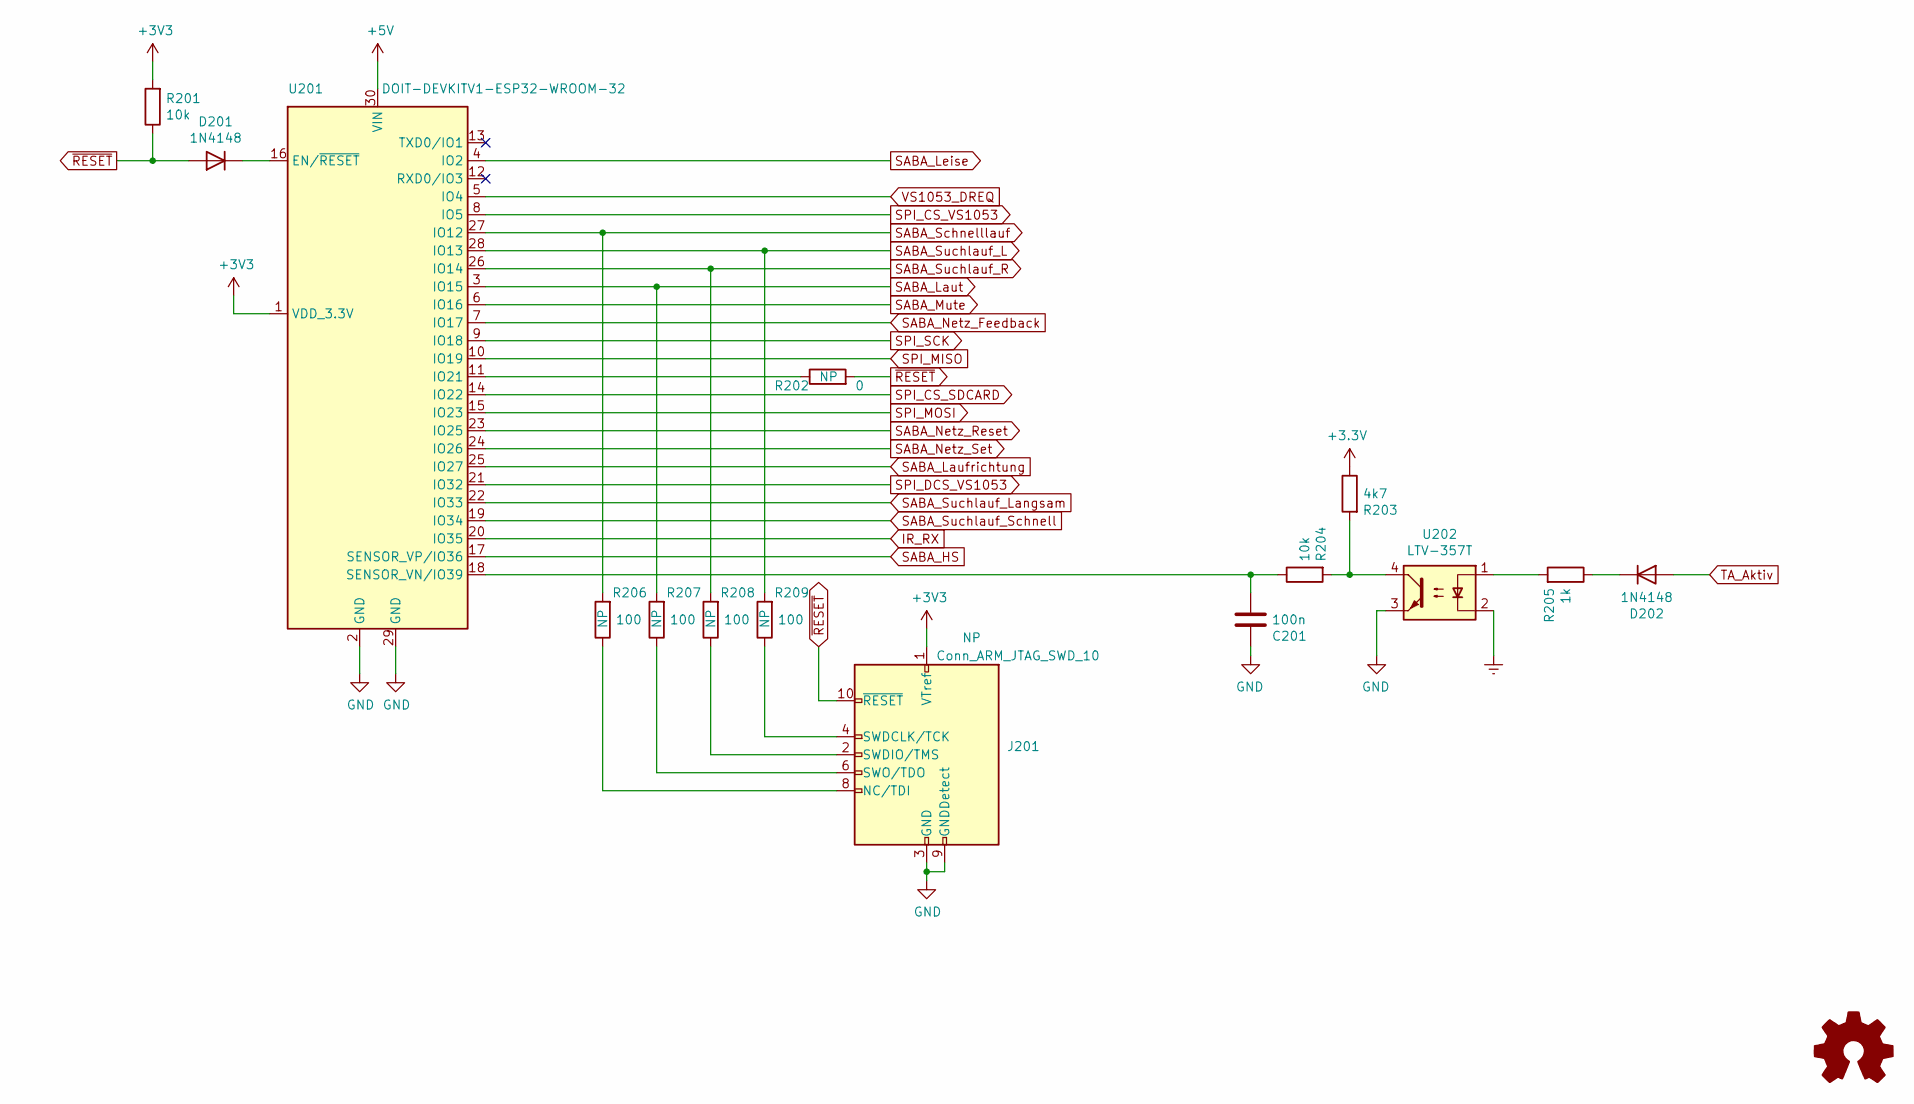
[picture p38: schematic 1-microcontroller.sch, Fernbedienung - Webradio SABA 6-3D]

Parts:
C201: 100n; C_0603_1608Metric
D201, D202: 1N4148; D_SOD-323F
J201: Conn_ARM_JTAG_SWD_10; PinHeader_2x05_P1.27mm_Vertical
R201, R204: 10k; R_0603_1608Metric
R202: 0; R_0603_1608Metric
R203: 4k7; R_0603_1608Metric
R205: 1k; R_0603_1608Metric
R206, R207, R208, R209: 100; R_0603_1608Metric
U201: DOIT-DEVKITV1-ESP32-WROOM-32
U202: LTV-357T; SO-4_4.4x3.6mm_P2.54mm

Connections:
+5V: U201.30 (VIN); also elsewhere on the board
Earth: U202.2; also elsewhere on the board
GND: C201.1, J201.3 (GND), J201.5 (GND), J201.9 (GNDDetect), U201.2 (GND), U201.29 (GND), U202.3; also elsewhere on the board
IR_RX: U201.20 (IO35); also elsewhere on the board
unnamed: C201.2, R204.1, U201.18 (SENSOR_VN/IO39)
unnamed: D201.1 (K), U201.16 (EN/~RESET)
unnamed: D202.1 (K), R205.1
unnamed: J201.2 (SWDIO/TMS), R208.1
unnamed: J201.4 (SWDCLK/TCK), R209.1
unnamed: J201.6 (SWO/TDO), R207.1
unnamed: J201.8 (NC/TDI), R206.1
unnamed: R202.1, U201.11 (IO21)
unnamed: R203.2, R204.2, U202.4
unnamed: R205.2, U202.1
SABA_HS: U201.17 (SENSOR_VP/IO36); also elsewhere on the board
SABA_Laufrichtung: U201.25 (IO27); also elsewhere on the board
SABA_Laut: R207.2, U201.3 (IO15); also elsewhere on the board
SABA_Leise: U201.4 (IO2); also elsewhere on the board
SABA_Mute: U201.6 (IO16); also elsewhere on the board
SABA_Netz_Feedback: U201.7 (IO17); also elsewhere on the board
SABA_Netz_Reset: U201.23 (IO25); also elsewhere on the board
SABA_Netz_Set: U201.24 (IO26); also elsewhere on the board
SABA_Schnelllauf: R206.2, U201.27 (IO12); also elsewhere on the board
SABA_Suchlauf_L: R209.2, U201.28 (IO13); also elsewhere on the board
SABA_Suchlauf_Langsam: U201.22 (IO33); also elsewhere on the board
SABA_Suchlauf_R: R208.2, U201.26 (IO14); also elsewhere on the board
SABA_Suchlauf_Schnell: U201.19 (IO34); also elsewhere on the board
SPI_CS_SDCARD: U201.14 (IO22); also elsewhere on the board
SPI_CS_VS1053: U201.8 (IO5); also elsewhere on the board
SPI_DCS_VS1053: U201.21 (IO32); also elsewhere on the board
SPI_MISO: U201.10 (IO19); also elsewhere on the board
SPI_MOSI: U201.15 (IO23); also elsewhere on the board
SPI_SCK: U201.9 (IO18); also elsewhere on the board
TA_Aktiv: D202.2 (A); also elsewhere on the board
VS1053_DREQ: U201.5 (IO4); also elsewhere on the board
~RESET: D201.2 (A), J201.10 (~RESET~), R201.1, R202.2; also elsewhere on the board

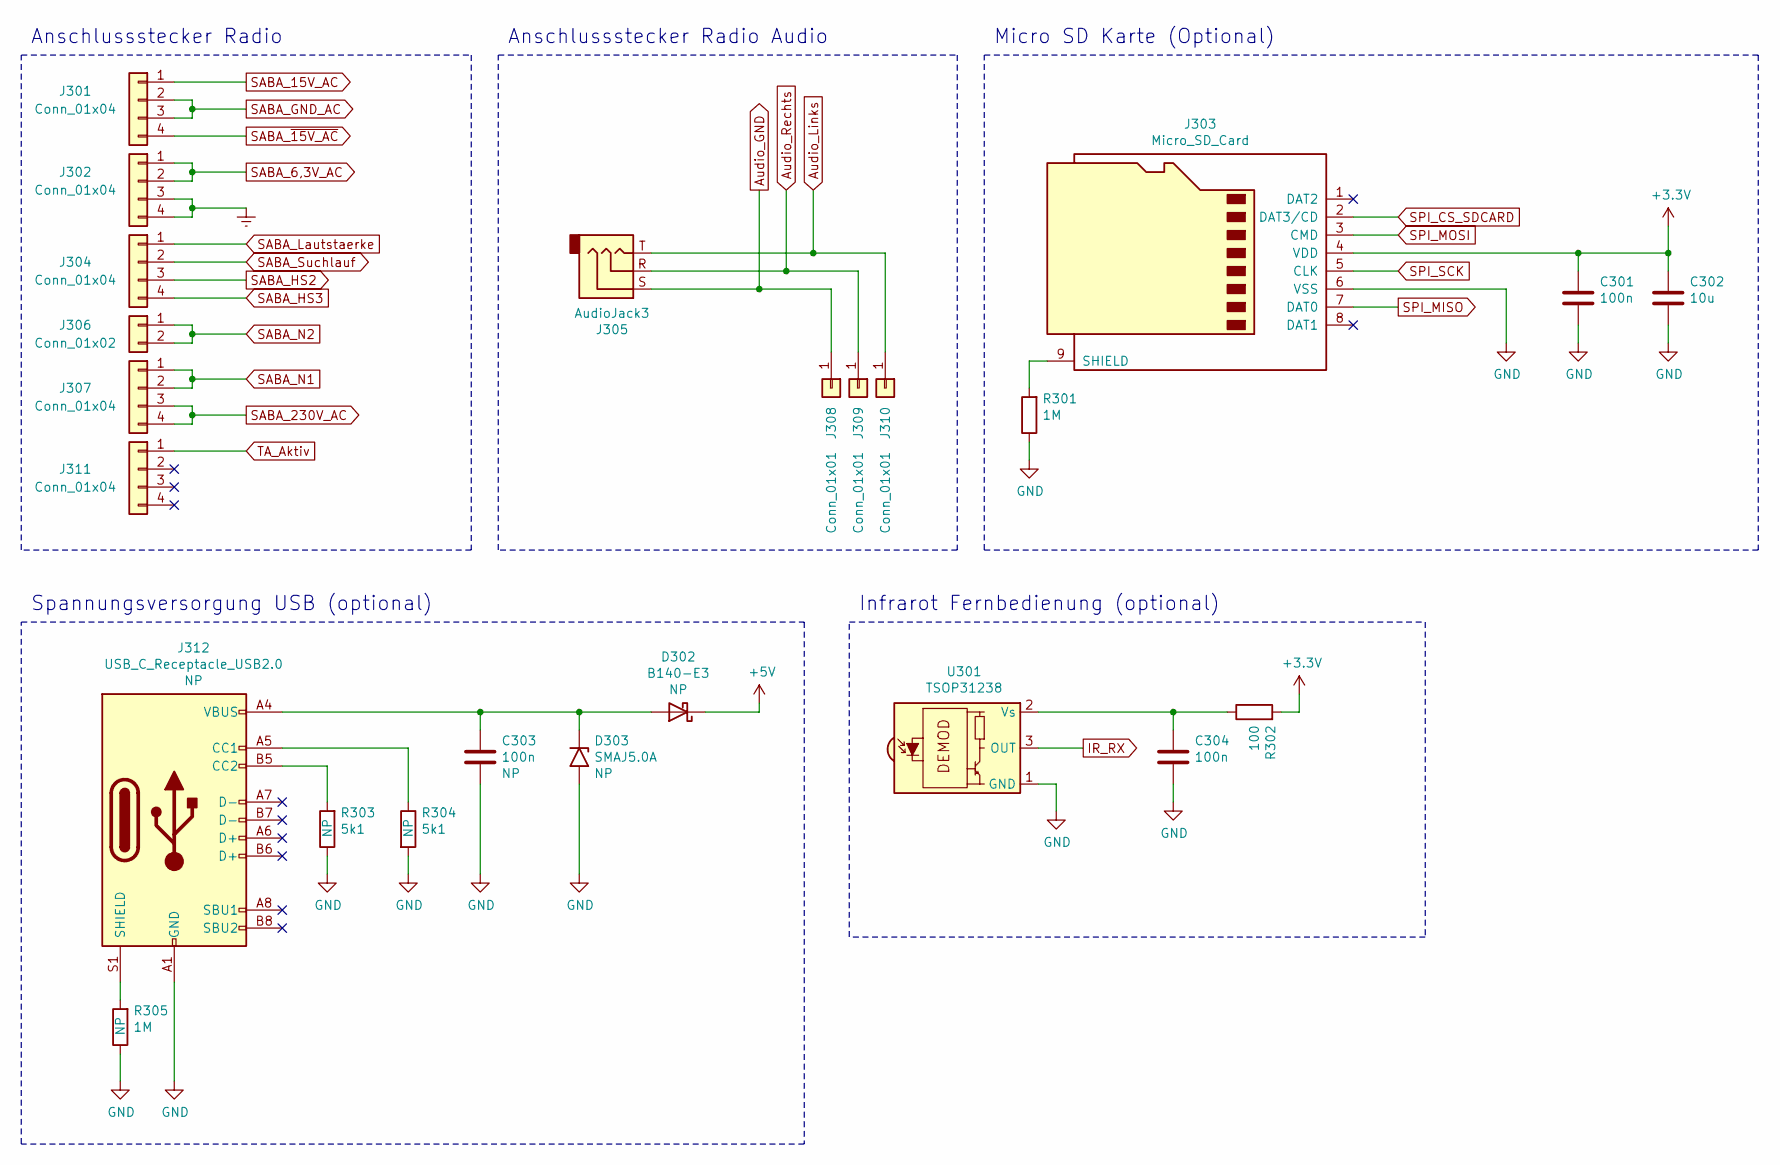
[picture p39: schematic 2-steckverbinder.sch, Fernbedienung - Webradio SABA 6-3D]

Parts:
C301, C303, C304: 100n; C_0603_1608Metric
C302: 10u; C_1206_3216Metric
D302: B140-E3; D_SMA
D303: SMAJ5.0A; D_SMA
J301, J302, J304, J307, J311: Conn_01x04; PinHeader_1x04_P2.54mm_Vertical
J303: Micro_SD_Card; microSD_HC_Hirose_DM3AT-SF-PEJM5
J305: AudioJack3; Jack_3.5mm_CUI_SJ-3523-SMT_Horizontal
J306: Conn_01x02; PinHeader_1x02_P2.54mm_Vertical
J308, J309, J310: Conn_01x01; PinHeader_1x01_P2.54mm_Vertical
J312: USB_C_Receptacle_USB2.0; USB_C_Receptacle_HRO_TYPE-C-31-M-12
R301, R305: 1M; R_0603_1608Metric
R302: 100; R_0603_1608Metric
R303, R304: 5k1; R_0603_1608Metric
U301: TSOP31238; Vishay_CAST-3Pin

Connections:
+5V: D302.1 (K); also elsewhere on the board
Audio_GND: J305.S, J308.1; also elsewhere on the board
Audio_Links: J305.T, J310.1; also elsewhere on the board
Audio_Rechts: J305.R, J309.1; also elsewhere on the board
Earth: J302.3, J302.4; also elsewhere on the board
GND: C301.2, C302.2, C303.2, C304.2, D303.2 (A2), J303.6 (VSS), J312.A1 (GND), J312.A12 (GND), J312.B1 (GND), J312.B12 (GND), R301.1, R303.1, R304.2, R305.1, U301.1 (GND); also elsewhere on the board
IR_RX: U301.3 (OUT); also elsewhere on the board
unnamed: C303.1, D302.2 (A), D303.1 (A1), J312.A4 (VBUS), J312.A9 (VBUS), J312.B4 (VBUS), J312.B9 (VBUS)
unnamed: C304.1, R302.1, U301.2 (Vs)
unnamed: J303.9 (SHIELD), R301.2
unnamed: J312.A5 (CC1), R304.1
unnamed: J312.B5 (CC2), R303.2
unnamed: J312.S1 (SHIELD), R305.2
SABA_6,3V_AC: J302.1, J302.2; also elsewhere on the board
SABA_15V_AC: J301.1; also elsewhere on the board
SABA_230V_AC: J307.3, J307.4; also elsewhere on the board
SABA_GND_AC: J301.2, J301.3; also elsewhere on the board
SABA_HS2: J304.3; also elsewhere on the board
SABA_HS3: J304.4; also elsewhere on the board
SABA_Lautstaerke: J304.1; also elsewhere on the board
SABA_N1: J307.1, J307.2; also elsewhere on the board
SABA_N2: J306.1, J306.2; also elsewhere on the board
SABA_Suchlauf: J304.2; also elsewhere on the board
SABA_~15V_AC: J301.4; also elsewhere on the board
SPI_CS_SDCARD: J303.2 (DAT3/CD); also elsewhere on the board
SPI_MISO: J303.7 (DAT0); also elsewhere on the board
SPI_MOSI: J303.3 (CMD); also elsewhere on the board
SPI_SCK: J303.5 (CLK); also elsewhere on the board
TA_Aktiv: J311.1; also elsewhere on the board

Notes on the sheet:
Anschlussstecker Radio
Spannungsversorgung USB (optional)
Micro SD Karte (Optional)
Infrarot Fernbedienung (optional)
Anschlussstecker Radio Audio

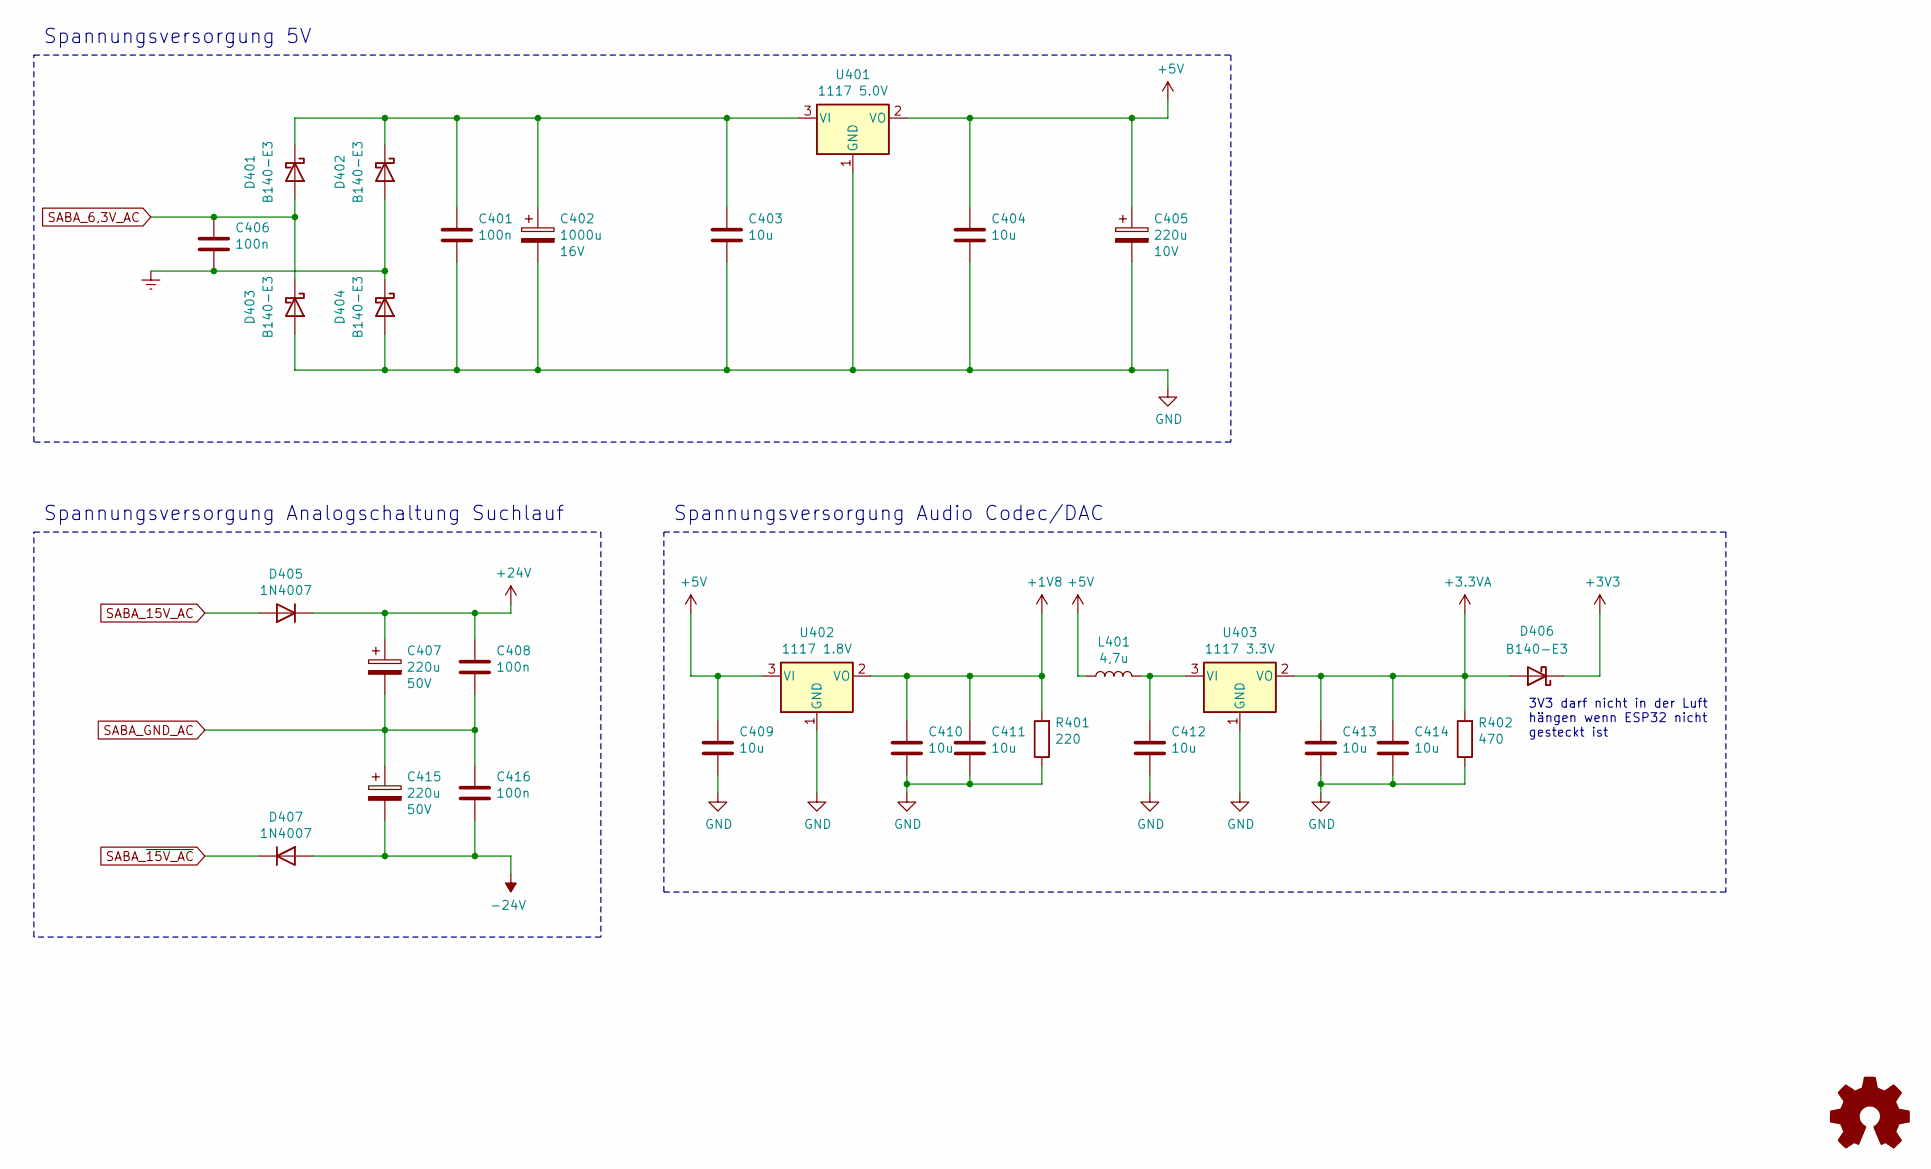
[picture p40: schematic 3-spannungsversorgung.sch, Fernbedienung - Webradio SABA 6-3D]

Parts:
C401, C406, C408, C416: 100n; C_0603_1608Metric
C402: 1000u; CP_Radial_D10.0mm_P5.00mm_L20.00mm_liegend; Voltage 16V
C403, C404, C409, C410, C411, C412, C413, C414: 10u; C_1206_3216Metric
C405: 220u; CP_Radial_D10.0mm_P5.00mm_L12.50mm_liegend; Voltage 10V
C407, C415: 220u; CP_Radial_D10.0mm_P5.00mm; Voltage 50V
D401, D402, D403, D404, D406: B140-E3; D_SMA
D405, D407: 1N4007; D_SMA
L401: 4,7u; WE-LQ
R401: 220; R_0603_1608Metric
R402: 470; R_0603_1608Metric
U401: 1117 5.0V; TO-252-3_TabPin2
U402: 1117 1.8V; SOT-223-3_TabPin2
U403: 1117 3.3V; SOT-223-3_TabPin2

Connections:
+1V8: C410.1, C411.1, R401.2, U402.2 (VO); also elsewhere on the board
+3.3VA: C413.1, C414.1, D406.2 (A), R402.2, U403.2 (VO); also elsewhere on the board
+5V: C404.1, C405.1, C409.1, L401.1, U401.2 (VO), U402.3 (VI); also elsewhere on the board
+24V: C407.1, C408.1, D405.1 (K); also elsewhere on the board
-24V: C415.2, C416.2, D407.2 (A); also elsewhere on the board
Earth: C406.2, D402.2 (A), D404.1 (K); also elsewhere on the board
GND: C401.2, C402.2, C403.2, C404.2, C405.2, C409.2, C410.2, C411.2, C412.2, C413.2, C414.2, D403.2 (A), D404.2 (A), R401.1, R402.1, U401.1 (GND), U402.1 (GND), U403.1 (GND); also elsewhere on the board
unnamed: C401.1, C402.1, C403.1, D401.1 (K), D402.1 (K), U401.3 (VI)
unnamed: C412.1, L401.2, U403.3 (VI)
SABA_6,3V_AC: C406.1, D401.2 (A), D403.1 (K); also elsewhere on the board
SABA_15V_AC: D405.2 (A); also elsewhere on the board
SABA_GND_AC: C407.2, C408.2, C415.1, C416.1; also elsewhere on the board
SABA_~15V_AC: D407.1 (K); also elsewhere on the board

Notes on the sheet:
Spannungsversorgung 5V
Spannungsversorgung Analogschaltung Suchlauf
Spannungsversorgung Audio Codec/DAC
3V3 darf nicht in der Luft hängen wenn ESP32 nicht gesteckt ist

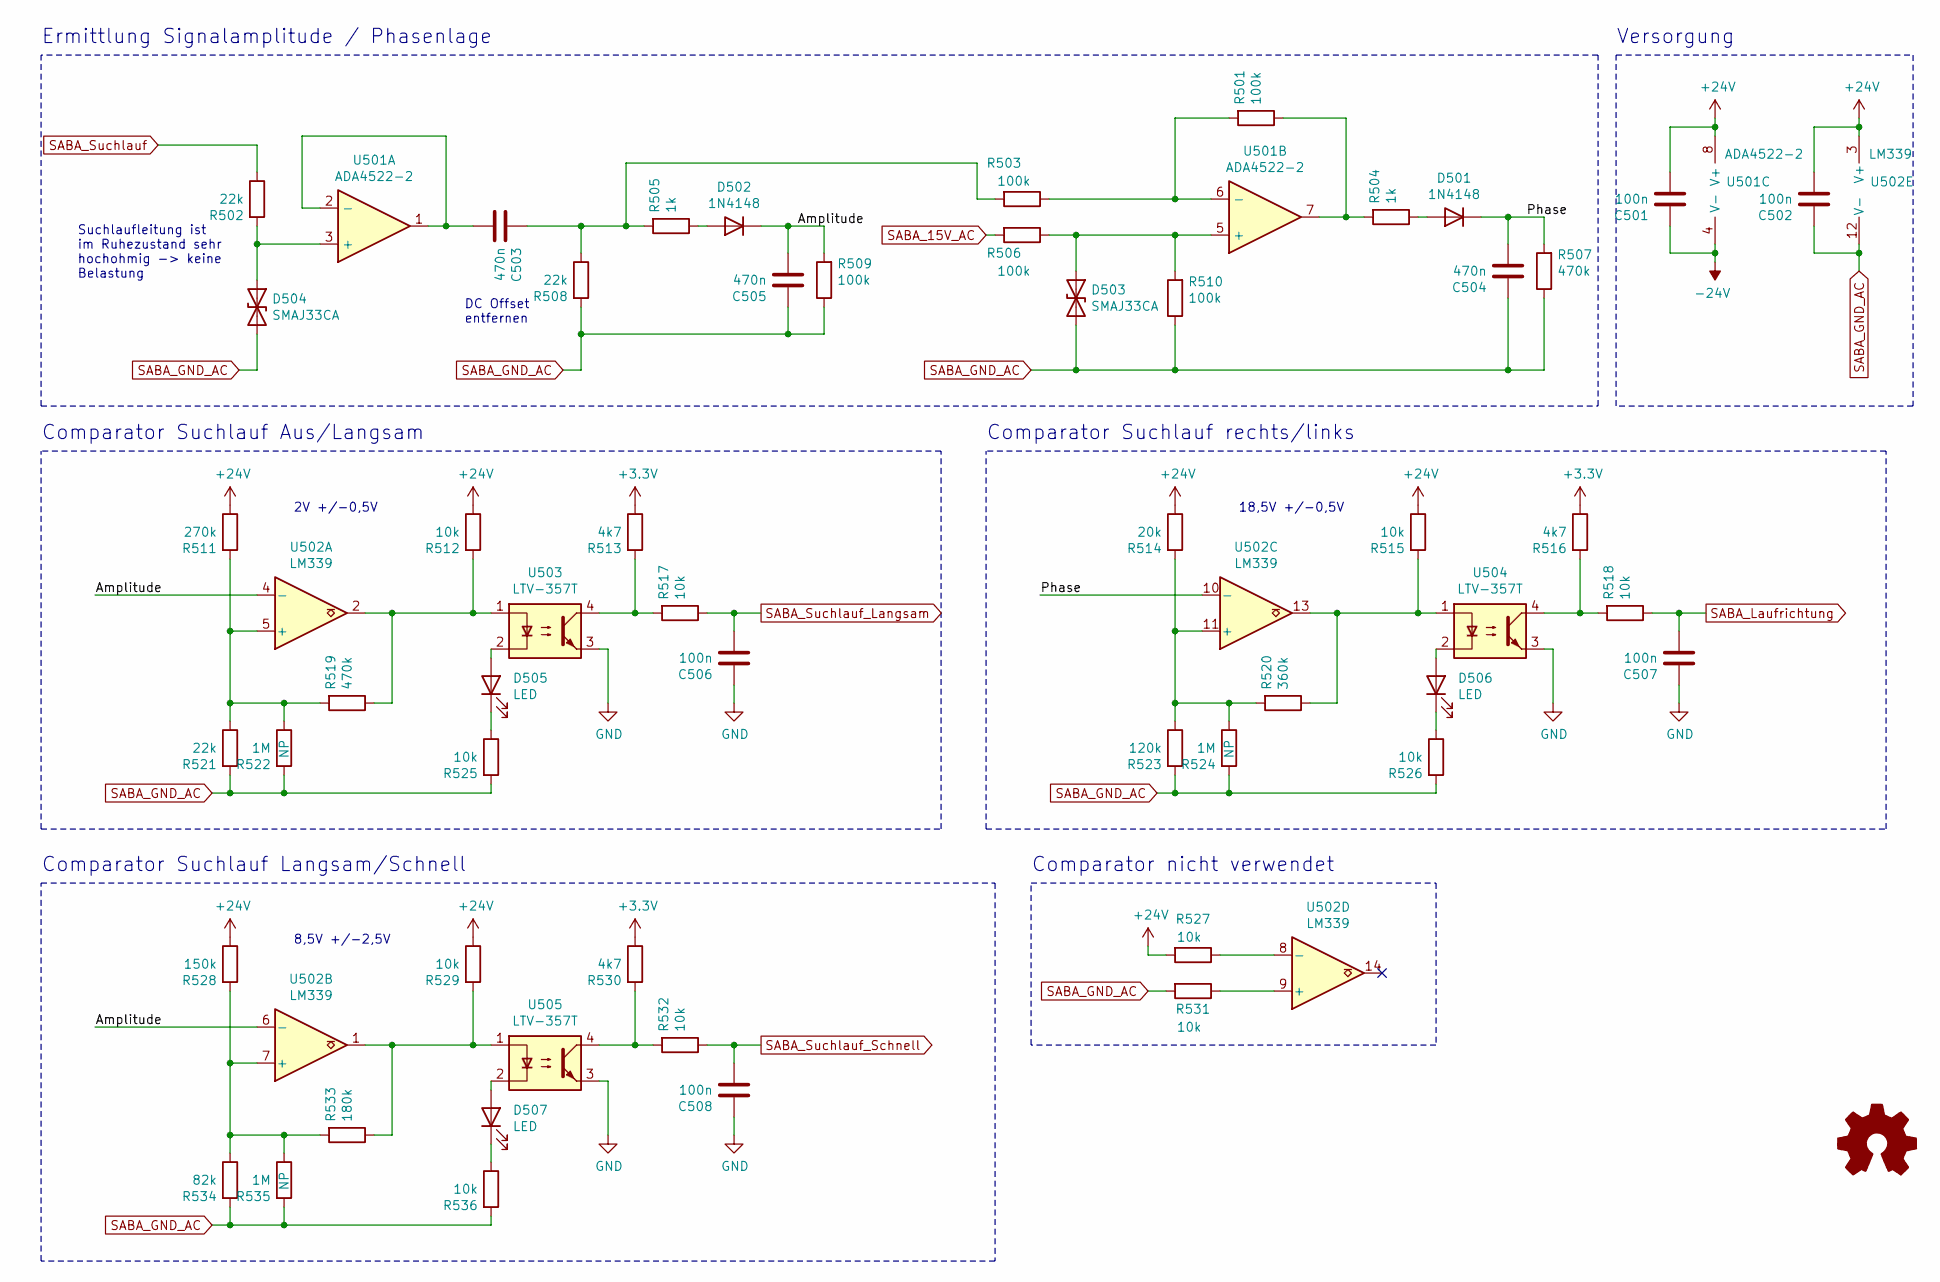
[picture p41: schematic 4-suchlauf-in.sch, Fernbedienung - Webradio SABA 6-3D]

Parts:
C501, C502, C506, C507, C508: 100n; C_0603_1608Metric
C503, C504, C505: 470n; C_0805_2012Metric
D501, D502: 1N4148; D_SOD-323F
D503, D504: SMAJ33CA; D_SMA
D505, D506, D507: LED; LED_0805_2012Metric
R501, R503, R506, R509, R510: 100k; R_0603_1608Metric
R502, R508, R521: 22k; R_0603_1608Metric
R504, R505: 1k; R_0603_1608Metric
R507, R519: 470k; R_0603_1608Metric
R511: 270k; R_0603_1608Metric
R512, R515, R517, R518, R525, R526, R527, R529, R531, R532, R536: 10k; R_0603_1608Metric
R513, R516, R530: 4k7; R_0603_1608Metric
R514: 20k; R_0603_1608Metric
R520: 360k; R_0603_1608Metric
R522, R524, R535: 1M; R_0603_1608Metric
R523: 120k; R_0603_1608Metric
R528: 150k; R_0603_1608Metric
R533: 180k; R_0603_1608Metric
R534: 82k; R_0603_1608Metric
U501: ADA4522-2; SOIC-8_3.9x4.9mm_P1.27mm
U502: LM339; SOIC-14_3.9x8.7mm_P1.27mm
U503, U504, U505: LTV-357T; SO-4_4.4x3.6mm_P2.54mm

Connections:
+24V: C501.2, C502.2, R511.1, R512.1, R514.1, R515.1, R527.2, R528.1, R529.1, U501.8 (V+), U502.3 (V+); also elsewhere on the board
-24V: C501.1, U501.4 (V-); also elsewhere on the board
/Suchlauf Messung/Amplitude: C505.2, D502.1 (K), R509.2, U502.4 (-), U502.6 (-)
/Suchlauf Messung/Phase: C504.2, D501.1 (K), R507.2, U502.10 (-)
GND: C506.1, C507.1, C508.1, U503.3, U504.3, U505.3; also elsewhere on the board
unnamed: C503.1, R503.2, R505.2, R508.1
unnamed: C503.2, U501.1, U501.2 (-)
unnamed: D501.2 (A), R504.1
unnamed: D502.2 (A), R505.1
unnamed: D503.1 (A1), R506.1, R510.2, U501.5 (+)
unnamed: D504.1 (A1), R502.2, U501.3 (+)
unnamed: D505.1 (K), R525.1
unnamed: D505.2 (A), U503.2
unnamed: D506.1 (K), R526.1
unnamed: D506.2 (A), U504.2
unnamed: D507.1 (K), R536.1
unnamed: D507.2 (A), U505.2
unnamed: R501.1, R504.2, U501.7
unnamed: R501.2, R503.1, U501.6 (-)
unnamed: R511.2, R519.2, R521.1, R522.1, U502.5 (+)
unnamed: R512.2, R519.1, U502.2, U503.1
unnamed: R513.2, R517.2, U503.4
unnamed: R514.2, R520.2, R523.1, R524.1, U502.11 (+)
unnamed: R515.2, R520.1, U502.13, U504.1
unnamed: R516.2, R518.2, U504.4
unnamed: R527.1, U502.8 (-)
unnamed: R528.2, R533.2, R534.1, R535.1, U502.7 (+)
unnamed: R529.2, R533.1, U502.1, U505.1
unnamed: R530.2, R532.2, U505.4
unnamed: R531.1, U502.9 (+)
SABA_15V_AC: R506.2; also elsewhere on the board
SABA_GND_AC: C502.1, C504.1, C505.1, D503.2 (A2), D504.2 (A2), R507.1, R508.2, R509.1, R510.1, R521.2, R522.2, R523.2, R524.2, R525.2, R526.2, R531.2, R534.2, R535.2, R536.2, U502.12 (V-); also elsewhere on the board
SABA_Laufrichtung: C507.2, R518.1; also elsewhere on the board
SABA_Suchlauf: R502.1; also elsewhere on the board
SABA_Suchlauf_Langsam: C506.2, R517.1; also elsewhere on the board
SABA_Suchlauf_Schnell: C508.2, R532.1; also elsewhere on the board

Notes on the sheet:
Ermittlung Signalamplitude / Phasenlage
Suchlaufleitung ist im Ruhezustand sehr hochohmig -> keine Belastung
DC Offset entfernen
2V +/-0,5V
Comparator Suchlauf Aus/Langsam
Comparator Suchlauf Langsam/Schnell
8,5V +/-2,5V
18,5V +/-0,5V
Comparator Suchlauf rechts/links
Comparator nicht verwendet
Versorgung

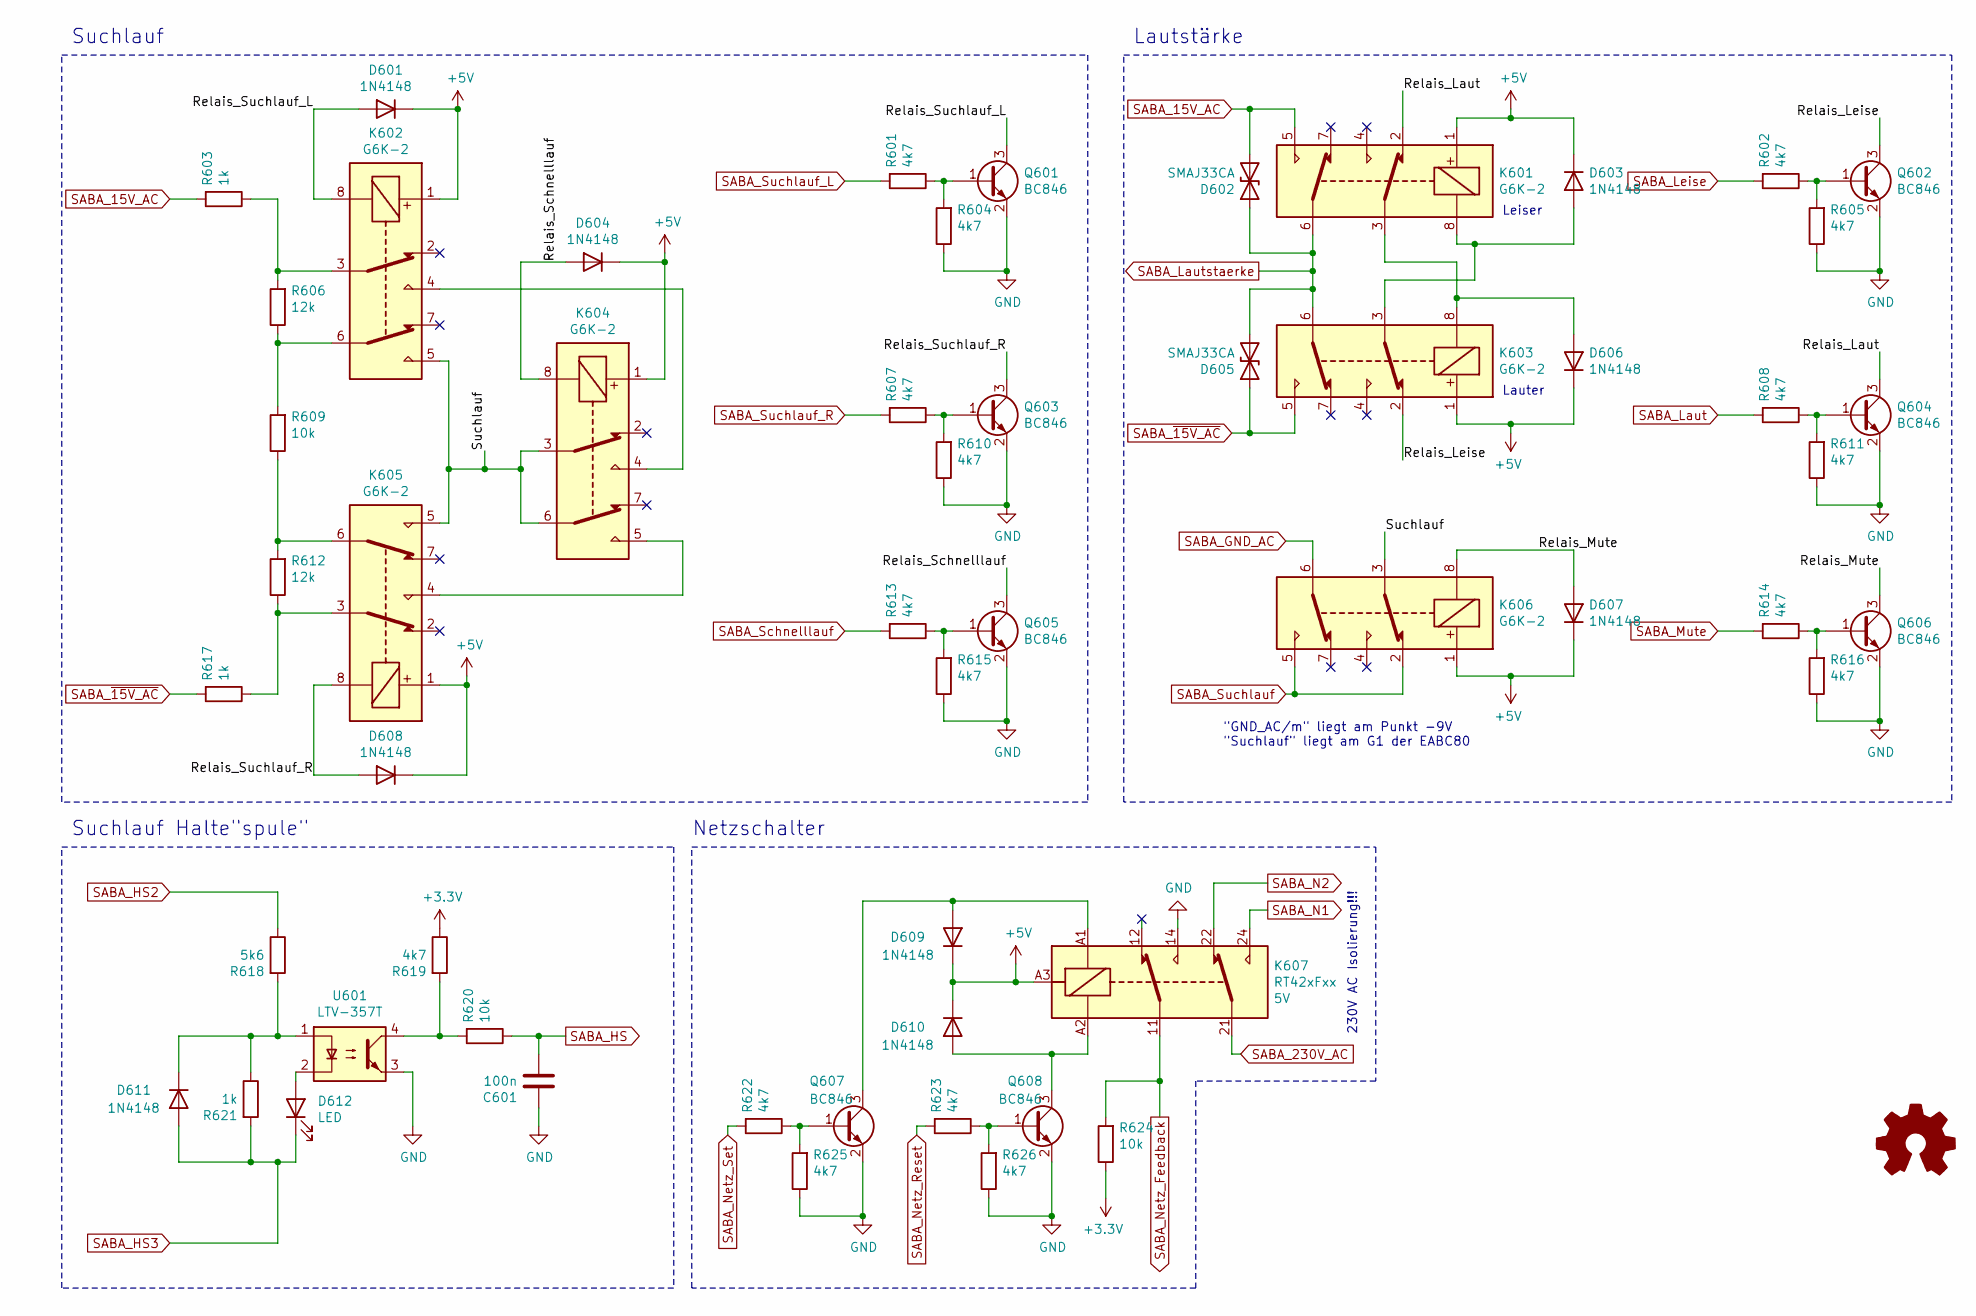
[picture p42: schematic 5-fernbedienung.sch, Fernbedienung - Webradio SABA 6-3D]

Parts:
C601: 100n; C_0603_1608Metric
D601, D603, D604, D606, D607, D608, D609, D610, D611: 1N4148; D_SOD-323F
D602, D605: SMAJ33CA; D_SMA
D612: LED; LED_0805_2012Metric
K601, K602, K603, K604, K605, K606: G6K-2; Relay_DPDT_Omron_G6K-2P
K607: RT42xFxx; Relay_DPDT_Schrack-RT2-FormC-Dual-Coil_RM5mm; Coil Voltage 5V
Q601, Q602, Q603, Q604, Q605, Q606, Q607, Q608: BC846; SOT-23
R601, R602, R604, R605, R607, R608, R610, R611, R613, R614, R615, R616, R619, R622, R623, R625, R626: 4k7; R_0603_1608Metric
R603, R617: 1k; R_Axial_DIN0207_L6.3mm_D2.5mm_P7.62mm_Horizontal
R606, R612: 12k; R_0603_1608Metric
R609, R620, R624: 10k; R_0603_1608Metric
R618: 5k6; R_Axial_DIN0207_L6.3mm_D2.5mm_P7.62mm_Horizontal
R621: 1k; R_0603_1608Metric
U601: LTV-357T; SO-4_4.4x3.6mm_P2.54mm

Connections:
+5V: D601.1 (K), D603.1 (K), D604.1 (K), D606.1 (K), D607.1 (K), D608.1 (K), D609.1 (K), D610.1 (K), K601.1, K602.1, K603.1, K604.1, K605.1, K606.1, K607.A3; also elsewhere on the board
/Fernbedienung/Relais_Laut: K601.2, Q604.3 (C)
/Fernbedienung/Relais_Leise: K603.2, Q602.3 (C)
/Fernbedienung/Relais_Mute: D607.2 (A), K606.8, Q606.3 (C)
/Fernbedienung/Relais_Schnelllauf: D604.2 (A), K604.8, Q605.3 (C)
/Fernbedienung/Relais_Suchlauf_L: D601.2 (A), K602.8, Q601.3 (C)
/Fernbedienung/Relais_Suchlauf_R: D608.2 (A), K605.8, Q603.3 (C)
/Fernbedienung/Suchlauf: K602.5, K604.3, K604.6, K605.5, K606.3
GND: C601.1, K607.14, Q601.2 (E), Q602.2 (E), Q603.2 (E), Q604.2 (E), Q605.2 (E), Q606.2 (E), Q607.2 (E), Q608.2 (E), R604.1, R605.1, R610.1, R611.1, R615.1, R616.1, R625.1, R626.1, U601.3; also elsewhere on the board
unnamed: D603.2 (A), K601.8, K603.3
unnamed: D606.2 (A), K601.3, K603.8
unnamed: D609.2 (A), K607.A1, Q607.3 (C)
unnamed: D610.2 (A), K607.A2, Q608.3 (C)
unnamed: D611.1 (K), R618.2, R621.1, U601.1
unnamed: D612.2 (A), U601.2
unnamed: K602.3, R603.1, R606.2
unnamed: K602.4, K604.4
unnamed: K602.6, R606.1, R609.2
unnamed: K604.5, K605.4
unnamed: K605.3, R612.1, R617.1
unnamed: K605.6, R609.1, R612.2
unnamed: Q601.1 (B), R601.1, R604.2
unnamed: Q602.1 (B), R602.1, R605.2
unnamed: Q603.1 (B), R607.1, R610.2
unnamed: Q604.1 (B), R608.1, R611.2
unnamed: Q605.1 (B), R613.1, R615.2
unnamed: Q606.1 (B), R614.1, R616.2
unnamed: Q607.1 (B), R622.1, R625.2
unnamed: Q608.1 (B), R623.1, R626.2
unnamed: R619.2, R620.2, U601.4
SABA_15V_AC: D602.2 (A2), K601.5, R603.2; also elsewhere on the board
SABA_230V_AC: K607.21; also elsewhere on the board
SABA_GND_AC: K606.6; also elsewhere on the board
SABA_HS: C601.2, R620.1; also elsewhere on the board
SABA_HS2: R618.1; also elsewhere on the board
SABA_HS3: D611.2 (A), D612.1 (K), R621.2; also elsewhere on the board
SABA_Laut: R608.2; also elsewhere on the board
SABA_Lautstaerke: D602.1 (A1), D605.2 (A2), K601.6, K603.6; also elsewhere on the board
SABA_Leise: R602.2; also elsewhere on the board
SABA_Mute: R614.2; also elsewhere on the board
SABA_N1: K607.24; also elsewhere on the board
SABA_N2: K607.22; also elsewhere on the board
SABA_Netz_Feedback: K607.11, R624.2; also elsewhere on the board
SABA_Netz_Reset: R623.2; also elsewhere on the board
SABA_Netz_Set: R622.2; also elsewhere on the board
SABA_Schnelllauf: R613.2; also elsewhere on the board
SABA_Suchlauf: K606.2, K606.5; also elsewhere on the board
SABA_Suchlauf_L: R601.2; also elsewhere on the board
SABA_Suchlauf_R: R607.2; also elsewhere on the board
SABA_~15V_AC: D605.1 (A1), K603.5, R617.2; also elsewhere on the board

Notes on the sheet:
Suchlauf
Suchlauf Halte"spule"
"GND_AC/m" liegt am Punkt -9V "Suchlauf" liegt am G1 der EABC80
Lautstärke
Lauter
Leiser
230V AC Isolierung!!!
Netzschalter

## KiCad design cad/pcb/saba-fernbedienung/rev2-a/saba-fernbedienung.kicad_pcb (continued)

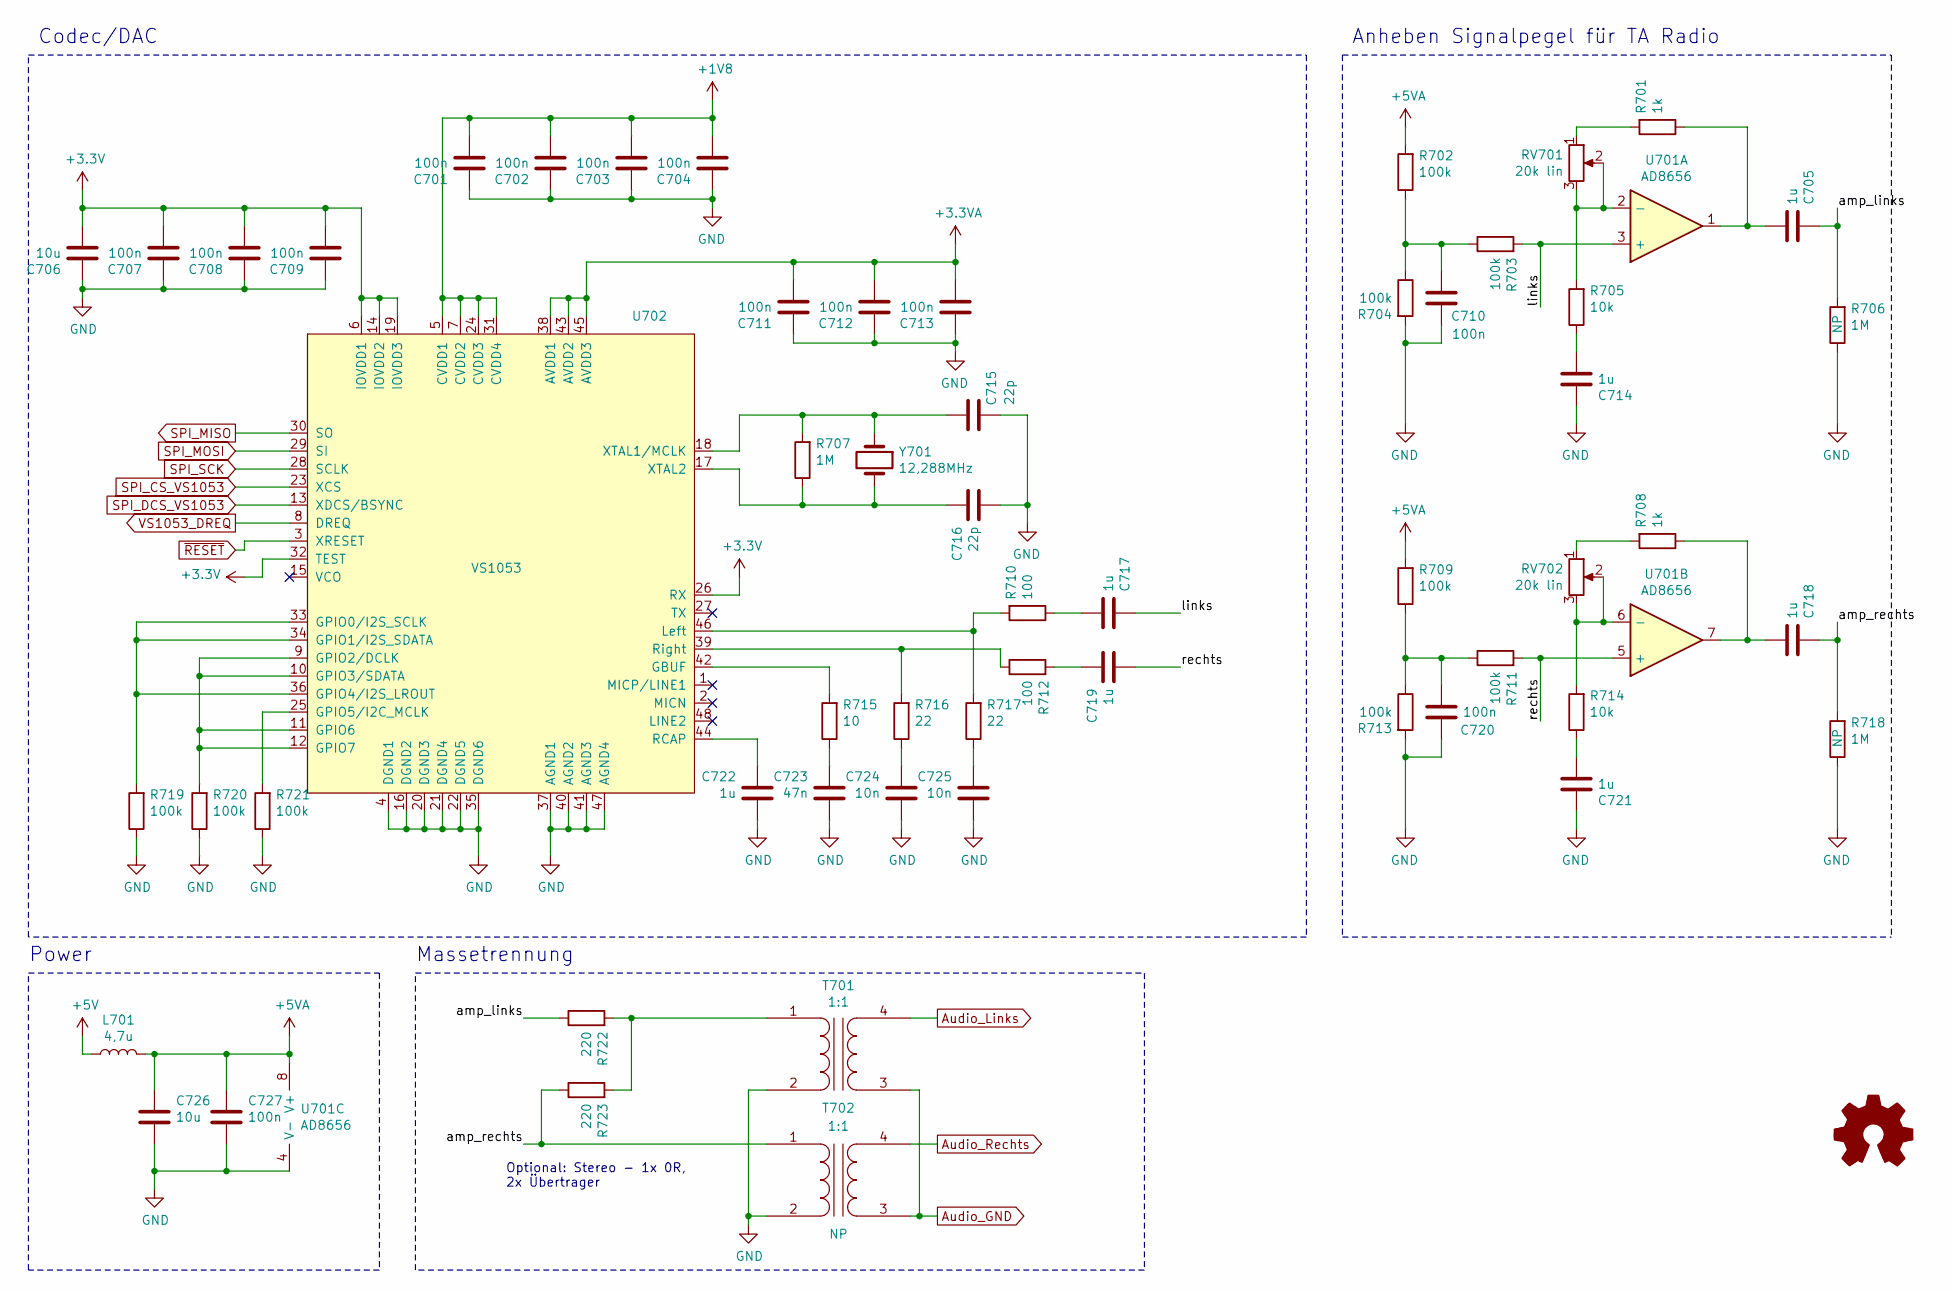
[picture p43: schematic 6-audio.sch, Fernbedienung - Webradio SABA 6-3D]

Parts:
C701, C702, C703, C704, C707, C708, C709, C710, C711, C712, C713, C720, C727: 100n; C_0603_1608Metric
C705, C714, C717, C718, C719, C721, C722: 1u; C_0805_2012Metric
C706, C726: 10u; C_1206_3216Metric
C715, C716: 22p; C_0603_1608Metric
C723: 47n; C_0603_1608Metric
C724, C725: 10n; C_0603_1608Metric
L701: 4,7u; WE-LQ
R701, R708: 1k; R_0603_1608Metric
R702, R703, R704, R709, R711, R713, R719, R720, R721: 100k; R_0603_1608Metric
R705, R714: 10k; R_0603_1608Metric
R706, R707, R718: 1M; R_0603_1608Metric
R710, R712: 100; R_0603_1608Metric
R715: 10; R_0603_1608Metric
R716, R717: 22; R_0603_1608Metric
R722, R723: 220; R_0603_1608Metric
RV701, RV702: 20k lin; Potentiometer_Vishay_TS53YL_Vertical
T701, T702: 1:1; Transformer_NF_EI14
U701: AD8656; SOIC-8_3.9x4.9mm_P1.27mm
U702: VS1053; LQFP-48_7x7mm_P0.5mm
Y701: 12,288MHz; Crystal_SMD_HC49-SD

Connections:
+1V8: C701.2, C702.2, C703.2, C704.2, U702.5 (CVDD1), U702.7 (CVDD2), U702.24 (CVDD3), U702.31 (CVDD4); also elsewhere on the board
+3.3VA: C711.2, C712.2, C713.2, U702.38 (AVDD1), U702.43 (AVDD2), U702.45 (AVDD3); also elsewhere on the board
+5V: L701.1; also elsewhere on the board
+5VA: C726.1, C727.1, L701.2, R702.2, R709.2, U701.8 (V+)
/Audio/amp_links: C705.1, R706.2, R722.1
/Audio/amp_rechts: C718.1, R718.2, R723.1, T702.1 (AA)
/Audio/links: C717.1, R703.2, U701.3 (+)
/Audio/rechts: C719.2, R711.2, U701.5 (+)
Audio_GND: T701.3 (SA), T702.3 (SA); also elsewhere on the board
Audio_Links: T701.4 (SB); also elsewhere on the board
Audio_Rechts: T702.4 (SB); also elsewhere on the board
GND: C701.1, C702.1, C703.1, C704.1, C706.1, C707.1, C708.1, C709.1, C710.1, C711.1, C712.1, C713.1, C714.1, C715.2, C716.2, C720.2, C721.1, C722.2, C723.2, C724.2, C725.2, C726.2, C727.2, R704.2, R706.1, R713.2, R718.1, R719.1, R720.1, R721.1, T701.2 (AB), T702.2 (AB), U701.4 (V-), U702.4 (DGND1), U702.16 (DGND2), U702.20 (DGND3), U702.21 (DGND4), U702.22 (DGND5), U702.35 (DGND6), U702.37 (AGND1), U702.40 (AGND2), U702.41 (AGND3), U702.47 (AGND4); also elsewhere on the board
unnamed: C705.2, R701.1, U701.1
unnamed: C710.2, R702.1, R703.1, R704.1
unnamed: C714.2, R705.1
unnamed: C715.1, R707.2, U702.18 (XTAL1/MCLK), Y701.1
unnamed: C716.1, R707.1, U702.17 (XTAL2), Y701.2
unnamed: C717.2, R710.1
unnamed: C718.2, R708.1, U701.7
unnamed: C719.1, R712.2
unnamed: C720.1, R709.1, R711.1, R713.1
unnamed: C721.2, R714.1
unnamed: C722.1, U702.44 (RCAP)
unnamed: C723.1, R715.1
unnamed: C724.1, R716.1
unnamed: C725.1, R717.1
unnamed: R701.2, RV701.1
unnamed: R705.2, RV701.2, RV701.3, U701.2 (-)
unnamed: R708.2, RV702.1
unnamed: R710.2, R717.2, U702.46 (Left)
unnamed: R712.1, R716.2, U702.39 (Right)
unnamed: R714.2, RV702.2, RV702.3, U701.6 (-)
unnamed: R715.2, U702.42 (GBUF)
unnamed: R719.2, U702.33 (GPIO0/I2S_SCLK), U702.34 (GPIO1/I2S_SDATA), U702.36 (GPIO4/I2S_LROUT)
unnamed: R720.2, U702.9 (GPIO2/DCLK), U702.10 (GPIO3/SDATA), U702.11 (GPIO6), U702.12 (GPIO7)
unnamed: R721.2, U702.25 (GPIO5/I2C_MCLK)
unnamed: R722.2, R723.2, T701.1 (AA)
SPI_CS_VS1053: U702.23 (XCS); also elsewhere on the board
SPI_DCS_VS1053: U702.13 (XDCS/BSYNC); also elsewhere on the board
SPI_MISO: U702.30 (SO); also elsewhere on the board
SPI_MOSI: U702.29 (SI); also elsewhere on the board
SPI_SCK: U702.28 (SCLK); also elsewhere on the board
VS1053_DREQ: U702.8 (DREQ); also elsewhere on the board
~RESET: U702.3 (XRESET); also elsewhere on the board

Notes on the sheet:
Codec/DAC
Anheben Signalpegel für TA Radio
Power
Massetrennung
Optional: Stereo - 1x 0R, 2x Übertrager

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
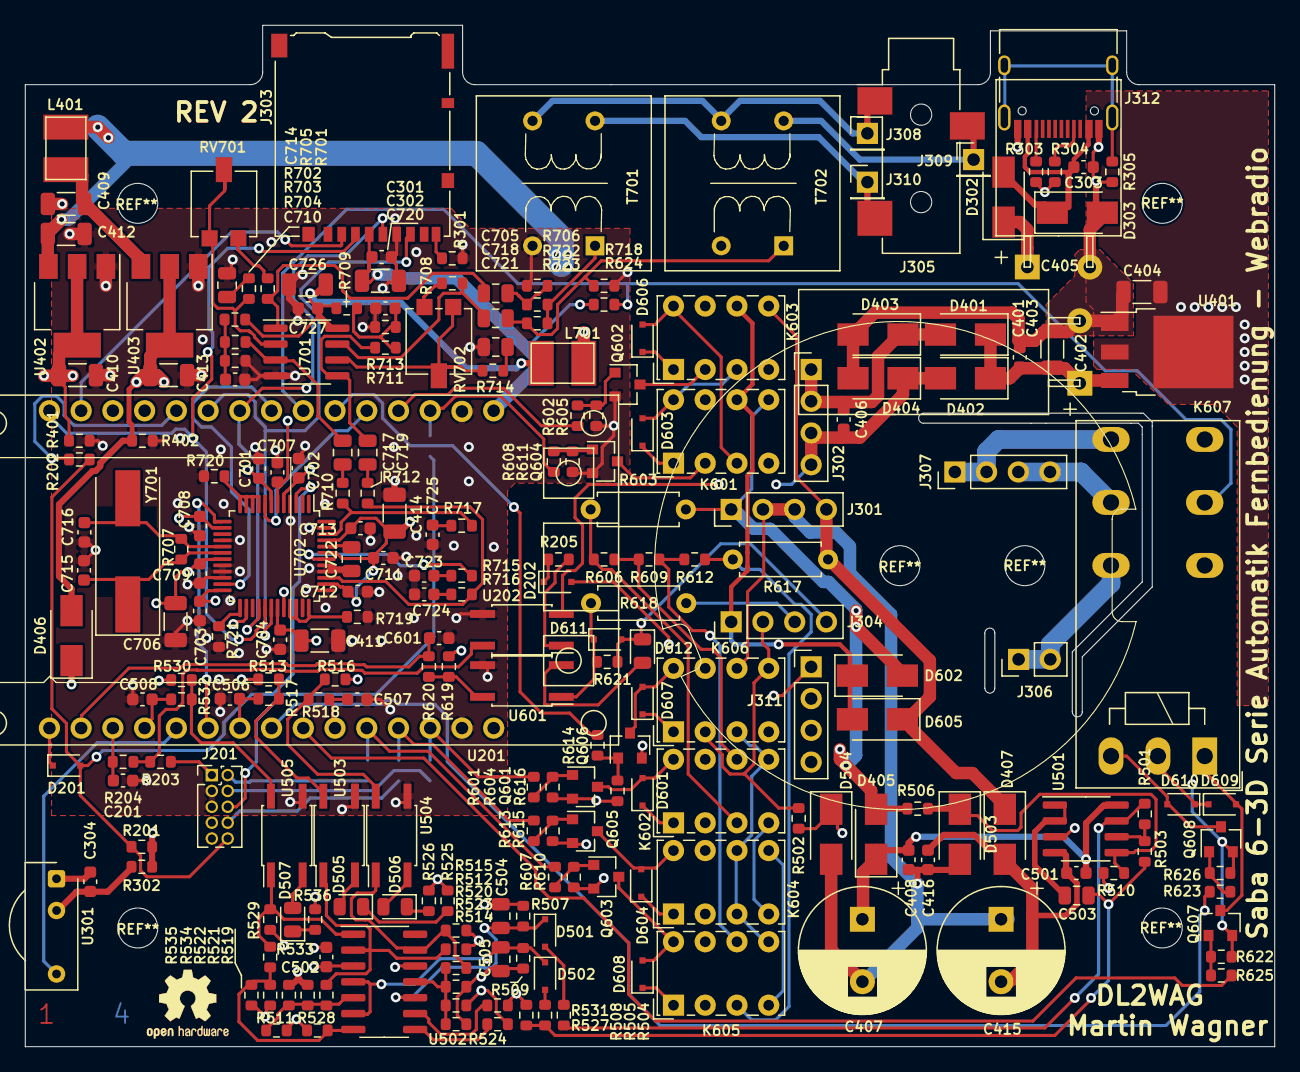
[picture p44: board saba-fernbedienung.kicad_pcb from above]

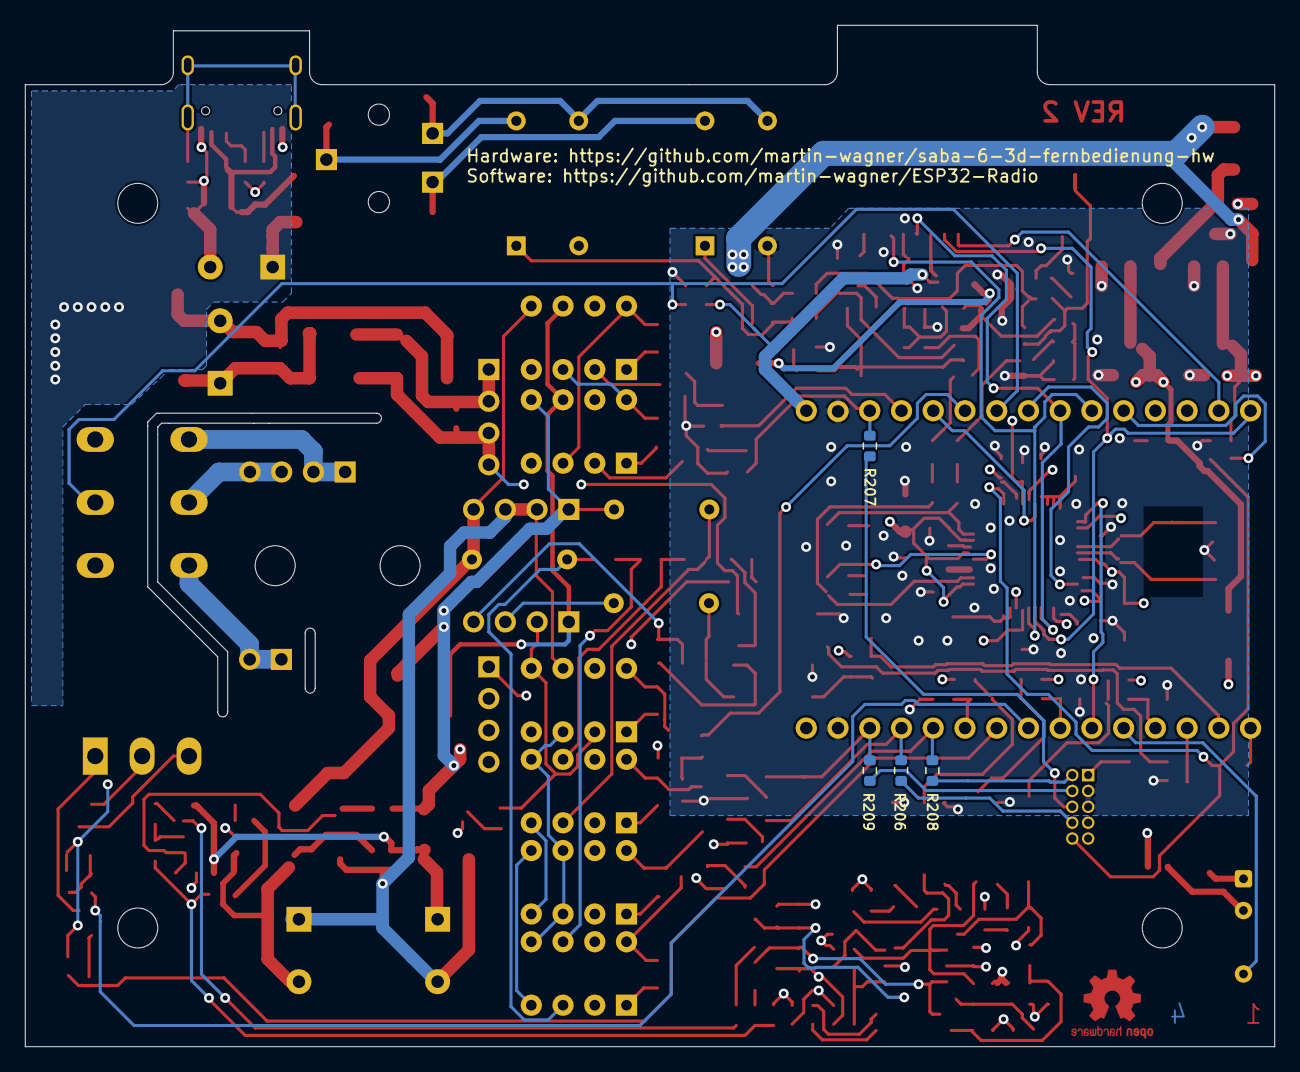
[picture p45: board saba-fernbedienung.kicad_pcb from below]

Board: 4 copper layers, 100.0 x 81.8 mm, 237 parts (4 on the bottom side), 148 nets.

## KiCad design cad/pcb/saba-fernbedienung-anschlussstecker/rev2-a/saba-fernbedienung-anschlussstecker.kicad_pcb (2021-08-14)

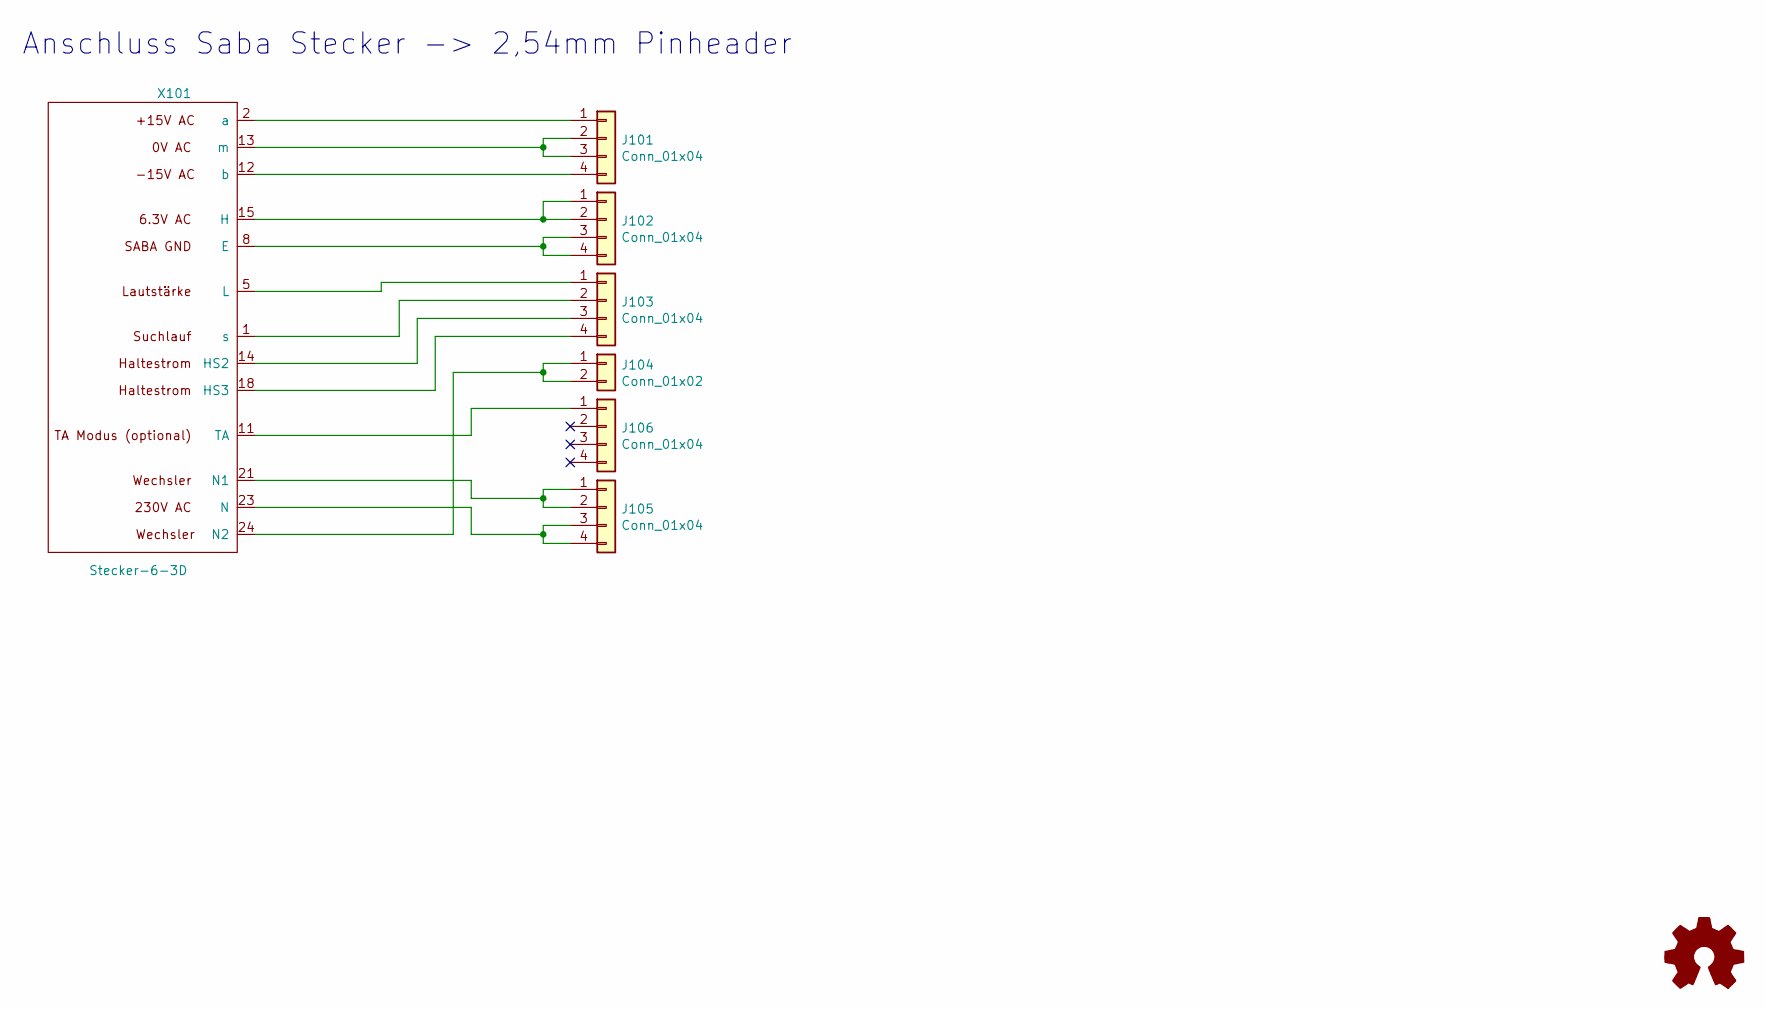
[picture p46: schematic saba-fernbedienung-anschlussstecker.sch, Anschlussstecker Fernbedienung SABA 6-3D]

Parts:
J101, J102, J103, J105, J106: Conn_01x04; PinHeader_1x04_P2.54mm_Vertical
J104: Conn_01x02; PinHeader_1x02_P2.54mm_Vertical
X101: Stecker-6-3D; stecker-6-3d

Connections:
unnamed: J101.1, X101.2 (a)
unnamed: J101.2, J101.3, X101.13 (m)
unnamed: J101.4, X101.12 (b)
unnamed: J102.1, J102.2, X101.15 (H)
unnamed: J102.3, J102.4, X101.8 (E)
unnamed: J103.1, X101.5 (L)
unnamed: J103.2, X101.1 (s)
unnamed: J103.3, X101.14 (HS2)
unnamed: J103.4, X101.18 (HS3)
unnamed: J104.1, J104.2, X101.24 (N2)
unnamed: J105.1, J105.2, X101.21 (N1)
unnamed: J105.3, J105.4, X101.23 (N)
unnamed: J106.1, X101.11 (TA)

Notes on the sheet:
Anschluss Saba Stecker -> 2,54mm Pinheader

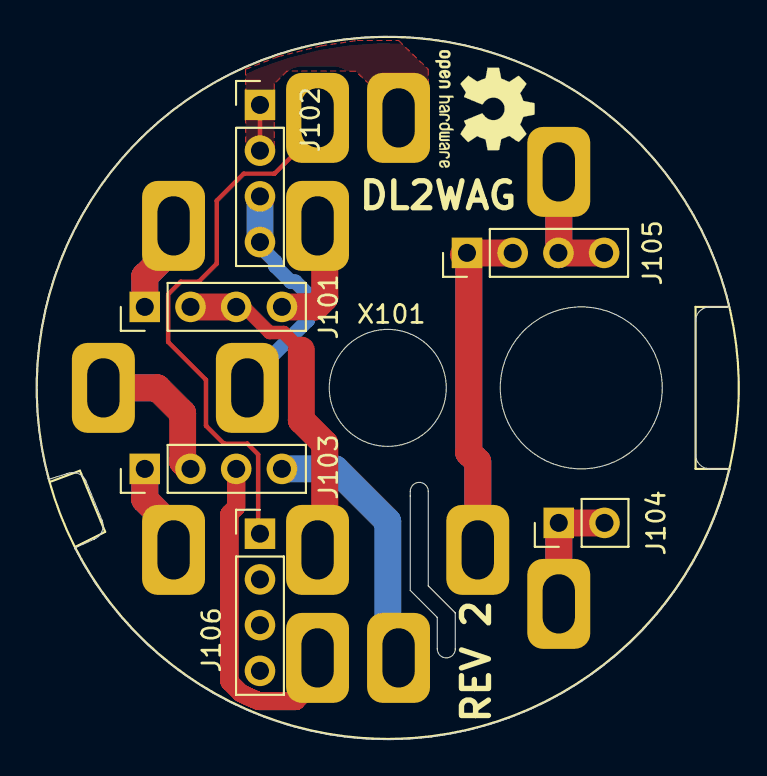
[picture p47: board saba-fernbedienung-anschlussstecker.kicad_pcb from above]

Board: 2 copper layers, 38.5 x 39.1 mm, 7 parts (0 on the bottom side), 13 nets.

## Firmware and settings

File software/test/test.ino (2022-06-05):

/*
  Saba Web Radio Hardware Testfunktionen
  - Lesen der Eingaenge
  - Steuern von Suchlauf, Lautstaerke, Mute
  per serieller Schnittstelle

  - schreibt "Input n changed x -> y" bei Input Toggle
  - wartet auf Eingabe "x\n" fuer Output Toggle 
*/

#include <string.h>
#include <array>

using namespace std;

class Saba_gpio {
  public:

    Saba_gpio() {
      
      outputs[Gpio_out_idx::VOLUME_UP].idx    = 15; 
      outputs[Gpio_out_idx::VOLUME_DOWN].idx  = 2; 
      outputs[Gpio_out_idx::MUTE].idx         = 16; 
      outputs[Gpio_out_idx::SEARCH_FAST].idx  = 12; 
      outputs[Gpio_out_idx::SEARCH_LEFT].idx  = 13; 
      outputs[Gpio_out_idx::SEARCH_RIGHT].idx = 14; 
      outputs[Gpio_out_idx::POWER_SET].idx    = 26; 
      outputs[Gpio_out_idx::POWER_RESET].idx  = 25; 

      inputs[Gpio_in_idx::DIRECTION].idx      = 27;
      inputs[Gpio_in_idx::SLOW].idx           = 33;
      inputs[Gpio_in_idx::FAST].idx           = 34;
      inputs[Gpio_in_idx::COIL].idx           = 36;
      inputs[Gpio_in_idx::TA].idx             = 39;
      
    };
  
    //output pin idx
    enum Gpio_out_idx {
      VOLUME_UP = 0,
      VOLUME_DOWN,
      MUTE,
      SEARCH_FAST,
      SEARCH_LEFT,
      SEARCH_RIGHT,
      POWER_SET,
      POWER_RESET,

      OUT_COUNT
    };
    
    class Output {
      public:
        uint8_t idx;
        bool current = false;
        bool last = false;
    };
    array<Output, Gpio_out_idx::OUT_COUNT> outputs;
    
    //input
    enum Gpio_in_idx {
      DIRECTION = 0,
      SLOW,
      FAST,
      COIL,
      TA,

      IN_COUNT
    };
    class Input {
      public:
        uint8_t idx;
        bool current = false;
        bool last = false;
    };
    array<Input, Gpio_in_idx::IN_COUNT> inputs;
    

} saba_gpio;


const char* inmsg = "Input %d changed: %d -> %d";
const char* outmsg = "Output %d changed: %d -> %d";

// the setup routine runs once when you press reset:
void setup() 
{
  //serial
  Serial.begin(115200);

  //outputs 
  for (auto &output : saba_gpio.outputs) {
    pinMode(output.idx, OUTPUT);  
    digitalWrite(output.idx, output.current);
  }
  //inputs  
  for (auto &input : saba_gpio.inputs) {
    pinMode(input.idx, INPUT);  
  }

  Serial.println("\n#######################\nSaba Webradio GPIO Test\n#######################");
}

// the loop routine runs over and over again forever:
void loop() 
{
  bool changed = false;
  int i;
  //string str; nope, Arduino hat keinen STL string
  char string[100];
  
  for (auto &input : saba_gpio.inputs) {
    input.current = digitalRead(input.idx);
    
    //entprellung in Hardware
    if (input.current != input.last) {
      snprintf(string, sizeof(string), inmsg, input.idx, input.last, input.current);
      Serial.println(string);
      changed = true;
    }
    
    input.last = input.current;
  }
  if (changed) {

  }

  

  if (Serial.available() > 0){  //Looking for incoming data

    Serial.readBytesUntil('\n', string, sizeof(string));
    
    auto idx = atoi(string);
    
    for (auto &output : saba_gpio.outputs) {
      if (output.idx == idx) {
        output.current = !output.last;
        digitalWrite(idx, output.current);
        snprintf(string, sizeof(string), outmsg, output.idx, output.last, output.current);
        Serial.println(string);
        
        output.last = output.current;
        break; //found
      }
    }

  }
  
  delay(1);
}

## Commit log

2021-01-11 Add: Anschlussstecker
    [saba-fernbedienung-anschlussstecker-B_Cu.gbr, saba-fernbedienung-anschlussstecker-B_Mask.gbr, saba-fernbedienung-anschlussstecker-Edge_Cuts.gbr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]
2021-01-11 Add: Controller
    [1-microcontroller.sch, 2-steckverbinder.sch, saba-fernbedienung.kicad_pcb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]
2021-01-13 Add: Steuerschaltung, Codec, Audio
    [1-microcontroller.sch, 2-steckverbinder.sch, 3-spannungsversorgung.sch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]
2021-01-13 Fix: Div. DRC
    [1-microcontroller.sch, 2-steckverbinder.sch, 3-spannungsversorgung.sch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]
2021-01-13 New: Bauteil - Pad Zuordnungen
    [1-microcontroller.sch, 2-steckverbinder.sch, 3-spannungsversorgung.sch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]
2021-01-13 Fix: uC Gehaeuse
    [1-microcontroller.sch, saba-fernbedienung.csv]
2021-01-13 Add: Bauteiltypen Digikey...
    viele Bauteile von WE da hoffentlich lange gueltig...
    [1-microcontroller.sch, 2-steckverbinder.sch, 3-spannungsversorgung.sch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]
2021-01-14 Change: Relais SMT -> THT, Sicherung PCB
    [1-microcontroller.sch, 2-steckverbinder.sch, 3-spannungsversorgung.sch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]
2021-01-16 PCB: Alle Leitungen verlegt
    [2-steckverbinder.sch, 6-audio.sch, saba-fernbedienung.kicad_pcb]
2021-01-16 Fix: DRC Fehler
    [saba-fernbedienung.kicad_pcb]
2021-01-16 Add: Position Bauteilnummern Druck
    [saba-fernbedienung.kicad_pcb]
2021-01-16 Change: Position Steckerpins
    [saba-fernbedienung-anschlussstecker.kicad_pcb]
2021-01-16 Fab Layer
    [3-spannungsversorgung.sch, 6-audio.sch, saba-fernbedienung.kicad_pcb]
2021-01-16 Add: Herstellungsdaten
    [1-microcontroller.sch, 2-steckverbinder.sch, 3-spannungsversorgung.sch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]
2021-01-21 Fix: Opamp zweifach
    [3-spannungsversorgung.sch, 4-suchlauf-in.sch, saba-fernbedienung.kicad_pcb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]
2021-04-10 Add: Doku
    [stueckliste.ods]
2021-06-20 Add: Vermessen von div. Uebertragern...
    da DC/DC Wandler EMV bei Radioempfang FM deutlich hoerbar ist und ohne haben wir eine Masseschleife.
2021-08-14 New: Stecker rev2
    unveraendert aus rev1
    [saba-fernbedienung-anschlussstecker.kicad_pcb, saba-fernbedienung-anschlussstecker.sch]
2021-08-14 Fix: Stecker
    - Durchmesser Mittelloch groesser
    - Position Befestigungsloch weiter rechts
    - Position Pin15 korrigiert
    - Pin11 hinzugefuegt. Ist in der Steckdose nicht belegt.
    [saba-fernbedienung-anschlussstecker.kicad_pcb, saba-fernbedienung-anschlussstecker.sch]
2021-08-14 New: Controller V2
    [1-microcontroller.sch, 2-steckverbinder.sch, 3-spannungsversorgung.sch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]
2021-08-14 ToDo-s bearbeitet
    [1-microcontroller.sch, 2-steckverbinder.sch, 3-spannungsversorgung.sch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]
2021-08-14 Change: Bauteilbezeichner
    [1-microcontroller.sch, 2-steckverbinder.sch, 3-spannungsversorgung.sch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]
2021-08-17 alle Bauteile platziert
    [1-microcontroller.sch, 5-fernbedienung.sch, saba-fernbedienung.kicad_pcb]
2021-08-18 Controller Rev2 fertig
    [4-suchlauf-in.sch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]
2022-06-05 Add: Testsoftware Arduino ESP32
2022-06-05 Update NP, Fix ToDo-s
    [1-microcontroller.sch, 2-steckverbinder.sch, 3-spannungsversorgung.sch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]
2022-08-08 Add: Gerbers
    [saba-fernbedienung-anschlussstecker-B_Cu.gbr, saba-fernbedienung-anschlussstecker-B_Mask.gbr, saba-fernbedienung-anschlussstecker-Edge_Cuts.gbr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]
